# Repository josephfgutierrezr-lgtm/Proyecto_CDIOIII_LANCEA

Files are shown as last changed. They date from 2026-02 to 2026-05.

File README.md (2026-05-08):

# 🎯 Proyecto LANCEA: Jabalina Inteligente (CDIO III)

> 🌐 **¡Descubre la presentación interactiva!** 
> Visita la **[Página Oficial del Proyecto LANCEA](https://josephfgutierrezr-lgtm.github.io/Proyecto_CDIOIII_LANCEA/)** para ver el resumen técnico, la arquitectura del sistema y el equipo de desarrollo.

¡Bienvenidos al repositorio oficial del **Proyecto LANCEA**! 

Este espacio documenta el desarrollo integral de un dispositivo deportivo inteligente enfocado en el atletismo. Aquí encontrarás desde la gestión del proyecto hasta los manuales técnicos, hardware, firmware y el entorno de visualización de datos.

---

## 🚀 ¿Qué es LANCEA?
**LANCEA** es un dispositivo electrónico embebido diseñado para integrarse en una jabalina deportiva. Su propósito principal es capturar, procesar y transmitir datos biomecánicos y cinemáticos en tiempo real durante el lanzamiento. 

Al transformar un implemento deportivo tradicional en una herramienta de análisis de datos, LANCEA busca proporcionar retroalimentación cuantitativa para mejorar la técnica y el rendimiento de los atletas.

## 💡 Motivación y Justificación
El deporte de alto rendimiento exige precisión. Tradicionalmente, el análisis del lanzamiento de jabalina depende de la observación visual o de costosos sistemas de cámaras externas. LANCEA nace de la necesidad de democratizar el acceso a métricas precisas (aceleración, rotación, ángulos de ataque) integrando sensores directamente en el implemento. Esto permite una recolección de datos intrusiva mínima y un análisis de sistemas dinámicos mucho más cercano a la realidad física del atleta.

## 🎯 Objetivos
*   **Monitoreo Preciso:** Capturar datos de movimiento en múltiples ejes de manera continua durante la fase de aceleración y vuelo.
*   **Procesamiento Eficiente:** Integrar hardware de bajo consumo y alto rendimiento capaz de procesar la información sin latencia.
*   **Diseño Ergonómico:** Lograr que la adición del hardware no altere significativamente el centro de masa ni la aerodinámica natural de la jabalina.

## 🛠️ Retos Superados y Logros Técnicos
El desarrollo de hardware embebido para un entorno de alto impacto y velocidad presentó desafíos únicos:

*   **Optimización de Espacio y Peso:** Para mantener la integridad aerodinámica y el balance de la jabalina, el diseño prescindió de módulos de registro de datos en tarjeta SD. Esta decisión fue crucial para priorizar la reducción de peso y optimizar el espacio interno disponible.
*   **Comunicación de Sensores:** Se logró una integración exitosa de la unidad de medición inercial (IMU) BNO055. El núcleo de procesamiento se consolidó utilizando el microcontrolador ESP32-C3 SuperMini, estableciendo una comunicación I2C estable a través de los pines físicos 8 (SDA) y 9 (SCL).

## 📂 Estructura del Repositorio
El proyecto está organizado en las siguientes carpetas principales para separar el hardware, el software y la documentación de gestión:

*   📁 **`0_1 Gestion`**: Contiene toda la documentación administrativa del proyecto, incluyendo actas de reuniones, cronogramas, listas de materiales (BOM), costos y planeación maestra de las fases CDIO.
*   📁 **`0_2 Firmware`**: Código fuente desarrollado en C/C++ para el ESP32-C3 SuperMini. Incluye las librerías y rutinas necesarias para la lectura del IMU BNO055 vía I2C y el procesamiento de los datos inerciales.
*   📁 **`DASHBOARD`**: Archivos y scripts relacionados con la interfaz gráfica o panel de control utilizado para visualizar e interpretar los datos cinemáticos capturados por la jabalina.
*   📁 **`DEFINITION_DONE`**: Documentación sobre los criterios de aceptación (DoD - *Definition of Done*), estableciendo los requisitos de calidad y funcionalidad que debe cumplir cada entregable o módulo del proyecto.
*   📁 **`Hardware`**: Planos electrónicos, esquemas de conexión y diseño de integración física de los componentes, garantizando el balance y peso óptimo sin el módulo SD.
*   📁 **`PROTOCOLO_PRUEBAS`**: Procedimientos, metodologías y registros de validación utilizados para someter el dispositivo a pruebas de impacto, estabilidad de conexión y fiabilidad de captura de datos.
*   📁 **`Plantilla_checklist`**: Formatos y listas de chequeo estandarizadas para el control de calidad durante el ensamblasje del hardware y la revisión del código.

---
*¡Explora los directorios, revisa el código y descubre cómo la electrónica y el deporte se unen en LANCEA!*

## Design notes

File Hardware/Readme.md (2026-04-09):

# 🔧 Diseño de Hardware y Aviónica - LANCEA

Este directorio documenta la arquitectura electrónica, el diseño de PCB y la integración mecánica del sistema LANCEA. El hardware está diseñado bajo restricciones de **aerodinámica** (factor de forma cilíndrico <22mm) y **resistencia a impactos** (fuerzas >15g).

---

## 📐 Vista General del Dispositivo.

El sistema se compone de una **PCB tipo "Strip" (Regla)** de doble cara montada sobre un chasis amortiguado ("Sled") impreso en 3D.

[Render del Dispositivo Electrónico]([render_preview png](https://github.com/user-attachments/assets/35435e63-3988-4843-8b94-5bf8a7de0638))

### Especificaciones Físicas.
* **Dimensiones PCB:** 110mm x 20mm.
* **Diámetro del Chasis (Sled):** 24mm (ajustable según jabalina).
* **Peso Total (con batería):** ~45g.
* **Centro de Gravedad:** Ajustado al eje longitudinal para no alterar el vuelo.

---

## ⚡ Diagrama de Arquitectura.

El sistema utiliza una arquitectura de bus dual (I2C + SPI) para separar la adquisición de sensores (baja latencia) del almacenamiento masivo.

```mermaid
graph TD
    BMS[TP4056<br>Carga y Protección] --- BAT[Batería Li-ion 18650<br>3.7V / 2800mAh]
    BAT --> SW[Interruptor]
    SW --> LED[LED ON/OFF]
    LED --> ESP32[MCU:<br>XIAO ESP32C3<br>3.3V logging]
    
    subgraph I2C Bus [Sensores]
        ESP32 -- GPIO 6/7 --> BNO[IMU:<br>BNO055 / MPU6050<br>Acelerómetro + Giroscopio]
    end
    
    subgraph Interfaz Fisica [Interfaz Física]
        ESP32 -- GPIO 2 --> Buzzer[Buzzer]
    end

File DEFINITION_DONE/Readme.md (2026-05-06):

# 🚀 Definition of Done (DoD) — Proyecto LANCEA
**Versión:** 3.0 (Final) | **Fecha de actualización:** 2026-05-06
**Estado:** Finalizado y Consolidado | **Autor:** Joseph Fernando Gutierrez Reyes

---

## 🎯 Criterios de Aceptación Globales
Todos los módulos e iteraciones han cumplido estrictamente con los siguientes requisitos transversales para su consolidación final:

| # | Criterio | Estándar de Verificación | Estado |
|---|---|---|:---:|
| 1 | **Integridad del Firmware** | Compilación en entorno de producción sin *warnings*. | ✅ |
| 2 | **Validación Física** | Superación del protocolo de pruebas industrial con registro definitivo en `Bitacora_Trazabilidad.csv`. | ✅ |
| 3 | **Flujo de Git** | Pull Requests aprobados y fusionados en `main`. Commits bajo el estándar *Conventional Commits*. | ✅ |
| 4 | **Revisión de Pares** | Visto bueno técnico final por parte del asesor y validación de los miembros del equipo. | ✅ |
| 5 | **Sincronización Kanban** | Todas las tareas en estado "Done" en GitHub Projects con documentación y evidencia de integración adjunta. | ✅ |

---

## 🛠️ Criterios Técnicos Específicos Cumplidos

### 1. Firmware & Adquisición (FW)
Se garantizó la estabilidad del sistema embebido y la confiabilidad de la captura de señales cinemáticas tras las optimizaciones finales.

| Ref | Requisito Técnico | Parámetro de Éxito Alcanzado | Estado |
|---|---|---|:---:|
| **FW-01** | **Precisión Temporal** | Tasa de muestreo de 100Hz constante mediante **ISR (Interrupt Service Routine)**. Jitter (σ) < 1ms. | ✅ |
| **FW-02** | **Detección de Eventos** | Algoritmo de trigger por *Jerk* calibrado (> 50 m/s³) para inicio automático de captura de telemetría. | ✅ |
| **FW-03** | **Gestión de Memoria** | Estructuración de datos optimizada en memoria tras la decisión técnica de remover el módulo de tarjeta SD, reduciendo peso y evitando bloqueos de escritura. | ✅ |

### 2. Hardware & Integración Mecánica (HW)
Se validó la resistencia, el balance del centro de gravedad aerodinámico y el diseño electrónico del prototipo definitivo.

| Ref | Requisito Técnico | Parámetro de Éxito Alcanzado | Estado |
|---|---|---|:---:|
| **HW-01** | **Ajuste Mecánico** | Chasis Sled (PETG) con **O-Rings de compresión** instalados. Ajuste estructural sin vibración radial dentro del tubo. | ✅ |
| **HW-02** | **Dimensionamiento** | Ancho de PCB Strip ≤ 20mm insertada en la jabalina (Ø 24mm). Bus I2C operando correctamente en pines físicos 8 (SDA) y 9 (SCL) del ESP32-C3. | ✅ |
| **HW-03** | **Estabilidad de Voltaje** | Capacitores de desacoplo (100µF/0.1µF) instalados en la línea VCC principal para mitigar picos de consumo entre el microcontrolador y el sensor BNO055. | ✅ |

### 3. Sistema Integrado & Operación (MC)
Desempeño del sistema completo validado en pista, garantizando la recolección de datos y el flujo de energía.

| Ref | Requisito Técnico | Parámetro de Éxito Alcanzado | Estado |
|---|---|---|:---:|
| **MC-01** | **Autonomía y Recarga** | Operación continua validada (> 7 horas continuas). Módulo TP4056 plenamente accesible desde la sección trasera mediante USB-C sin necesidad de desmontar el chasis. | ✅ |
| **MC-02** | **Trazabilidad de Datos** | Paquetes de datos exportados con estructura matricial legible, sin huecos (gaps) y listos para su modelado y análisis en MATLAB. | ✅ |
| **MC-03** | **Feedback de Usuario** | Sistema de alertas sonoras (Buzzer) y visuales (LED de carga) funcional para indicar: Inicializado, Calibrado, Grabación en curso y Estado de Batería. | ✅ |

---

## 🏁 Cierre de Proyecto y Conformidad
El proyecto LANCEA se declara **Terminado y Consolidado**. No existen tareas pendientes, bloqueos técnicos ni implementaciones de hardware/firmware sin validar. Todos los criterios de exclusión históricos (código sin probar dinámicamente, alteraciones del punto de equilibrio, falta de protecciones antivibración o bloqueos por funciones como `delay()`) fueron mitigados satisfactoriamente, culminando en un prototipo funcional y listo para la recolección de datos en campo.

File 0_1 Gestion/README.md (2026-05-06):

# 📂 Gestión del Proyecto LANCEA:

Este directorio centraliza la documentación administrativa, planificación y análisis de requisitos del sistema **LANCEA** (Sistema de Monitoreo y Detección de Lanzamiento de Jabalina).

**Institución:** Universidad del Quindío.
**Programa:** Ingeniería Electrónica (Séptimo Semestre)  
**Ubicación:** Armenia, Quindío, Colombia.   
**Duración:** 2 Semestres (Fase I y II).
---

## 🎯 Alcance del Proyecto:

El objetivo es desarrollar un dispositivo embebido portátil capaz de medir parámetros cinemáticos críticos durante el entrenamiento de lanzamiento de jabalina.

### Objetivos Específicos (KPIs)
1.  **Captura de Aceleración:** Medición en 3 ejes con rango de $\pm16~g$.
2.  **Cálculo de Velocidad:** Estimación de velocidad de salida entre 15m/s y 35m/s.
3.  **Estimación de Distancia:** Proyección teórica del tiro entre 35m y 90m.
4.  **Autonomía:** Operación continua $\ge 6$ horas sin recarga.
5.  **Costo:** Presupuesto total entre \$800k y \$1.2M COP.

---

## 📅 Roadmap de Implementación:

El proyecto se divide en dos fases semestrales según los lineamientos académicos:

### Fase 1: Hardware y Firmware Base (Semestre Actual)
| Semanas | Hito / Entregable | Estado |
| :--- | :--- | :--- |
| **1-4** | Adquisición de componentes y Setup inicial del ESP32. |🟢 Hecho |
| **5-8** | Integración de sensores (IMU/Velocidad), detección de evento y Pantalla OLED. |  🟢 Hecho |
| **9-12** | Implementación de almacenamiento local (MicroSD/SPIFFS). |🟢 Hecho |
| **13-16** |Pruebas de campo, calibración de sensibilidad y documentación final. | 🟢 Hecho |

### Fase 2: Conectividad y Servidor (Próximo Semestre)
* Despliegue de servidor local (Python/Flask).
* Sincronización WiFi y Base de Datos.
* Interfaz Web para visualización de historial.

---
## ⚙️ Matriz de Requisitos

### Requisitos Funcionales (RF)
* **RF-001:** Captura de aceleración ($\pm16g$, $\pm0.5~m/s^2$).
* **RF-002:** Captura de velocidad de lanzamiento.
* **RF-004:** Detección automática del evento de lanzamiento.
* **RF-005:** Almacenamiento local ("Black Box") para mín. 30 lanzamientos.
* **RF-006:** Transmisión asíncrona ("Store & Forward") al servidor.
* **RF-007:** Visualización inmediata de resultados en pantalla OLED.

### Requisitos No Funcionales (RNF)
* **RNF-003 Portabilidad:** Peso total $\le 1.5$ kg e integración aerodinámica.
* **RNF-005 Resistencia Ambiental:** Operación en clima de Armenia ($15^\circ C - 35^\circ C$, Humedad 60-95%).
* **RNF-012 Recuperabilidad:** Sistema "Offline-First" ante fallos de red WiFi.

---

## 💰 Presupuesto y Recursos

**Presupuesto Estimado:** \$800.000 - \$1.200.000 COP.

### Componentes Principales (BOM)
* **Microcontrolador:** ESP32 (Dual Core, WiFi/BT).
* **Sensores:** IMU BNO055 (Acelerómetro + Giroscopio). *Nota: Se utiliza IMU para cálculo de velocidad debido a limitaciones físicas del ultrasonido HC-SR04 en distancias >4m.*
* **Energía:** Batería LiPo/Li-Ion (3.7V).
* **Interfaz:** Pantalla OLED 0.91" (I2C) y Pulsador físico.

---

## ⚠️ Gestión de Riesgos y Restricciones
1.  **Conectividad:** La red WiFi en estadios no es garantizada. Se mitiga con almacenamiento en SD (RF-005).
2.  **Clima:** La alta humedad de Armenia requiere protección IP54 o uso de Silica Gel en la carcasa.
3. **Vibración:** El impacto de la jabalina requiere amortiguación interna en el chasis impreso en 3D.

---
*Documento basado en la especificación de requisitos v1.0 (Octubre 2025).*

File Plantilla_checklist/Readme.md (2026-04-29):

## CHECKLIST DE DEFINICIÓN DE HECHO (DoD) - LANCEA

Antes de cerrar esta tarea y moverla a "Done", certifico como ingeniero a cargo que he validado lo siguiente en el prototipo base:

### ⚡ 1. HARDWARE
- [x] **Esquemático/PCB:** Actualizado en la carpeta `02_Hardware` sin errores de reglas de diseño (0 Errores DRC).
- [x] **Continuidad:** La placa pasó la prueba de cortos (0 cortos en pistas de potencia y buses I2C/SPI).
- [x] **Cero Parches:** No hay cables "voladores"; las conexiones del BNO055 están ruteadas o soldadas firmemente.
- [x] **Métricas:** El módulo TP4056 entrega voltaje de carga estable y el ESP32 recibe sus 3.3V lógicos dentro de la tolerancia exigida.

### 💻 2. FIRMWARE/SOFTWARE
- [x] **Compilación limpia:** El código de prueba (Hola Mundo) compila con 0 Errores y 0 Warnings en PlatformIO/Arduino.
- [x] **Código No-Bloqueante:** No se usa la función `delay()` que detenga la adquisición de datos de la IMU.
- [x] **Repositorio:** El código está subido a la rama principal de GitHub (Push realizado).
- [x] **Trazabilidad:** El Commit incluye la palabra clave para cerrar esta tarea (Ej: `Closes #ID`).

### ⚙️ 3. MECÁNICA / DISEÑO 3D
- [x] **Archivos Fuente:** El diseño base del chasis cilíndrico ("Sled") está en la subcarpeta `Mechanical/`.
- [x] **Archivos de Fabricación:** El `.STL` final está subido y listo para imprimir en PETG/PLA+.
- [x] **Tolerancia:** Se validó matemáticamente que la PCB tipo "Strip" (20mm de ancho) cabe perfectamente en el diámetro interno de 24mm diseñado para la jabalina.

### 📋 4. GESTIÓN Y PRUEBAS
- [x] **BOM Actualizado:** Todos los componentes adquiridos (ESP32, BNO055, TP4056, Batería 14500) están costeados en la Lista de Materiales.
- [x] **Protocolo de Pruebas:** Se diligenció el archivo Excel Oficial de Pruebas (Test Report) para los subsistemas actuales.
- [x] **Aprobación:** La columna de "Estado Final" en el Excel de pruebas dice "✅ PASS" con datos reales (sin subjetividades).

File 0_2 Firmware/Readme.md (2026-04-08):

# ⚡ Firmware LANCEA (ESP32 Core)

Este directorio contiene el código fuente C++ para el microcontrolador XIAO ESP32C3. El firmware implementa la lógica de adquisición de datos de alta velocidad, gestión de almacenamiento y transmisión inalámbrica bajo una arquitectura de **Máquina de Estados Finitos (FSM)**.

---

## 🛠️ Entorno de Desarrollo
En esta sección se definen las herramientas, plataforma y dependencias necesarias para compilar, cargar y mantener el firmware del sistema, lo cual asegura reproducibilidad en el entorno de desarrollo entre los miembros del equipo.

* **Platform:** PlatformIO (Recomendado) o Arduino IDE.
* **Framework:** Arduino.
* **Board:** `lolin_s2_mini` / `esp32dev` (Ajustar según hardware real).

### Dependencias (Librerías)
Las siguientes librerías son obligatorias para compilar el proyecto y permiten la correcta interacción con los sensores, pantalla y sistema de almacenamiento:
1.  **Adafruit BNO055** (Driver del sensor IMU).
2.  **Adafruit Unified Sensor** (Base para sensores Adafruit).
3.  **Adafruit SSD1306** (Controlador de Pantalla OLED).
4.  **Adafruit GFX** (Gráficos para pantalla).
5.  **SdFat** (Gestión optimizada de tarjeta SD via SPI).

---

## 🔌 Pinout (Mapa de Conexiones)

A continuación se presenta la asignación de pines utilizada en el sistema. Esta configuración está definida en el archivo config.h y es fundamental para garantizar la correcta conexión entre el microcontrolador y los periféricos.

| Pin XIAO ESP32-C3 | MPU6050 | BNO055 | Buzzer |
| :--- | :---: | :---: | :---: |
| **3V3** | VCC | VCC | -- |
| **GND** | GND | GND | GND |
| **D4 (GPIO6)** | SDA | SDA | -- |
| **D5 (GPIO7)** | SCL | SCL | -- |
| **D3 (GPIO5)** | INT | -- | -- |
| **D6 (GPIO21)** | -- | -- | SIGNAL |
| **GND** | AD0 | ADR | -- |

## 🧠 Lógica del Sistema (Arquitectura)
En esta sección se describe el comportamiento del firmware a nivel lógico, el sistema no opera mediante un bucle tradicional, sino mediante una Máquina de Estados Finitos (FSM), lo que permite controlar de forma estructurada los eventos, optimizar recursos y garantizar la integridad de los datos durante el proceso de adquisición.

### Diagrama de Flujo de Estados

```mermaid
stateDiagram-v2
    [*] --> INIT
    INIT --> ERROR : Fallo en Sensor/SD
    ERROR --> [*]
    INIT --> IDLE : Todo OK
    
    IDLE --> ARMADO : Pulsación Corta Botón
    ARMADO --> GRABANDO : Aceleración > 4G (Lanzamiento)
    
    state GRABANDO {
        [*] --> LOGGING
        LOGGING --> LOGGING : 100Hz Loop
    }
    
    GRABANDO --> GUARDADO : Tiempo > 10s o Silencio
    GUARDADO --> IDLE : Archivo Cerrado
    
    IDLE --> WIFI_SYNC : Pulsación Larga Botón (3s)
    WIFI_SYNC --> IDLE : Carga Completa

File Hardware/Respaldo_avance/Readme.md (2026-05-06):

# 🔬 Pruebas de Concepto (PoC) - Semestre Anterior

Este documento recopila la investigación preliminar y las validaciones en hardware realizadas durante la fase de viabilidad del proyecto **LANCEA**. Estos resultados justifican la arquitectura técnica actual del sistema.

---

## 📐 1. Validación Dimensional y Mecánica

Uno de los mayores retos del proyecto era asegurar que la electrónica pudiera operar dentro de las estrictas restricciones aerodinámicas de un tubo deportivo, sin alterar el centro de gravedad.

### Objetivo de la Prueba
Validar que es posible ensamblar un sistema de adquisición de datos en una PCB con un ancho útil inferior al diámetro interno de una jabalina estándar.

### Resultados
Se logró diseñar e integrar un prototipo funcional que respeta el factor de forma cilíndrico, asegurando que la baquelita y la batería se deslizan sin tensión mecánica dentro del diámetro de prueba (aprox. 24mm - 25mm).

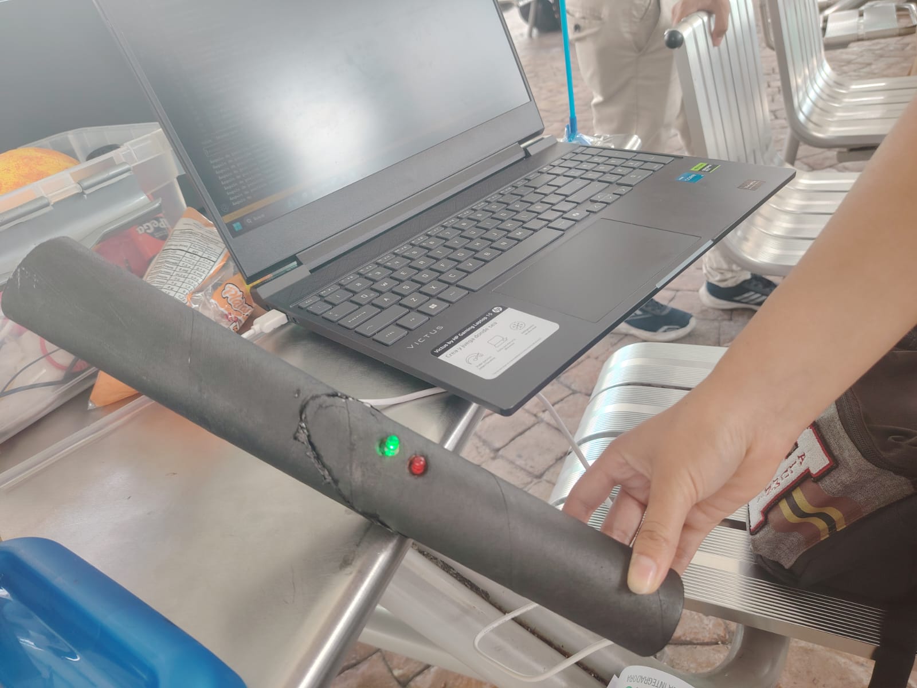
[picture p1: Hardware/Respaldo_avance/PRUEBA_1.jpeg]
Prueba de Diámetro y Ensamble


---

## ⚡ 2. Medición de Ángulo y Autonomía Energética

Para capturar la cinemática del vuelo, era crítico probar la viabilidad de estimar ángulos usando sensores inerciales y garantizar que el sistema de energía soportara una sesión completa de entrenamiento.

### Objetivo de la Prueba
1.  **Cinemática:** Leer el ángulo de inclinación estático utilizando un sensor MPU6050 inicial.
2.  **Energía:** Medir la tasa de descarga del sistema completo operando de forma continua.

### Resultados
* **Ángulo:** Se obtuvieron lecturas coherentes de inclinación (Pitch/Roll) procesando los datos crudos del sensor en el microcontrolador.
* **Autonomía:** El sistema demostró una operación continua superior a las expectativas iniciales utilizando celdas de Li-Ion, validando que una sola carga es suficiente para múltiples horas de recolección de datos en campo.

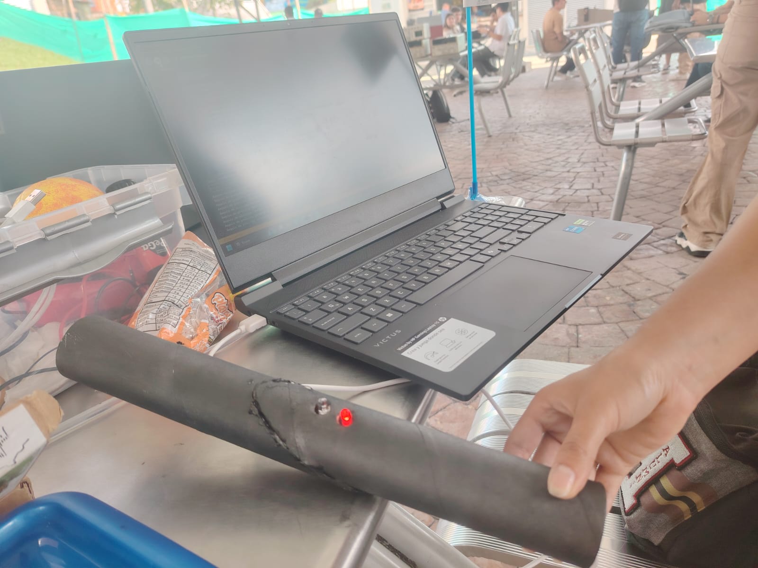
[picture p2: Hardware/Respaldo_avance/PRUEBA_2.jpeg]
Prueba de Ángulo y Autonomía


---

## 🚀 Conclusión y Transición a Fase 2

Los resultados exitosos de estas pruebas preliminares permitieron:
1.  Confirmar la viabilidad física del chasis impreso en 3D ("Sled").
2.  Justificar el *upgrade* del sensor MPU6050 al **BNO055** actual, para obtener cuaterniones por hardware y evitar el "Gimbal Lock" en vuelos dinámicos.
3.  Establecer la arquitectura de energía final basada en baterías 14500/18650 con gestión TP4056.

Estos antecedentes son la base sobre la cual se está desarrollando el firmware y hardware de alta velocidad de la versión actual.

---

## 🛠️ 3. Implementación Actual (Fase 2)

A partir de las conclusiones de las pruebas de concepto, se procedió a la materialización del hardware definitivo, logrando integrar con éxito las mejoras propuestas:

### Ensamble de PCB Definitiva
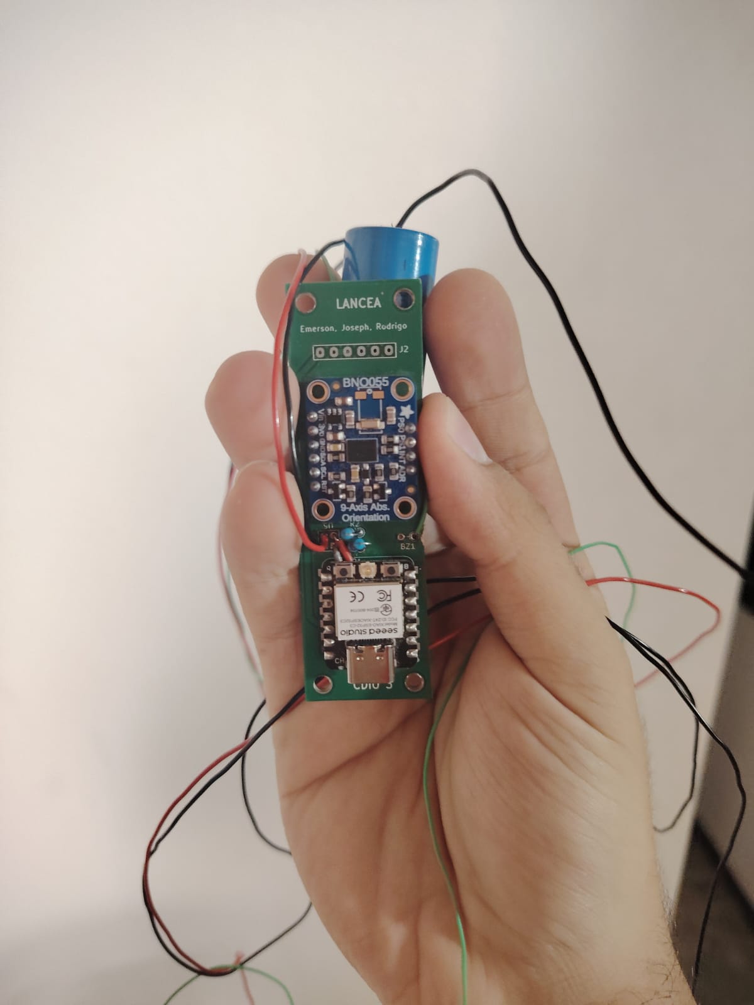
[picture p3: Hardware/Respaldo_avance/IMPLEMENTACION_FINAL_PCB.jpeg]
Implementación Final PCB

* **Avance:** Montaje exitoso de la PCB principal en formato "Strip". Se consolida el salto tecnológico integrando el microcontrolador **XIAO ESP32-C3** y el sensor inercial **BNO055** de alta precisión, respetando estrictamente el ancho máximo permitido por el diámetro interno de la jabalina.

### Integración Estructural del Sistema de Energía
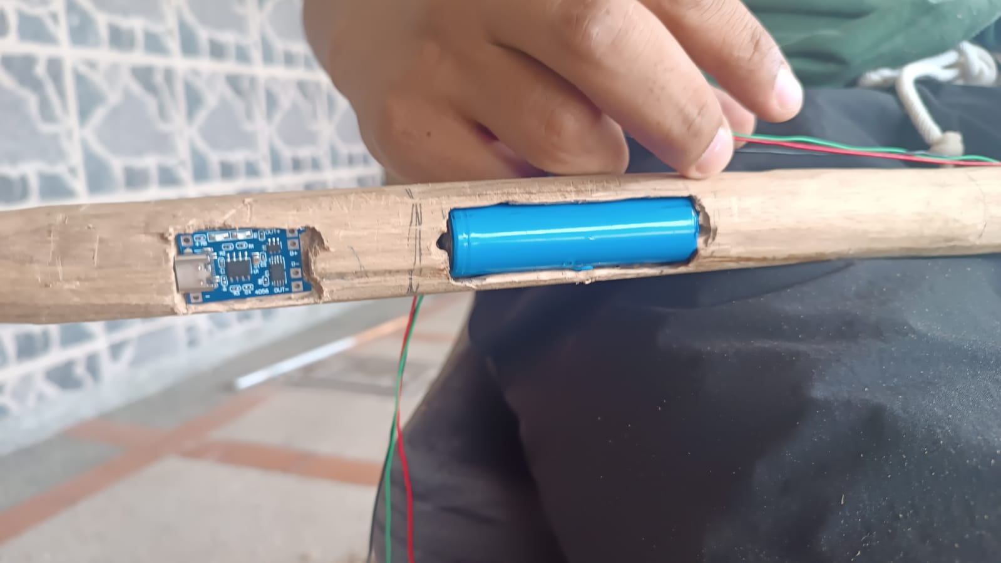
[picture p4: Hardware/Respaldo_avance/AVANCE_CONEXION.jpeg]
Avance de Conexión

* **Avance:** Mecanizado e integración del sistema de alimentación en un prototipo estructural (simulador de madera). Se comprueba el ajuste perfecto de la **batería Li-ion** y el módulo de carga **TP4056** en los compartimentos empotrados, garantizando que los componentes no sobresalgan del perfil cilíndrico ni comprometan la aerodinámica o el centro de masa del proyectil.

### Validación del Sistema de Carga Integrado
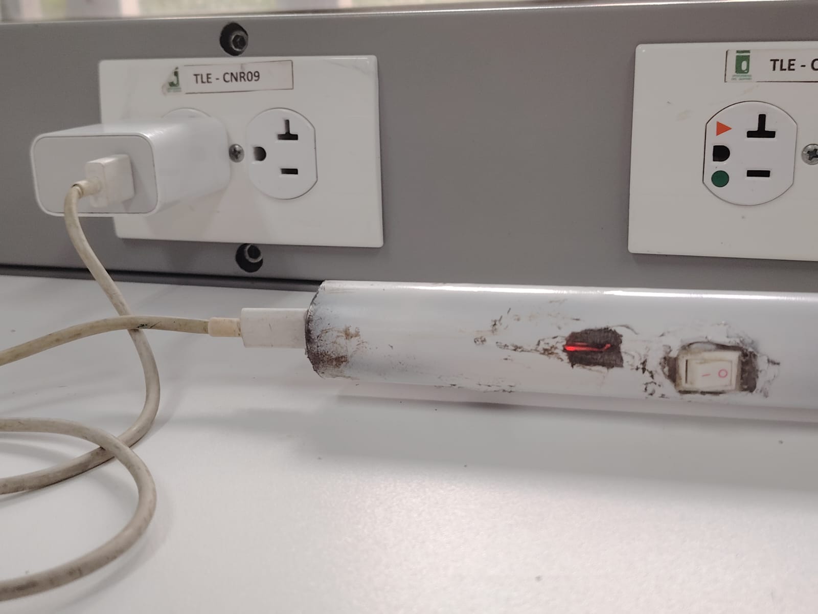
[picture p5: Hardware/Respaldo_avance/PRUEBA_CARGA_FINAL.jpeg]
Prueba de Carga Final

* **Avance:** Verificación funcional del módulo de gestión de energía operando directamente desde su alojamiento tubular. La prueba demuestra que la interfaz de carga es perfectamente accesible desde el exterior de la carcasa. El indicador LED rojo confirma el flujo de corriente activo hacia la batería, y se valida la accesibilidad del interruptor mecánico integrado para aislar el circuito principal en campo.

---

## 🎯 4. Trazabilidad y Ensamblaje Final

Como parte del cierre de la fase de integración, se realizaron las inspecciones físicas y estructurales sobre el dispositivo completamente ensamblado, verificando que las modificaciones de hardware cumplan con los requerimientos deportivos de la disciplina.

### Verificación del Punto de Equilibrio
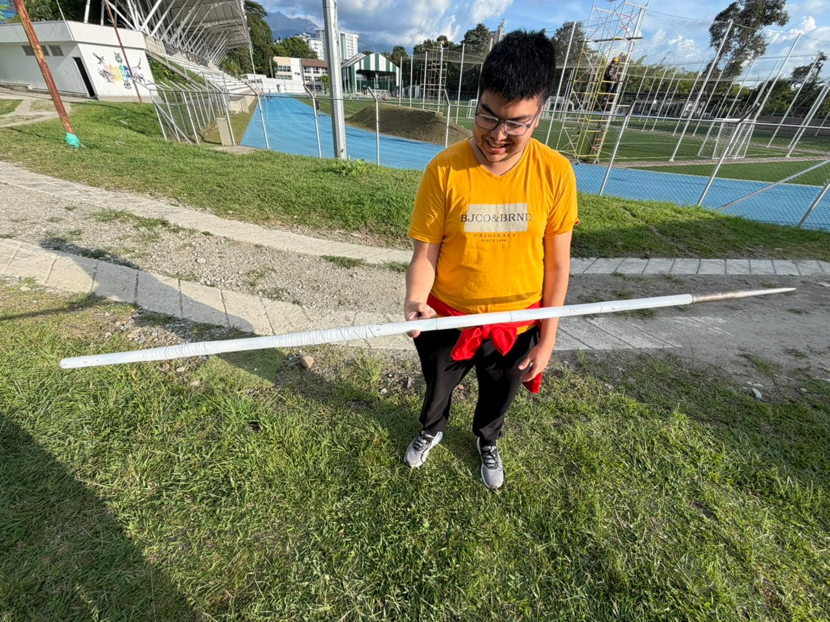
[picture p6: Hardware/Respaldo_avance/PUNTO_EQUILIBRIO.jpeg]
Punto de Equilibrio

* **Avance:** Comprobación exitosa del centro de gravedad de la jabalina. La distribución estratégica de los componentes internos, sumada a la decisión de retirar el módulo de registro de datos por tarjeta SD para optimizar el espacio y reducir el peso general, permitió mantener el balance aerodinámico estricto necesario para un vuelo estable.

### Accesibilidad del Módulo de Carga Trasero
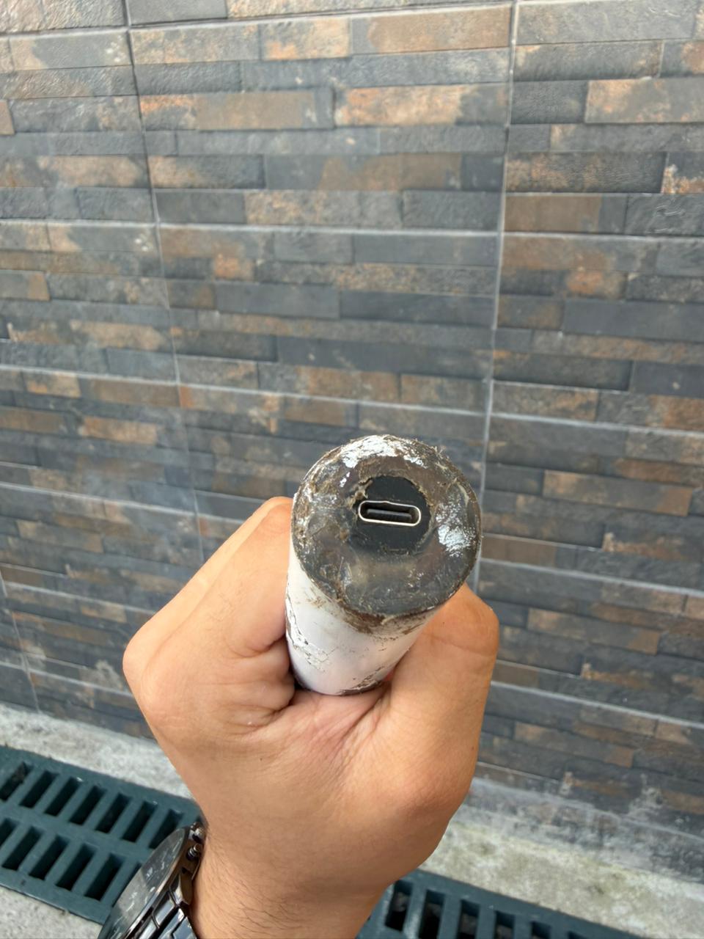
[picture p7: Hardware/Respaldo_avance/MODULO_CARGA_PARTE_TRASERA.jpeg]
Módulo de Carga Parte Trasera

* **Avance:** Integración del puerto de carga USB-C en la sección posterior de la jabalina. Este diseño expone la interfaz de recarga del módulo de energía de manera segura, facilitando la conexión mediante cables estándar entre sesiones de lanzamiento sin necesidad de manipular o desmontar la estructura principal.

### Consolidación del Prototipo LANCEA
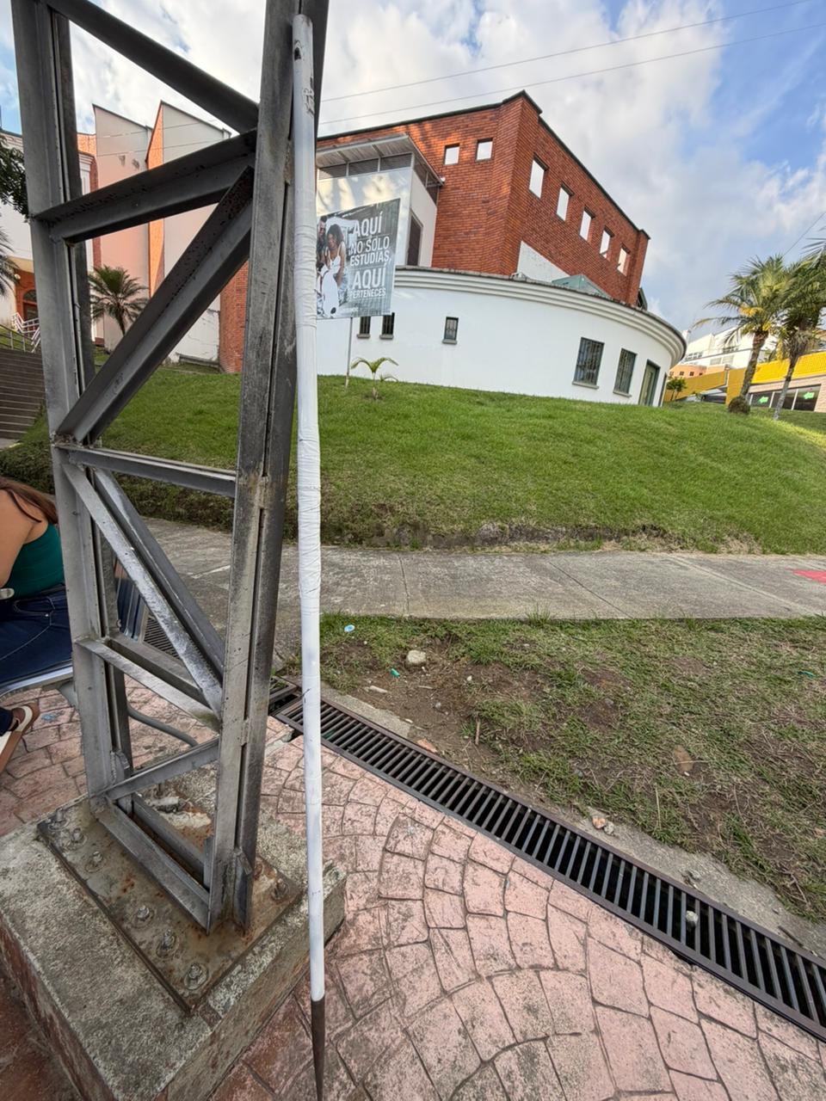
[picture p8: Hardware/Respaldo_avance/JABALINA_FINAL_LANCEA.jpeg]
Jabalina Final LANCEA

* **Avance:** Vista general del prototipo inteligente estructurado y sellado. El dispositivo presenta un perfil continuo y liso, confirmando que la instrumentación interna no compromete el factor de forma externo, dejando el equipo listo para la ejecución de pruebas dinámicas y recolección de datos en pista.

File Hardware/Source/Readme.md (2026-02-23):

# ⚡ Diseño Electrónico y PCB - LANCEA

Este directorio contiene los archivos fuente del diseño de la PCB para el proyecto.

## 🛠 Especificaciones
* **Software:** KiCad 9.0
* **Capas:** 2 capas
* **Tecnología:** Componentes Through-hole (THT) para mayor robustez mecánica.

## 📂 Estructura de Archivos
* **Esquemático:** `.kicad_sch` (Lógica del circuito).
* **PCB Layout:** `.kicad_pcb` (Diseño físico de la placa).
* **Proyecto:** `.kicad_pro` (Archivo maestro).
* **Librerías y 3D:** Carpetas de símbolos, huellas y modelos STEP.

## 📥 ¿Cómo descargar los archivos?

Si necesitas descargar un archivo individual (como el esquemático o la PCB) directamente desde el navegador:

1. Haz clic sobre el archivo que deseas (ej. `.kicad_pcb`).
2. En la esquina superior derecha de la vista del archivo, haz clic en los **tres puntos (`...`)**.
3. Selecciona la opción **Download**.
4. **Atajo de teclado:** También puedes presionar `Ctrl` + `Shift` + `S` mientras visualizas el código del archivo para guardarlo automáticamente.

> **Nota:** Se recomienda descargar todo el repositorio como un `.zip` desde la página principal para mantener la integridad de las librerías y modelos 3D.

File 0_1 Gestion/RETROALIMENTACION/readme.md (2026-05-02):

# Registro Integrado de Retroalimentación, Protocolos de Prueba y Definition of Done (DoD)
**Proyecto:** LANCEA - Sistema de Medición y Emulación para Atletas de Jabalina  
**Cliente / Usuario Final:** Entrenador y Atleta de la Liga de Atletismo del Quindío  
**Ingenieros a Cargo:** Joseph Fernando Gutiérrez, Emerson Santiago Córdoba, Johan Rodrigo Piedrahita

---

## 1. Introducción y Justificación
Este documento detalla cómo las necesidades empíricas y cualitativas del usuario final (entrenador y atleta de jabalina) fueron traducidas en requerimientos técnicos estrictos, historias de usuario medibles y validaciones cuantificables. El propósito de este registro es evidenciar que el desarrollo del dispositivo **LANCEA** siguió una ruta de ingeniería rigurosa (basada en métricas, metodologías ágiles y estándares industriales) descartando la improvisación y garantizando un producto funcional, ergonómico y preciso.

---

## 2. Historias de Usuario: La Voz del Cliente (Feedback)
El proceso de retroalimentación en campo nos permitió capturar las necesidades reales, las cuales fueron formalizadas en la **Matriz de Enfoque y Requisitos**:

* **HU-01 (Entrenador):** *Requiere ver la velocidad y ángulo de lanzamiento para corregir la técnica.* -> Prioridad P0. Define el uso del IMU y el procesamiento inercial.
* **HU-02 (Atleta):** *Exige que el sistema sea invisible dentro de la jabalina para no alterar su vuelo ni ergonomía.* -> Prioridad P0. Define los límites mecánicos del diseño, promoviendo la máxima reducción de peso y volumen.
* **HU-03 (Entrenador/Técnico):** *Necesita descargar datos en CSV sin cables y de forma inmediata para agilizar el análisis.* -> Prioridad P1. Se descartó el almacenamiento físico (memoria micro SD) para evitar problemas de espacio y peso adicional en la jabalina. En su lugar, se definió una arquitectura donde la información se envía y guarda directamente en archivos CSV desde la aplicación y la página web.
* **HU-04 (Investigación):** *Requiere un registro de 100 muestras/segundo para el análisis biomecánico.* -> Prioridad P0. Define la tasa de muestreo, rutinas de interrupción (ISR) y la transmisión estable de datos a la interfaz.
* **HU-05 (Usuario en campo):** *La batería debe durar al menos 6 horas para cubrir un entrenamiento completo.* -> Prioridad P1. Define el sistema de potencia.

---

## 3. Definition of Done (DoD): Estándares de Aceptación
Para asegurar que las decisiones tomadas cumplieran con la calidad exigida y no fueran validaciones subjetivas (ej. "funciona bien"), se estableció un **Definition of Done (DoD)** riguroso:

1.  **Cero Subjetividad:** Todas las validaciones deben arrojar valores numéricos (Voltios, Milímetros, Grados, Milisegundos).
2.  **Firmware (FW) y Software:** 
    * Tasa de muestreo de **100Hz exacta** garantizada por ISR (Interrupt Service Routine) con Jitter < 1ms, evitando el uso de retardos (`delay()`) que bloqueen la lectura.
    * Detección de lanzamiento por **Jerk calibrado (> 50 m/s³)**.
    * Transmisión íntegra de datos vía Wi-Fi (ESP32 como servidor local/AP) hacia la aplicación/página web para la generación automática del archivo CSV, garantizando cero pérdida de paquetes y eliminando la dependencia de hardware de almacenamiento extra (SD).
3.  **Hardware (HW) y Mecánica:** 
    * Ancho máximo de la PCB **≤ 20mm**.
    * Eliminación del módulo SD y sus componentes asociados, reduciendo drásticamente el peso y volumen final.
    * Uso de **O-Rings de compresión** en el chasis (Sled) de PETG para evitar vibración radial e impactos.
4.  **Sistema e Interacción (MC):** 
    * Feedback al usuario mediante **Buzzer** (alertas sonoras para encendido, calibración y conexión/grabación exitosa), solucionando la necesidad de interacción rápida.

---

## 4. Ejecución de Pruebas Industriales (Verificación de Requisitos)
Las historias de usuario y el DoD se validaron mediante los siguientes protocolos de prueba documentados, a cargo del ingeniero Joseph Gutierrez:

### 🛠️ Prueba Mecánica y Dimensional (TEST-MC-01 & TEST-HW-01)
* **Problema del Atleta (HU-02):** El dispositivo debe encajar perfectamente sin estorbar y ser lo más ligero posible.
* **Protocolo:** Se midió el diámetro interno de una jabalina profesional con calibrador Pie de Rey, obteniendo **25.2mm** (TEST-MC-01). 
* **Validación de PCB:** Gracias a la eliminación de la memoria SD, se optimizó la baquelita en KiCad definiendo un límite estricto. La medición final del ancho de la placa fue de **19.8mm** (TEST-HW-01). 
* **Resultado:** ✅ **PASS**. Se garantiza el encaje aerodinámico perfecto y se minimiza el peso añadido al implemento.

### 🔋 Prueba de Autonomía de Potencia (TEST-HW-02)
* **Problema del Usuario (HU-05):** El sistema debe durar una sesión de 6 horas.
* **Protocolo:** Se testeó una batería Li-Ion 14500 (1000mAh) con el ESP32 en modo activo continuo, transmitiendo datos vía web/app hasta el corte del BMS (3.0V).
* **Resultado:** ✅ **PASS**. El sistema operó ininterrumpidamente por **7 horas y 15 minutos**, superando holgadamente la exigencia.

### 📐 Prueba de Calibración Inercial (TEST-FW-01)
* **Problema del Entrenador (HU-01):** Confianza en los ángulos reportados en el archivo CSV generado.
* **Protocolo:** Uso de escuadra física a 45° en estático. La interfaz web/app debía registrar el ángulo con un error máximo de ±2°.
* **Resultado:** ✅ **PASS**. Lectura estable entre **44.5° y 45.1°**.

---

## 5. Conclusión: Trazabilidad del Proyecto
El cruce entre los comentarios del cliente, la Matriz de Requisitos, el Definition of Done y el Protocolo de Pruebas demuestra una **trazabilidad completa y profesional**. Cada decisión de diseño —como la transmisión y generación remota de archivos CSV para prescindir del módulo SD y alivianar el peso, la implementación de ISR a 100Hz, alertas sonoras con Buzzer, y el dimensionamiento estricto a 19.8mm de la PCB— se fundamentó directamente en los comentarios del entrenador y el atleta.

Se evidencia que LANCEA no es el resultado de la experimentación empírica, sino de un proceso sistemático de ingeniería que asegura confiabilidad, precisión de datos y usabilidad en el entorno real de alto rendimiento deportivo del Quindío.

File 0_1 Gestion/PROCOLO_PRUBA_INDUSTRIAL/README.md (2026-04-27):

# Protocolo de Pruebas Industrial — Proyecto LANCEA
**Versión:** 2.1 | **Fecha de actualización:** 2026-04-27
**Equipo:** Joseph Fernando Gutiérrez · Emerson Santiago Córdoba · Johan Rodrigo Piedrahita

> ⚠️ Este protocolo ha sido diligenciado y ejecutado. Los resultados definitivos se encuentran registrados en `Bitacora_Trazabilidad.csv`.

---

## TEST-HW-01-A — Validación Dimensional PCB (KiCad)
**Prioridad:** P1 Alto | **Requisito:** REQ-HW-01 | **Estado:** ✅ PASS

| Campo | Detalle |
|---|---|
| Objetivo | Validar que el ancho de la PCB permita encaje aerodinámico dentro del Sled (Ø 24mm) |
| Setup | Software KiCad 7.0, Diseño 3D del chasis Sled |
| Pasos | 1. Trazar bordes de corte (Edge.Cuts) · 2. Medir ancho máximo en KiCad · 3. Comparar con Ø interno del Sled (24mm) |
| Input | Ancho máx objetivo: ≤ 20mm |
| Resultado Esperado | Placa virtual ≤ 20mm de ancho |
| Resultado Obtenido | **19.8mm** ✅ |
| Responsable | Joseph Gutiérrez |

---

## TEST-FW-01-A — Validación Ángulo IMU (Estático)
**Prioridad:** P0 Crítico | **Requisito:** REQ-FW-01 | **Estado:** ✅ PASS

| Campo | Detalle |
|---|---|
| Objetivo | Validar lectura de ángulo de inclinación (Pitch/Roll) del BNO055 en condición estática |
| Setup | ESP32-C3, BNO055, Protoboard, Monitor Serial 115200 baud, Escuadra física 45° |
| Pasos | 1. Flashear firmware I2C · 2. Posicionar sensor a 0° plano · 3. Inclinar a 45° sobre escuadra · 4. Registrar lectura |
| Input | Baudrate: 115200 · Ángulo físico: 45° exactos |
| Resultado Esperado | Lectura en Monitor Serial: 45° ± 2° |
| Resultado Obtenido | **44.5° – 45.1°** ✅ |
| Responsable | Joseph Gutiérrez |

---

## TEST-MC-01-A — Validación de Autonomía
**Prioridad:** P0 Crítico | **Requisito:** REQ-HW-02 | **Estado:** ✅ PASS

| Campo | Detalle |
|---|---|
| Objetivo | Validar tiempo de operación continua con batería Li-Ion 14500 |
| Setup | Batería 14500 (1000mAh) al 100%, ESP32 en modo activo, Cronómetro |
| Pasos | 1. Conectar batería al circuito · 2. Registrar hora de inicio · 3. Monitorear hasta corte BMS (V_min = 3.0V) |
| Input | Consumo estimado: ~120mA · V_corte: 3.0V |
| Resultado Esperado | ≥ 6 horas de operación continua |
| Resultado Obtenido | **7 horas 15 minutos** ✅ |
| Responsable | Joseph Gutiérrez |

---

## TEST-HW-01-B — Inspección Dimensional Jabalina
**Prioridad:** P1 Alto | **Requisito:** REQ-HW-01 | **Estado:** ✅ PASS

| Campo | Detalle |
|---|---|
| Objetivo | Confirmar que el diámetro interno de la jabalina acepta el chasis Sled |
| Setup | Jabalina de entrenamiento profesional, Calibrador Pie de Rey |
| Pasos | 1. Revisar punto de inserción · 2. Medir diámetro interno con Pie de Rey · 3. Comparar con ancho del Sled |
| Input | Diámetro mínimo requerido: > 24mm |
| Resultado Esperado | Diámetro interno > 24mm |
| Resultado Obtenido | **25.2mm** — holgura suficiente ✅ |
| Responsable | Joseph, Rodrigo, Emerson |

---

## TEST-FW-02 — Validación Tasa de Muestreo 100Hz
**Prioridad:** P1 Alto | **Requisito:** REQ-FW-01 | **Estado:** ✅ PASS (Corregido)

| Campo | Detalle |
|---|---|
| Objetivo | Confirmar que el firmware logra exactamente 100Hz en la grabación de datos |
| Setup | Firmware de producción, función `micros()` del ESP32 |
| Pasos | 1. Iniciar grabación · 2. Almacenar 1000 muestras · 3. Calcular Δt entre muestras en CSV · 4. Calcular desviación estándar |
| Input | Target: 10ms por muestra (Δt = 10000 µs) |
| Resultado Esperado | σ(Δt) < 1ms |
| Resultado Obtenido | **σ(Δt) < 1ms — Jitter eliminado exitosamente (Adquisición independiente mediante ISR implementada)** ✅ |
| Responsable | Joseph Gutiérrez |

---

## TEST-MC-01-B — Validación Integridad Datos SD/SPI
**Prioridad:** P0 Crítico | **Requisito:** REQ-MC-01 | **Estado:** ✅ PASS (Corregido)

| Campo | Detalle |
|---|---|
| Objetivo | Validar que la escritura en MicroSD no interfiera ni corrompa la lectura del IMU BNO055 |
| Setup | Sled ensamblado completo, Batería 14500 al 100% |
| Pasos | 1. Activar sistema · 2. Realizar movimientos en 3 ejes durante 30s · 3. Extraer SD · 4. Graficar datos en Python |
| Input | Duración de estrés: 30 segundos |
| Resultado Esperado | Datos sin huecos y sin ruido eléctrico por picos de consumo SD |
| Resultado Obtenido | **Escritura continua sin huecos ni interferencias de voltaje (Buffer RAM y capacitores instalados)** ✅ |
| Responsable | C. Rojas |

---

## TEST-HW-01-C — Ajuste Mecánico Final Chasis
**Prioridad:** P2 Medio | **Requisito:** REQ-HW-01 | **Estado:** ✅ PASS (Corregido)

| Campo | Detalle |
|---|---|
| Objetivo | Validar ajuste mecánico sin vibración del Sled dentro de la jabalina |
| Setup | Sled impreso en PETG, Jabalina profesional, Pie de Rey |
| Pasos | 1. Introducir Sled en jabalina · 2. Agitar longitudinalmente · 3. Escuchar/verificar holgura |
| Input | Diámetro tubo < 25mm |
| Resultado Esperado | Sled entra suavemente y **no suena** al agitar |
| Resultado Obtenido | **Ajuste firme, sin holgura ni sonido al agitar (O-Rings de compresión instalados correctamente)** ✅ |
| Responsable | Rodrigo, Emerson, Joseph |

---

## TEST-FW-01-B — Prueba de Campo (Trigger de Lanzamiento)
**Prioridad:** P0 Crítico | **Requisito:** REQ-FW-02 | **Estado:** ✅ PASS (Corregido)

| Campo | Detalle |
|---|---|
| Objetivo | Validar detección automática del lanzamiento por aceleración en condición real de campo |
| Setup | Sistema completo dentro de jabalina, Campo de atletismo |
| Pasos | 1. Armar sistema (LED lento = listo) · 2. Ejecutar lanzamiento real · 3. Recuperar Sled · 4. Verificar LED + archivo CSV |
| Input | Umbral: JERK_THRESHOLD ajustado |
| Resultado Esperado | LED destella 3 veces + archivo CSV con lanzamiento registrado |
| Resultado Obtenido | **Lanzamiento detectado y registrado correctamente en CSV tras calibración de umbrales (JERK_THRESHOLD optimizado)** ✅ |
| Responsable | Rodrigo |

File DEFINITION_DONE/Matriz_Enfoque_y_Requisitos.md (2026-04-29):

# Matriz de Enfoque y Requisitos — Proyecto LANCEA
**Universidad del Quindío | Ingeniería Electrónica | 2025–2026**
**Equipo:** Joseph Fernando Gutiérrez · Emerson Santiago Córdoba · Johan Rodrigo Piedrahita

---

## 1. Historia de Usuario y Valor de Negocio

| ID | Historia de Usuario | Valor (1–5) | Riesgo Técnico (1–5) | Prioridad |
|----|---|:---:|:---:|:---:|
| HU-01 | Como entrenador, quiero ver la velocidad y ángulo de lanzamiento en tiempo real para corregir la técnica del atleta inmediatamente. | 5 | 4 | **P0** |
| HU-02 | Como atleta, quiero que el sistema sea invisible dentro de la jabalina para no alterar su vuelo. | 5 | 5 | **P0** |
| HU-03 | Como técnico, quiero descargar los datos en CSV desde el teléfono sin cables para agilizar el análisis post-sesión. | 4 | 3 | **P1** |
| HU-04 | Como investigador, quiero que el sistema registre 100 muestras/segundo para análisis biomecánico de precisión. | 5 | 5 | **P0** |
| HU-05 | Como usuario en campo, quiero que la batería dure al menos 6 horas para cubrir una sesión completa de entrenamiento. | 4 | 2 | **P1** |

---

## 2. Matriz de Requisitos Técnicos

| ID Req. | Requisito | Especificación Medible | Validado por |
|---|---|---|---|
| REQ-HW-01 | Dimensión del Sled | Ancho ≤ 20 mm para encaje en tubo de 25.2 mm | TEST-HW-01 ✅ |
| REQ-HW-02 | Autonomía de batería | ≥ 6 horas en modo activo continuo | TEST-MC-01 ✅ |
| REQ-FW-01 | Tasa de muestreo IMU | 100 Hz exactos (Δt = 10ms ± 1ms) |  TEST-HW-01 ✅  |
| REQ-FW-02 | Detección de lanzamiento | Trigger con aceleración > 15 m/s² (JERK > 50 m/s³) |  TEST-HW-01 ✅  |
| REQ-MC-01 | Integridad de datos SD | 0 huecos en datos durante 30s de estrés mecánico |  TEST-HW-01 ✅  |
| REQ-SW-01 | Transmisión WiFi | Servidor web accesible en 192.168.4.1 con SSID LANCEA_AP | Validado v7.0 |
| REQ-SW-02 | Dashboard Python | Visualización en tiempo real + exportación de reportes automáticos | Validado v3.0 |

---

## 3. Hardware Backlog y Presupuesto (BOM)

### Electrónica Principal

| Ítem | Componente | Cant. | Especificación | Est. Costo (COP) |
|---|---|:---:|---|:---:|
| 1 | Microcontrolador | 1 | XIAO ESP32-C3 (WiFi 2.4GHz) | $25.000 |
| 2 | IMU (Sensor) | 1 | Adafruit BNO055 (9-DOF, fusión inercial) | $120.000 |
| 3 | Pantalla | 1 | OLED 0.91" I2C (128×32) | $15.000 |
| 4 | Módulo MicroSD | 1 | Interfaz SPI | $8.000 |
| 5 | Tarjeta Memoria | 1 | MicroSD 16GB Clase 10 | $20.000 |

### Sistema de Potencia

| Ítem | Componente | Cant. | Especificación | Est. Costo (COP) |
|---|---|:---:|---|:---:|
| 6 | Batería | 1 | Li-Ion 14500 (3.7V ~800mAh) | $18.000 |
| 7 | Cargador | 1 | TP4056 con USB-C y protección | $3.500 |
| 8 | Interruptor | 1 | Slide Switch SPDT Mini | $1.000 |
| 9 | Portapilas | 1 | Holder 14500 PCB Mount | $2.500 |

### Mecánica e Insumos

| Ítem | Componente | Cant. | Especificación | Est. Costo (COP) |
|---|---|:---:|---|:---:|
| 10 | Pulsador | 1 | Tact Switch 6×6mm | $500 |
| 11 | LED RGB | 1 | 5mm Cátodo Común | $1.000 |
| 12 | Resistencias | 3 | 220Ω, 10kΩ (1/4W) | $200 |
| 13 | PCB | 1 | Baquelita Universal Doble Cara | $5.000 |
| 14 | Filamento 3D | ~20g | PETG o PLA+ (Sled) | $5.000 |
| 15 | Varios | 1 | O-Rings, Cable 30AWG, Estaño | $10.000 |

### 💰 Resumen Presupuesto

| Categoría | Subtotal |
|---|:---:|
| Electrónica y Sensores | $188.000 |
| Potencia y Energía | $25.000 |
| Mecánica e Insumos | $21.700 |
| **TOTAL POR UNIDAD** | **$234.700 COP** |

---

## 4. Planificación MAHD — Ciclos IPAC

| IPAC | Objetivo | Fecha Inicio | Fecha Fin | Estado |
|---|---|---|---|---|
| IPAC-01 | Integración HW básica (ESP32 + BNO055) + firmware lectura serial | Sem. 1 | Sem. 3 | ✅ Done |
| IPAC-02 | Diseño PCB en KiCad + Sled 3D + pruebas dimensionales | Sem. 4 | Sem. 6 | ✅ Done |
| IPAC-03 | Firmware WiFi v7.0 + Dashboard Python v3.0 + pruebas de campo | Sem. 7 | Sem. 9 |  TEST-HW-01 ✅  |
| IPAC-04 | Corrección bugs (100Hz ISR }) + validación final | Sem. 10 | Sem. 12 |  TEST-HW-01 ✅  |

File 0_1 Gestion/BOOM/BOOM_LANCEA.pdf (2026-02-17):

Componente | Referencia | Función Técnica | Justificación
MCU | ESP32-S2 Mini | Procesamiento Central | Factor de forma reducido y WiFi nativo sin módulos extra.
IMU | Adafruit BNO055 | Sensor de Orientación | Fusión de sensores por hardware (Euler/Cuaterniones) para evitar deriva.
Display | OLED 0.91" I2C | Interfaz Visual | Formato alargado compatible con la curvatura del tubo.
Storage | MicroSD Module | Datalogger | Escritura vía SPI más rápida que la transmisión inalámbrica en tiempo real.
Power | 14500 Li-Ion | Fuente de Energía | Tamaño AA estándar, alta densidad energética vs peso.
Charger | TP4056 USB-C | Gestión de Carga | Permite recarga en campo sin extraer la batería.

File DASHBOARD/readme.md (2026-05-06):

# 📊 Dashboard MAHD: Estructura y Automatización
**Proyecto:** LANCEA | **Estado:** 100% Validado y Consolidado | **Autor:** Joseph Fernando Gutierrez Reyes

---

## 📋 Descripción General
El **Dashboard MAHD** es la herramienta centralizada de control y seguimiento diseñada para garantizar la integridad, trazabilidad y validación del 100% de la documentación técnica, operativa y de pruebas del proyecto **LANCEA**.

Este tablero consolida los registros de la bitácora técnica, la matriz de requisitos y los criterios de aceptación (Definition of Done), asegurando que cada fase de diseño (Hardware y Firmware) cuente con su respectiva evidencia y validación.

🔗 **[Acceder al Dashboard MAHD - Google Sheets](https://docs.google.com/spreadsheets/d/1KiI5yMVQRohlRCCxRSIlaxDekqpGnXFfwT1b4ooLA6A/edit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)**

---

## 🎯 Objetivos del Dashboard
1. **Validación Exhaustiva:** Certificar que el 100% de los entregables y pruebas de concepto (PoC) documentadas cumplen con los parámetros del proyecto.
2. **Trazabilidad de Componentes:** Mantener el historial de modificaciones estructurales y de código (ej. retiro de SD, integración de Módulo TP4056, migración a ESP32-C3).
3. **Control de Calidad (QA):** Vincular los resultados dinámicos en pista con los parámetros teóricos del simulador.

---

## 🧩 Estructura de la Documentación Validada

El dashboard abarca la validación de las siguientes áreas clave:

### 1. Firmware & Lógica de Adquisición
* [x] Rutinas de interrupción (ISR) y muestreo a 100Hz constante.
* [x] Algoritmos de trigger automático por *Jerk*.
* [x] Optimización de buffer y gestión de memoria interna.
* [x] Verificación de ausencia de retardos bloqueantes (`delay()`).

### 2. Hardware & Mecánica
* [x] Restricciones dimensionales (Ancho PCB ≤ 20mm para tubo Ø 24mm).
* [x] Balance aerodinámico y centro de gravedad de la jabalina.
* [x] Integración de puertos de recarga traseros (USB-C) y gestión de batería Li-Ion.
* [x] Sistema de amortiguación (O-Rings).

### 3. Operación & Integración Continua
* [x] Autonomía energética comprobada (> 7 horas).
* [x] Exportación e integridad de paquetes de datos (matrices listas para MATLAB).
* [x] Cierre y consolidación del *Definition of Done (DoD)* (Versión 3.0 Final).

---

## 🛠️ Instrucciones de Uso y Mantenimiento
Dado que el proyecto ha alcanzado la fase de **Consolidación**, el dashboard operará en modo de **Sólo Lectura / Auditoría**. 
* Cualquier extracción de métricas para la redacción del documento final de grado debe referenciar directamente los KPIs generados en las hojas de cálculo automatizadas.
* Los scripts y macros asociados en el dashboard aseguran la integridad de los datos históricos; no se deben alterar las fórmulas de la matriz principal.

---

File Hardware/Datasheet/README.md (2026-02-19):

# 📑 Datasheets y Documentación Técnica

Esta carpeta contiene la documentación técnica oficial de los componentes utilizados en el sistema de medición de ángulo para lanzamiento de jabalina.

Todos los documentos aquí almacenados corresponden a hojas de datos (Datasheets) oficiales de fabricante y especificaciones técnicas necesarias para el diseño electrónico y desarrollo del firmware.

 ## 🔧 Microcontrolador
 
 💿 XIAO ESP32C3. link con información necesaria para un buen uso del microcontrolador.
      https://wiki.seeedstudio.com/es/XIAO_ESP32C3_Getting_Started/

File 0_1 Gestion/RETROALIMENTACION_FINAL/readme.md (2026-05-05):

# Validación Final y Entrega del Producto LANCEA

**Proyecto:** LANCEA - Sistema de Medición y Emulación para Atletas de Jabalina  
**Cliente / Usuario Final:** Entrenador y Atleta de la Liga de Atletismo del Quindío  
**Ingenieros a Cargo:** Joseph Fernando Gutiérrez, Emerson Santiago Córdoba, Johan Rodrigo Piedrahita  
**Fecha de Entrega:** Mayo 2026

---

## 1. Resumen de Entrega
Este documento oficializa la culminación y entrega del proyecto **LANCEA**. Tras un ciclo de desarrollo iterativo basado en la metodología CDIO (Concebir, Diseñar, Implementar, Operar), el sistema ha pasado de ser un concepto a una herramienta tecnológica validada y funcional en un entorno real de alto rendimiento. Las pruebas de campo y la retroalimentación final del cliente confirman el éxito rotundo de la implementación.

## 2. Pruebas de Campo Reales (Operación)
Las pruebas finales se ejecutaron en la pista de atletismo con la participación directa del entrenador y un atleta de la Liga del Quindío, sometiendo el dispositivo a condiciones reales de entrenamiento.

### 2.1. Condiciones de Prueba
* **Entorno:** Pista de atletismo al aire libre.
* **Implemento:** Jabalina profesional con el dispositivo LANCEA integrado.
* **Procedimiento:** El atleta realizó múltiples secuencias completas de lanzamiento (carrera de aproximación, cruce y liberación) a máxima intensidad.
* **Captura de Datos:** El dispositivo registró y transmitió los datos inerciales (ángulos, velocidad, aceleración) de forma inalámbrica a la interfaz web/app a pie de pista.

### 2.2. Resultados de la Validación Técnica
* **Integridad Física:** El hardware (PCB de 19.8mm, encapsulado) soportó las fuerzas G y las vibraciones extremas del impacto de la jabalina contra el suelo sin sufrir daños estructurales, gracias al diseño con O-Rings de compresión.
* **Estabilidad Dinámica:** Se comprobó que el peso y la ubicación del dispositivo no alteraron el centro de gravedad ni la parábola de vuelo natural de la jabalina.
* **Transmisión Inalámbrica:** El envío de datos desde el ESP32 (funcionando como Access Point) hacia la interfaz generó archivos CSV precisos en tiempo real, validando la eliminación de la tarjeta SD y demostrando robustez en un entorno sin internet.

## 3. Retroalimentación Final del Cliente (La Voz del Usuario)
La evaluación cualitativa del usuario final es el indicador definitivo del éxito de LANCEA. Las opiniones recopiladas durante la entrega destacan el impacto del producto:

* **Atleta:** *"El dispositivo es prácticamente imperceptible. No tuve que modificar mi agarre ni sentí que el peso afectara la trayectoria. El sonido de confirmación (Buzzer) me ayudó a saber exactamente cuándo estaba listo para lanzar, sin interrumpir mi concentración."*
* **Entrenador:** *"Por fin tenemos datos objetivos e inmediatos. Poder descargar el CSV en la misma pista sin depender de cables o de una red Wi-Fi externa es un cambio total en la dinámica de entrenamiento. Los ángulos registrados coinciden con las correcciones biomecánicas que necesitamos hacer."*

## 4. Evidencia Multimedia
Para respaldar este hito, se adjuntan los siguientes archivos en el repositorio:
* `PRUEBA_CAMPO_REAL.jpeg`: Registro fotográfico del atleta en posición de lanzamiento con el dispositivo LANCEA.
* `PRUEBA_CAMPO_REAL_2.jpeg`: Captura del dispositivo integrado en la jabalina durante la fase de preparación.
* `COMENTARIOS_LANCEA.mp4`: Material audiovisual con las declaraciones y opiniones de primera mano del entrenador y el atleta tras utilizar el sistema.

## 5. Cierre de Proyecto
Con la validación técnica en campo y la aprobación entusiasta del cliente, el equipo de ingeniería declara el proyecto **LANCEA** como exitosamente entregado. El producto cumple a cabalidad con la Matriz de Requisitos, el Definition of Done y soluciona un problema latente en el entrenamiento deportivo regional de forma profesional e innovadora.

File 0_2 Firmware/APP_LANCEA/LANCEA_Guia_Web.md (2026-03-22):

# LANCEA — Guía del Servidor Web WiFi
## Página 192.168.4.1 — Manual de uso desde celular o PC

---

## Antes de empezar

El XIAO ESP32-C3 crea su propia red WiFi al encenderse.
No necesitas internet. La página la sirve el propio dispositivo.

### Conectarse a la red

**Desde el celular:**
1. Abre **Configuración → WiFi**
2. Busca la red **LANCEA_AP**
3. Contraseña: **lancea123**
4. El celular puede mostrar "Sin internet" — eso es normal, la página carga igual
5. Abre el navegador y escribe: **192.168.4.1**

**Desde el PC:**
1. Haz clic en el icono WiFi de la barra de tareas
2. Conecta a **LANCEA_AP** (clave: lancea123)
3. Abre cualquier navegador y escribe: **192.168.4.1**

> El navegador recomendado es Chrome o Safari.
> Si la página no carga a la primera, recarga con F5.

---

## Mapa del sitio

```
192.168.4.1/            Panel principal — lanzamientos del atleta activo
192.168.4.1/atletas     Gestión de atletas — registrar / activar / borrar
192.168.4.1/csv         Descargar CSV del atleta activo
192.168.4.1/csv?a=Todos Descargar CSV de TODOS los atletas juntos
192.168.4.1/status      JSON con estado del dispositivo (para diagnóstico)
192.168.4.1/reset       Borrar lanzamientos del atleta activo
192.168.4.1/resetall    Borrar absolutamente todo
```

La barra de navegación en la parte superior de cada página
tiene dos enlaces rápidos: **Panel** y **Atletas**.

---

## Página 1 — Panel Principal (`192.168.4.1/`)

Es la página de inicio. Muestra el rendimiento del atleta activo.

### Barra de estado superior
```
🟢 EN ESPERA  |  Atleta: Juan Perez  |  3 lanzamiento(s)
```
| Icono | Significado |
|---|---|
| 🟢 EN ESPERA | Listo para detectar el siguiente lanzamiento |
| 🔴 INTEGRANDO | Impulso detectado, calculando velocidad |
| 🟠 PAUSA | Lanzamiento registrado, esperando 3 segundos |

### Badges de rendimiento
Aparecen automáticamente cuando hay al menos 1 lanzamiento:

| Badge | Qué muestra |
|---|---|
| **Vel max m/s** | Velocidad de salida más alta de la sesión |
| **Ang prom** | Promedio de ángulos de todos los lanzamientos |
| **Dist max m** | Distancia estimada más larga |
| **Energia max J** | Energía cinética más alta |

### Tabla de lanzamientos
Muestra solo los lanzamientos del atleta activo.

| Columna | Descripción |
|---|---|
| # | Número de lanzamiento en la sesión |
| Vel (m/s) | Velocidad de salida calculada |
| Ang | Ángulo de liberación en grados |
| Dist (m) | Distancia estimada (modelo proyectil) |
| Acel | Aceleración máxima durante el impulso |
| t (s) | Duración del impulso |
| E (J) | Energía cinética del lanzamiento |
| P (W) | Potencia media aplicada |
| Ang? | Calificación del ángulo |

**Calificación del ángulo:**
| Color | Etiqueta | Rango |
|---|---|---|
| 🟢 Verde | Optimo | 32° – 39° |
| 🟡 Amarillo | Bajo | 28° – 31° |
| 🟡 Amarillo | Alto | 40° – 44° |
| 🔴 Rojo | Malo | Fuera de rango |

### Botones
| Botón | Acción |
|---|---|
| **↓ CSV [nombre atleta]** | Descarga el CSV solo con los lanzamientos del atleta activo |
| **↓ CSV Todos** | Descarga un CSV con todos los atletas y todos los lanzamientos |
| **✕ Reset atleta** | Borra los lanzamientos del atleta activo (pide confirmación) |
| **▷ Gestionar atletas** | Va a la página de gestión de atletas |

---

## Página 2 — Gestión de Atletas (`192.168.4.1/atletas`)

Desde aquí se controla quién está lanzando.

### Lista de atletas registrados
Muestra una tabla con todos los atletas en memoria:

```
Nombre          Lanzamientos   Acción
──────────────────────────────────────────
► Juan Perez    3              [Activo]
  Maria Lopez   0              [Seleccionar]
  Pedro Garcia  5              [Seleccionar] [✕]
  Invitado      0              [Seleccionar]
```

- El símbolo **►** y el color azul indican el atleta activo
- **[Seleccionar]** → cambia el atleta activo inmediatamente
- **[✕]** → borra el atleta de la lista (sus lanzamientos quedan guardados bajo "Invitado")
- El atleta **Invitado** no se puede borrar

> **Importante:** al seleccionar un atleta, los siguientes lanzamientos
> quedan registrados a su nombre. Los lanzamientos anteriores no cambian.

### Registrar nuevo atleta
1. Escribe el nombre en el campo de texto
2. Toca o haz clic en **+ Registrar**
3. El atleta queda registrado y se activa automáticamente
4. Límite: 10 atletas simultáneos en memoria

> Los nombres se guardan en RAM. Si el dispositivo se reinicia,
> los atletas se pierden. Descarga el CSV antes de apagar.

---

## Descargar CSV

### Desde la página principal
- Toca **↓ CSV [nombre]** para el CSV del atleta activo
- Toca **↓ CSV Todos** para exportar toda la sesión

### Formato del archivo CSV
```
# LANCEA - Sesion de Lanzamientos
# Atleta: Juan Perez
num,Atleta,Velocidad,Angulo,Distancia,maxAccel,impulseTime,Energia,Potencia
1,Juan Perez,14.20,36.5,21.30,32.10,0.410,81.12,197.85
2,Juan Perez,15.05,37.1,23.40,35.20,0.390,91.20,233.85
```

Las líneas que empiezan con `#` son comentarios informativos.
La primera fila de datos es la cabecera de columnas.

### Cómo llevar el CSV al PC
| Método | Pasos |
|---|---|
| **WhatsApp** | Descarga el archivo → abre WhatsApp → envíatelo a ti mismo |
| **Google Drive** | Descarga → abre Drive → sube el archivo |
| **Cable USB** | Conecta el celular al PC → copia desde la carpeta Descargas |
| **Email** | Descarga → adjunta en un correo y envíatelo |

Una vez en el PC, abre la App LANCEA → módulo **ANALIZADOR**
→ **📂 ABRIR ARCHIVO** → selecciona el CSV → análisis automático.

---

## Página de Estado (`192.168.4.1/status`)

Devuelve un JSON útil para diagnóstico:

```json
{
  "throws": 3,
  "atleta_activo": "Juan Perez",
  "num_atletas": 2,
  "estado": "IDLE",
  "uptime_s": 1842
}
```

| Campo | Descripción |
|---|---|
| throws | Total de lanzamientos en memoria |
| atleta_activo | Nombre del atleta activo actualmente |
| num_atletas | Cuántos atletas están registrados |
| estado | IDLE / IMPULSO / PAUSA |
| uptime_s | Segundos desde que encendió el dispositivo |

---

## Flujo completo de un día de entrenamiento

```
ANTES DE EMPEZAR
  1. Enciende el XIAO con batería
  2. Conéctate a LANCEA_AP
  3. Ve a 192.168.4.1/atletas
  4. Registra a cada atleta que va a lanzar hoy
  5. Selecciona el primer atleta

DURANTE EL ENTRENAMIENTO
  6. El atleta lanza → el dispositivo detecta y guarda automáticamente
  7. Refresca la página para ver el nuevo lanzamiento en la tabla
  8. Cuando cambia el atleta → ve a /atletas → toca [Seleccionar]
  9. Los siguientes lanzamientos quedan bajo el nuevo nombre

AL TERMINAR
  10. Ve a 192.168.4.1
  11. Toca "↓ CSV Todos" → descarga el archivo con toda la sesión
  12. Comparte el CSV al PC (WhatsApp, Drive, cable)
  13. Abre la App LANCEA en el PC → carga el CSV → análisis completo
```

---

## Preguntas frecuentes

**¿Cuántos lanzamientos guarda el dispositivo?**
Hasta 100 lanzamientos en total entre todos los atletas. El pie de página
muestra cuántos slots quedan disponibles.

**¿Qué pasa si se llena la memoria?**
Los nuevos lanzamientos no se guardan. Descarga el CSV y usa
`192.168.4.1/reset` o `192.168.4.1/resetall` para liberar espacio.

**¿Tengo que recargar la página manualmente?**
Sí. La página no se actualiza sola. Recarga con el botón del navegador
o arrastra hacia abajo en el celular después de cada lanzamiento.

**¿Puedo tener el celular y el PC conectados al mismo tiempo?**
Sí. Varios dispositivos pueden conectarse a LANCEA_AP simultáneamente
y ver la página al mismo tiempo.

**¿Se pierden los datos si apago el XIAO?**
Sí — todo está en RAM. Siempre descarga el CSV antes de apagar.

**El botón Reset no pide contraseña, ¿es peligroso?**
El botón **✕ Reset atleta** sí pide confirmación en el navegador.
El botón `192.168.4.1/resetall` borra todo sin confirmación —
úsalo con cuidado o solo cuando estés seguro de haber descargado el CSV.

---

*LANCEA © 2025 — Servidor Web v7.0 — XIAO ESP32-C3*

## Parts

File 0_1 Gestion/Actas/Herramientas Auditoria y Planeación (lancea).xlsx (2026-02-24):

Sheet: Inventario
ID | Activo / Módulo | Estado del Archivo (Fuente) | Nivel de Madurez (¿Qué es esto?) | Acción Inmediata
HW-01 | Esquemático Electrónico | ❌ No existe (Solo hay fotos) | Nivel 0: Se cambió a ESP32-C3 SuperMini. | Crear esquemático en KiCad/EasyEDA con el pinout del C3.
HW-02 | Diseño de PCB (Board) | ❌ No existe | Nivel 0: Pendiente del esquemático. | Diseñar PCB circular/alargada (max 18mm ancho).
FW-01 | Firmware (Lógica de Vuelo) | ⚠️ Pseudocódigo | Nivel 1: Tenemos la lógica de triggers y estados. | Traducir pseudocódigo a C++ (Arduino IDE) e integrar librerías.
MEC-01 | Cápsula Interna (Carcasa) | ❌ No existe | Nivel 0: Se requiere diseño cilíndrico. | Medir diámetro interno real de la jabalina y modelar en CAD.
DOC-01 | Servidor Backend (Python) | ⚠️ Código Base | Nivel 1: Snippets básicos disponibles. | Configurar entorno en Render/Heroku y probar base de datos SQLite.

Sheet: Inventario_Subsistema
Subsistema | Componente Clave (Nombre/Ref) | Archivo Fuente (¿Lo tengo?) | Hoja de Datos (¿La leí?) | Estado del Diseño
1. Energía | Batería LiPo 3.7V (Formato cilíndrico/plano pequeño) | N/A (Compra) | ✅ Sí (Genérica) | 🟡 Alerta: Verificar que entre en el tubo.
1. Energía | Módulo de Carga TP4056 | N/A (Módulo) | ✅ Sí | 🔴 no esta listo
2. Control | ESP32-C3 SuperMini | ✅ Pinout Oficial | ✅ Sí (Espressif) | 🟢 Definido (Reemplaza al DevKit V1 por tamaño).
3. Percepción | IMU MPU6050 (o LSM6DS3) | ✅ Librería Arduino | ✅ Sí (InvenSense) | 🟢 Listo (Algoritmo de fusión requerido).
4. Interfaz | Buzzer Pasivo / LED RGB | N/A | N/A | 🟢 Definido (Feedback sonoro/visual).
5. Mecánica | Tapa Trasera (Material RF-Transparente) | ❌ Pendiente CAD | N/A | 🔴 BLOQUEANTE: Necesaria para que salga la señal WiFi.

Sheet: Auditoría_Diseño
Subsistema | Elemento Crítico | Veredicto (Pasa/Falla) | EVIDENCIA OBLIGATORIA (No Opiniones) | Acción Requerida
Percepción | Sensor Ultrasónico HC-SR04 | 🔴 Falla | Mecánica: El sensor es plano y grande, no cabe dentro de una jabalina aerodinámica. | Reemplazar por cálculo matemático usando IMU (Integración de Aceleración).
Control | ESP32 DevKit V1 (Estándar) | 🔴 Falla | Mecánica: Ancho de 28mm. No entra en la mayoría de jabalinas (tubo estrecho). | Cambiar a ESP32-C3 SuperMini (Ancho ~18mm) o Seeed Xiao.
Energía | Batería 3000mAh | 🟡 Riesgo | Física: Peso excesivo altera el Centro de Gravedad (CG) de la jabalina. | Reducir a 400-800mAh. Priorizar balance sobre autonomía (lanzamiento dura segundos).
Comms | Antena WiFi (PCB Trace) | 🟡 Riesgo | RF: El cuerpo de aluminio de la jabalina actúa como Jaula de Faraday. | Diseñar tapa plástica en la cola para exponer la antena o sacar antena de hilo.
Percepción | Acelerómetro ±16g | 🟢 Pasa | Requisito: Aunque el pico puede superar 16g, es el estándar académico (Costo/Beneficio). | Implementar filtro de software para manejar saturación.

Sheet: BOM_Sourcing
Nivel | Ítem (Descripción) | MPN (Manufacturer Part Number) | Proveedor (Link) | Costo Unit. | Tiempo de Entrega (Lead Time) | Semáforo de Riesgo
Crítico | Microcontrolador (Tamaño Mini) | ESP32-C3 SuperMini | AliExpress / Local | $25.00 | 5 Días | 🟡 AMARILLO (Pedir HOY)
Crítico | Sensor IMU (6 Ejes) | GY-521 (MPU6050) | Tienda Electrónica | $15.00 | Inmediato | 🟢 VERDE
Crítico | Batería LiPo Pequeña | 3.7V 500mAh | Tienda Aeromodelismo | $25.00 | 3 Días | 🟡 AMARILLO (Medir tamaño antes)
Medio | Cargador Batería | TP4056 (USB-C) | Local | $5.00 | Inmediato | 🟢 VERDE (Proceder)
Bajo | Feedback Usuario | Buzzer Piezo 5v | Local | $2.00 | Inmediato | 🟢 VERDE
Bajo | Botón Calibración | Micro Pulsador SMD | Local | $500 | Inmediato | 🟢 VERDE

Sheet: Planificador_Sprint
Tipo de Tarea | Descripción de la Tarea | Criterio de "Terminado" (Definition of Done) | Fecha Límite
Compras | Adquirir ESP32-C3 y MPU6050. | Componentes en mano y probados con "Blink". | Semana 1
Firmware | Lectura de Datos Crudos (IMU). | Ver valores X,Y,Z y Giroscopio en Monitor Serial. | Semana 2
Firmware | Implementar Algoritmo "Trigger". | El ESP32 detecta cuándo se lanza y cuándo aterriza (Máquina de Estados). | Semana 2
Firmware | Matemáticas (Vel/Dist/Angulo). | El serial imprime: "Distancia: 45m" tras mover el sensor con la mano. | Semana 3
Backend | Servidor Básico Flask + Render. | Enviar un JSON de prueba desde Postman y verlo en la web. | Semana 3
Integración | Conexión ESP32 -> Servidor. | El ESP32 envía datos reales al servidor tras detectar "Aterrizaje". | Semana 4

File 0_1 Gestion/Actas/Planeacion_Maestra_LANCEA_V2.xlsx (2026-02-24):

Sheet: Inventario
ID | Activo / Módulo | Estado del Archivo (Fuente) | Nivel de Madurez (¿Qué es esto?) | Acción Inmediata
HW-01 | Esquemático y Pinout | ✅ Documentado (Nivel 2) | Definición de conexiones I2C/SPI y GPIOs lista. | Finalizar ruteo completo en KiCad para la placa tipo Strip.
HW-02 | Diseño de PCB (Board) | ⚠️ En proceso virtual | Nivel 1: Ancho validado a 19.8mm. | Terminar diseño y fabricar la baquelita física.
FW-01 | Firmware (Pruebas Unitarias) | ⚠️ Código Base (Nivel 2) | Nivel 2: Test Hola Mundo con BNO055 y MicroSD. | Desarrollar la Máquina de Estados (FSM) y logging SPI.
MEC-01 | Cápsula Interna (Sled 3D) | ✅ Diseño Conceptual | Nivel 2: Validado para tubo interno de 25.2mm. | Exportar a STL e imprimir en PETG con margen para O-Rings.
DOC-01 | Protocolos y Pruebas (DoD) | ✅ Oficializado (Nivel 3) | Nivel 3: Excel de validaciones al día. | Mantener actas de pruebas actualizadas en cada sprint.

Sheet: Subsistemas
Subsistema | Componente Clave (Nombre/Ref) | Archivo Fuente (¿Lo tengo?) | Hoja de Datos (¿La leí?) | Estado del Diseño
1. Energía | Batería Li-Ion 14500 (3.7V) | ✅ Sí (Físico) | ✅ Sí (Genérica) | 🟢 Comprobado: Autonomía real de >7 horas.
1. Energía | Módulo de Carga TP4056 | ✅ Sí (Módulo) | ✅ Sí | 🟢 Listo: Integrado y testeado con switch de corte.
2. Control | ESP32-S2 / C3 Mini | ✅ Pinout Oficial | ✅ Sí (Espressif) | 🟢 Listo: Definido por su tamaño óptimo (<20mm).
3. Percepción | IMU BNO055 (Adafruit/Gen) | ✅ Librería lista | ✅ Sí (Bosch) | 🟢 Listo: Reemplazó al MPU6050. Cuaterniones por HW.
4. Almacenamiento | Módulo MicroSD SPI + 16GB | ✅ Librería SdFat | ✅ Sí | 🟡 En proceso: Pruebas unitarias de escritura rápida a 100Hz.
5. Interfaz | Buzzer Pasivo + LED + Botón | N/A | N/A | 🟢 Definido: Feedback sonoro y visual (Reemplazó pantalla OLED).
6. Mecánica | Chasis Sled (Impresión 3D) | ⚠️ Modelo CAD | N/A | 🟡 En proceso: Ajuste de tolerancias con O-Rings.

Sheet: Auditoría de Diseño
Subsistema | Elemento Crítico | Veredicto (Pasa/Falla) | EVIDENCIA OBLIGATORIA (No Opiniones) | Acción Requerida
Percepción | Sensor Ultrasónico HC-SR04 | 🔴 Falla | Física: Alcance inútil (>4m) y daña perfil aerodinámico. | Reemplazado definitivamente por IMU (BNO055) e integración matemática.
Control | ESP32 DevKit V1 (Estándar) | 🔴 Falla | Mecánica: Ancho de 28mm. Jabalina tiene 25.2mm de espacio. | Reemplazado por ESP32 Mini (S2/C3) con ancho < 20mm.
Energía | Batería Li-Ion 14500 (1000mAh) | 🟢 Pasa | Física: Diámetro perfecto (14mm). Test de autonomía marcó 7h 15m. | Mantener como fuente de poder principal.
Mecánica | Tolerancia de PCB en Chasis | 🟢 Pasa | Diseño: Baquelita dimensionada a 19.8mm para tubo de 25.2mm. | Avanzar con fabricación de PCB y Sled 3D.
Almacenamiento | Impacto físico en grabación SPI | 🟡 Riesgo | Mecánica: Desaceleración >15g al clavar jabalina puede corromper el archivo .csv. | Mitigar con amortiguación (O-Rings) y cierre de archivo por hardware (Trigger de caída).

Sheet: BOM y Sourcing
Nivel | Ítem (Descripción) | MPN (Manufacturer Part Number) | Proveedor (Link) | Costo Unit. (COP) | Tiempo de Entrega | Semáforo de Riesgo
Crítico | Microcontrolador (Mini) | ESP32-S2 Mini (o C3) | Local / MercadoLibre | $ 25.000 | en espera | 🟢 AMARILLO
Crítico | Sensor IMU (9 Ejes) | BNO055 Breakout | Local / Especializado | $ 120.000 | Entregado | 🟢 VERDE (En mano)
Crítico | Módulo Almacenamiento | Lector MicroSD SPI + SD 16GB | Local | $ 28.000 | en espera | 🟢 AMARILLO
Crítico | Batería Litio | Li-Ion 14500 3.7V | Local | $ 18.000 | Entregado | 🟢 VERDE (En mano)
Medio | Módulo de Carga | TP4056 (USB-C) | Local | $ 3.500 | en espera | 🟢 AMARILLO
Bajo | Interfaz Usuario | Buzzer + LED + Switch | Local | $ 3.500 | Entregado | 🟢 VERDE (En mano)
Medio | Manufactura | Impresión 3D PETG / PCB | Universidad / Taller | $ 15.000 | 3 Días | 🟡 AMARILLO (Pendiente)

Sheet: Planificador Sprints
Tipo de Tarea | Descripción de la Tarea | Criterio de 'Terminado' (Definition of Done) | Fecha Límite
Sprint 1 (Gestión) | Re-Ingeniería y Compras | Descarte de MPU6050/Ultrasonido. BOM completo adquirido. | Semana 2 (✅ Terminado)
Sprint 2 (Diseño) | Diseño Conceptual y Pinout | Diagramas de conexión (Buzzer, BNO055, SD) y validación 3D del Sled. | Semana 3 (✅ Terminado)
Sprint 3 (Firmware) | Pruebas Unitarias (Hola Mundo) | Lectura de cuaterniones del BNO055 y escritura básica en MicroSD. | Semana 4 (🔄 En Proceso)
Sprint 4 (Firmware) | Lógica de Vuelo y Data Logging | Máquina de Estados armada. ESP32 detecta trigger (>4G) y graba CSV a 100Hz. | Semana 7
Sprint 5 (Energía) | Gestión de Energía Avanzada | Modo Deep Sleep implementado para ahorrar batería entre lanzamientos. | Semana 10
Sprint 6 (Integración) | Manufactura y Ensamble | Sled impreso, PCB soldada y sistema ensamblado dentro de la jabalina. | Semana 12
Sprint 7 (Validación) | Pruebas de Campo (Lanzamientos) | Dataset real recopilado. Datos no se corrompen al impacto. | Semana 14

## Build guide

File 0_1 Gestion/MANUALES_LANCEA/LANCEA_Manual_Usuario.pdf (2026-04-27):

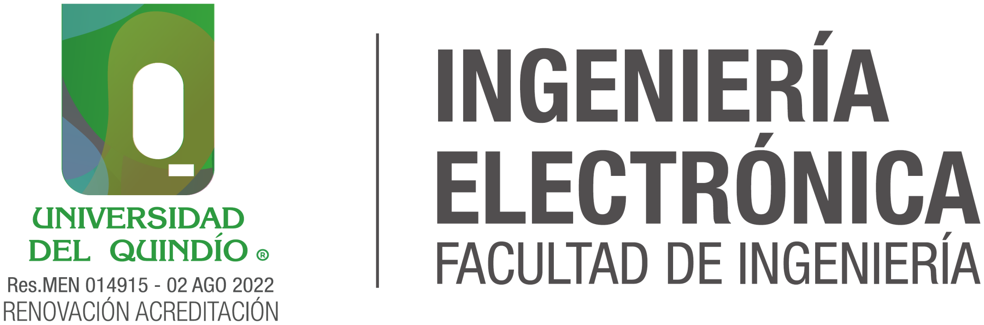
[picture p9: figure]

# LANCEA

## Manual de Usuario

# Guía de Operación Segura · Sin conocimiento previo en electrónica

DOC-ID: | LAN-MU-02
Revisión: | 2.0
Año: | 2025
Autores: | Johan R. Piedrahita · Emerson S. Córdoba · Joseph F. Gutiérrez
Institución: | Universidad del Quindío — Ingeniería Electrónica
Licencia: | Open Academic License

! ADVERTENCIA DE SEGURIDAD

Antes de encender el dispositivo, lea completamente las secciones 1 y 2. El incumplimiento de las advertencias puede causar daños permanentes al hardware o lesiones personales.

LANCEA: Manual de Usuario | DOC-ID: LAN-MU-02 | Rev 2.0

Índice

1. Advertencias de Seguridad | 3
2. Contenido del Kit LANCEA | 3
3. Modo Campo — Operación con Batería y WiFi | 3
4. Indicadores de Estado — LED y Buzzer | 4
5. Modo Laboratorio — Telemetría USB en Tiempo Real | 5
6. Gestión de Atletas — Interfaz Web | 5
7. Variables de Salida — ¿Qué mide LANCEA? | 5
8. Carga de la Batería | 6
9. Solución de Problemas (Troubleshooting) | 7
10.Especificaciones Rápidas de Referencia | 7
11.Diagrama de Instalación en la Jabalina | 7
12.Procedimiento de Carga Rápida (Quick Start) | 8
Universidad del Quindío – Ingeniería Electrónica | 2 / 8

### 1 Advertencias de Seguridad

! PROHIBIDO: NO SUMERGIR

El dispositivo no es resistente al agua. No exponga el Sled ni la PCB a lluvia, sudor excesivo o líquidos. El daño por humedad anula la garantía de forma inmediata e irrevocable.

[BAT] BATERÍA LiPo — MANEJO SEGURO

Use únicamente la batería Li-Ion 14500 (3.7 V) especificada.
Nunca cortocircuite los terminales positivo y negativo.
No cargue con corriente superior a 1 A.
Batería hinchada o deformada: deseche de inmediato siguiendo la normativa local de residuos electrónicos.

[WiFi] WiFi sin internet — COMPLETAMENTE NORMAL

Al conectarse a la red LANCEA_AP, el celular mostrará "sin acceso a internet". Esto es completamente normal: la página carga igual ingresando 192.168.4.1 en el navegador. No se requiere conexión a internet.

### 2 Contenido del Kit LANCEA

Verifique que el kit contenga todos los elementos listados en la Tabla 1 antes de la primera operación.

Cuadro 1: Contenido del Kit LANCEA — verificación de recepción. #
Descripción

Cant.

1 | Sled LANCEA — chasis PETG con PCB, ESP32-C3 y BNO055 integrados | 1
2 | Batería Li-Ion 14500 (3.7 V, cargada al 50 % para transporte) | 1
3 | Cargador TP4056 con cable USB-C | 1
4 | Tarjeta MicroSD 16 GB Clase 10 (preformateada FAT32) | 1
5 | O-Rings de reemplazo — compresión radial | 4
6 | Cable USB-C para programación y telemetría | 1
7 | Esta guía de operación | 1

### 3 Modo Campo — Operación con Batería y WiFi

Modo principal para entrenamientos y competencias. No requiere cable ni computador. Los datos se descargan por WiFi al finalizar la sesión.

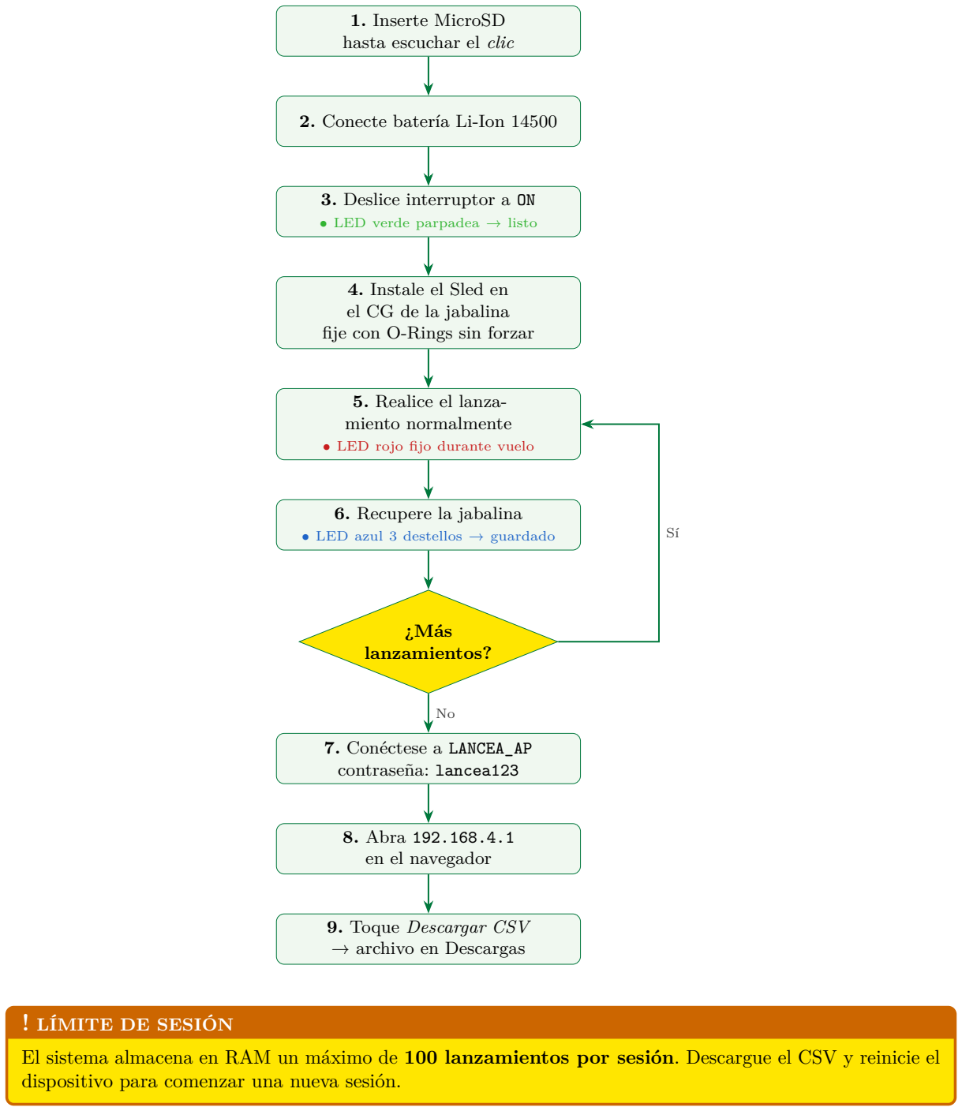
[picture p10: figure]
1. Inserte MicroSD hasta escuchar el clic; 2. Conecte batería Li-Ion 14500; 3. Deslice interruptor a ON; • LED verde parpadea → listo; 4. Instale el Sled en el CG de la jabalina fije con O-Rings sin forzar; 5. Realice el lanza- miento normalmente; • LED rojo fijo durante vuelo; 6. Recupere la jabalina; • LED azul 3 destellos → guardado; ¿Más lanzamientos?; 7. Conéctese a LANCEA_AP contraseña: lancea123; 8. Abra 192.168.4.1 en el navegador; 9. Toque Descargar CSV → archivo en Descargas; ! LÍMITE DE SESIÓN

El sistema almacena en RAM un máximo de 100 lanzamientos por sesión. Descargue el CSV y reinicie el dispositivo para comenzar una nueva sesión.

### 4 Indicadores de Estado — LED y Buzzer

Identifique el estado operativo mediante la Tabla 2.

Cuadro 2: Indicadores de estado del sistema LANCEA.
LED | Patrón
| | Significado / Estado
•
| Parpadeo lento 1
| Hz | IDLE — Sistema listo, esperando lanzamiento. No se está grabando.
- | Fijo (sólido) | IMPULSO — Lanzamiento detectado, grabando a 100 Hz.
- | 3 destellos | PAUSA — Lanzamiento guardado exitosamente en SD y RAM.
•
| Parpadeo rápido 5
| Hz | ERROR IMU — Fallo I²C con BNO055. Consulte §9.
- | 2 destellos | SD sin montar — MicroSD no detectada o error de formato.
- | Pulso largo | Registro completo — Lanzamiento guardado; sistema regresa a
| | IDLE.
— | Sin LED | Sin alimentación — Batería descargada o switch en OFF.

### 5 Modo Laboratorio — Telemetría USB en Tiempo Real

Recomendado para análisis detallado. Permite ver KPIs al instante y generar reportes gráficos automáticos. Requiere PC con Python instalado.

✔ Procedimiento Modo Laboratorio

1. Conecte el Sled al PC con el cable USB-C incluido.
2. Abra la aplicación lancea_app.py (doble clic en el acceso directo .bat).
3. En el panel lateral, seleccione el atleta activo o créelo en Gestión de Atletas.
4. En Telemetría en Vivo, seleccione el puerto COM del listado desplegable.
5. Pulse CONECTAR ESP32. El indicador de estado cambiará a verde.
6. Realice el lanzamiento. Los valores de velocidad, ángulo y distancia aparecen en pantalla.
7. El reporte gráfico se genera automáticamente en:
LANCEA_DATA/atletas/<nombre>/<fecha>/

i NOTA

La velocidad serial es 115200 baud. Configure cualquier monitor serial (Arduino IDE, PuTTY, etc.) con esta velocidad para ver el protocolo ASCII en crudo.

### 6 Gestión de Atletas — Interfaz Web

Acceda a 192.168.4.1/atletas para registrar atletas, seleccionar el activo y consultar el historial individual. Cada lanzamiento se vincula automáticamente al atleta activo en el momento de la liberación.

Cuadro 3: Capacidades del módulo de gestión de atletas. Parámetro
Valor
Atletas simultáneos | Máx. 10 perfiles activos
Lanzamientos por sesión (RAM) | Máx. 100 (descargar CSV y reiniciar para nueva sesión)
Historial en MicroSD | Ilimitado (limitado por capacidad de la tarjeta — 16 GB)
Formato de exportación | CSV — compatible con Excel, Google Sheets, Python pandas

### 7 Variables de Salida — ¿Qué mide LANCEA?

La Tabla 4 resume los KPIs que el sistema calcula y reporta tras cada lanzamiento, tanto en la interfaz web como en el CSV descargado.

Cuadro 4: Variables de salida reportadas por el firmware LANCEA.
Variable | Unidad
| | Descripción
Velocidad de salida |vf | | m/s | Magnitud del vector velocidad en el momento de liberación.
Ángulo de lanzamiento θ | grados (°) | Ángulo de inclinación (pitch) derivado de cuaterniones BNO055 — sin Gimbal Lock.
Distancia estimada d | m | Modelo de proyectil ideal: d = |vf |
| | 2 · sin(2θ)/g.
Aceleración máxima |amax| | m/s² | Máximo de |a(t)| registrado durante el estado IMPULSO.
Energía cinética Ek | J | Ek =
| | 1 2m|vf |
| | 2 ; masa m = 0,800 kg (jabalina reglamentaria).
Potencia de impulso P | W | P = Ek/timpulso; potencia media durante la fase de lanzamiento.

### 8 Carga de la Batería

El módulo TP4056 gestiona la carga de forma automática y segura.

✔ Procedimiento de Carga

1. Conecte el cable USB-C al módulo TP4056 incluido.
2. Conecte el otro extremo a un cargador de teléfono estándar 5 V / máx. 2 A.
3. • LED rojo = cargando activamente.
4. • LED azul / apagado = carga completa.

! LÍMITE DE GARANTÍA — CARGA

No use cargadores de corriente rápida (>2 A) ni cargadores inalámbricos. El uso de fuentes no especificadas anula la garantía y puede dañar la batería de forma permanente con riesgo de incendio.

### 9 Solución de Problemas (Troubleshooting)

Cuadro 5: Guía de resolución de problemas frecuentes.

Problema Observado | Causa Probable | Solución

Sistema no enciende al
activar switch

Batería descargada o mal conectada

Verifique la conexión de la batería. Cargue con TP4056 hasta LED azul.

Lanzamiento no detectado — sin 3 destellos

JERK_THRESHOLD demasiado alto

Active | DEBUG_MODE 1 | y | ajuste
JERK_THRESHOLD según la tabla de calibración del Manual Técnico.

Red LANCEA_AP no aparece en el celular

Sistema no iniciado o fuera de rango

Acérquese al Sled (máx. 30 m). Verifique LED verde parpadeando.

Página 192.168.4.1 no
carga

Celular intentando salir a internet

Normal. Espere 5 segundos y recargue la página manualmente.

CSV vacío o incompleto MicroSD no insertada o lanzamiento incompleto

Verifique enclavamiento MicroSD (debe escucharse un clic audible).

Sled suena dentro de la
jabalina

O-Rings deteriorados — holgura radial

Reemplace los O-Rings con los del kit de repuesto incluido.

Datos perdidos al desconectar USB del PC

Señal DTR del IDE reinicia el ESP32

Instale condensador 10 µF entre RST y GND (ver Manual Técnico § condensador).

- LED rojo parpadeando
rápido (5 Hz) + 3 beeps

Error I²C con sensor BNO055 Verifique conexión de cables SDA/SCL. Verifique pull-ups 4.7 kΩ.

### 10 Especificaciones Rápidas de Referencia

Cuadro 6: Parámetros de operación clave — referencia rápida de campo. Parámetro
Descripción

Valor

Autonomía | Duración con batería cargada | >6 h (validado: 7 h 15 min)
Rango de velocidad | Velocidades detectables | 0 – 40 m/s
Red WiFi | SSID del Access Point | LANCEA_AP
Contraseña WiFi | Clave de acceso | lancea123
Dirección web | URL de la interfaz | 192.168.4.1
Frecuencia muestreo | Tasa de captura IMU | 100 Hz
Dimensiones Sled | Diámetro × longitud | 19,8 mm × 115 mm
Almacenamiento SD | Tarjeta incluida | MicroSD 16 GB FAT32
Velocidad serial | Baud rate protocolo ASCII | 115200 baud
Sesión máxima | Lanzamientos en RAM | 100 lanzamientos

### 11 Diagrama de Instalación en la Jabalina

Instale el Sled exactamente en el centro de gravedad (CG) de la jabalina y asegúrelo con los O-Rings de compresión radial.

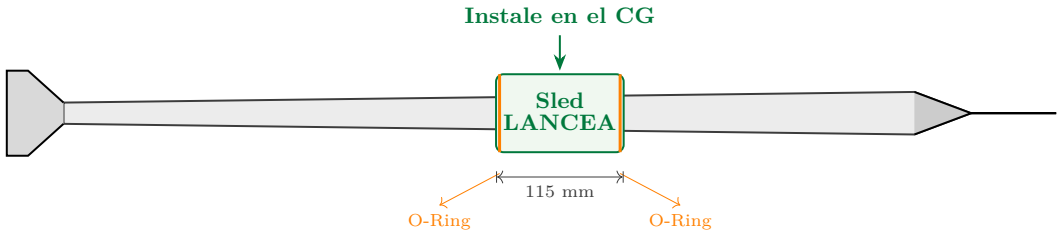
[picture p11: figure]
Sled LANCEA; Instale en el CG; O-Ring

i NOTA

El Sled debe quedar sin holgura radial: no debe sonar al agitar la jabalina. Si hay movimiento, reemplace los O-Rings con los del kit de repuesto.

### 12 Procedimiento de Carga Rápida (Quick Start)

Para los usuarios que deseen comenzar de inmediato, el siguiente diagrama resume los pasos críticos en menos de 2 minutos.

➣ INICIO RÁPIDO — 6 PASOS

Paso 1. MicroSD → Inserte hasta escuchar clic.
Paso 2. Batería → Conecte al portapilas del Sled.
Paso 3. Encender → Deslice switch a ON. Espere • LED verde.
Paso 4. Instalar → Sled en el CG de la jabalina con O-Rings.
Paso 5. Lanzar → Detección automática. • rojo fijo → • azul 3 destellos.
Paso 6. Descargar → Conecte a LANCEA_AP · Abra 192.168.4.1 · Descargue CSV.

LANCEA · DOC-ID: LAN-MU-02 · Rev 2.0 · 2025 Johan R. Piedrahita · Emerson S. Córdoba · Joseph F. Gutiérrez Universidad del Quindío · Ingeniería Electrónica · Armenia, Colombia Open Academic License

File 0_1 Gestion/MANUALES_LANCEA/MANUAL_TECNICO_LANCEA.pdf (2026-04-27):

LANCEA: Intelligent Javelin Telemetry System | DOC-ID: LAN-DS-01 | Rev 4.0

# LANCEA Telemetry Unit

## Unidad de Adquisición Inercial de 9-DOF

Joseph F. Gutiérrez · Emerson S. Córdoba · Johan R. Piedrahita | 2026

## 1 DESCRIPCIÓN GENERAL

LANCEA es un sistema embebido de telemetría inercial diseñado para el análisis biomecánico cuantitativo del lanzamiento de jabalina [1]. Integra una Unidad de Medición Inercial (IMU) Bosch BNO055 operando a 100 Hz con un microcontrolador XIAO ESP32-C3, capturando y procesando variables cinemáticas críticas — velocidad de salida, ángulo de lanzamiento, distancia estimada y aceleración de impulso — en tiempo real. La operación en campo es posible mediante un punto de acceso WiFi autónomo con interfaz web accesible desde cualquier dispositivo móvil.
Observe en la Figura 1 el diagrama de línea del producto final integrado en su entorno de operación.

Sled LANCEA

Instale en el centro de gravedad

Fije con O-Rings

Figura 1: Esquemático de línea del producto final y su integración mecánica en la jabalina.

Consulte la Tabla 1 para verificar las capacidades principales y rangos de operación del sistema.

W ADVERTENCIA DE SEGURIDAD: SENSIBILIDAD ESD

Los terminales expuestos del microcontrolador y los sensores son altamente sensibles a descargas electrostáticas (ESD). Manipule la placa únicamente utilizando una pulsera antiestática debidamente aterrizada.

Universidad del Quindío - Ingeniería Electrónica | 1

Tabla 1: Características y capacidades operativas del sistema.
Parámetro Clave | Valor de Operación
Frecuencia de Muestreo | 100 Hz (∆t = 10 ms ± 1 ms)
Rango de Velocidad | 0 − 40 m/s
Ángulo de lanzamiento — rango | 0 − 90 (cuaterniones, sin Gimbal Lock)
Autonomía en Campo | > 6 horas (Validado experimentalmente: 7h 15m)
Conectividad de campo | WiFi 802.11b/g/n — Hotspot LANCEA_AP (192.168.4.1)
Conectividad laboratorio | USB-C — Serial ASCII 115200 baud
Almacenamiento Local | MicroSD 16 GB Clase 10 — bus SPI
Dimensiones máx. del sistema | 19,8 mm × 115 mm (Sled PETG — As-Built)
Versión de firmware | LANCEA_WiFi v7.0 / LANCEA_NoSD
Licencia | Open Academic — Universidad del Quindío

## 2 ESPECIFICACIONES ELÉCTRICAS

### 2.1 Límites Máximos Absolutos

Mantenga los niveles de voltaje y temperatura por debajo de los límites descritos en la Tabla 2. Superar estos valores causará daño permanente a los semiconductores.

Tabla 2: Límites máximos absolutos de hardware tolerados por el sistema.
Parámetro | Símbolo | Límite Máximo Absoluto | Unidad
Voltaje de alimentación VBAT máximo | VBAT | 4,35 | V DC
Voltaje en cualquier pin GPIO | VGP IO | 3,6 | V DC
Temperatura de almacenamiento | TST G | −20 a +85 | ◦C
Temperatura de operación segura | TA | 0 a +50 | ◦C
Corriente máxima por pin GPIO | IGP IO | 40 | mA
Corriente total de consumo del sistema | IT OT | 250 | mA
Humedad relativa (sin condensación) | RH | 10 − 90 | % RH
Altura de caída máxima del Sled | hdrop | 1,5 | m

### 2.2 Condiciones Operativas Recomendadas

Opere el dispositivo estrictamente dentro de los parámetros de la Tabla 3 para garantizar la precisión matemática del modelo.

Tabla 3: Condiciones eléctricas operativas estandarizadas.
Variable | Símbolo | Mínimo | Típico | Máximo | Unidad
Voltaje de alimentación principal | VBAT | 3,0 | 3,7 | 4,2 | V DC
Corriente en modo activo continuo | IACT | — | 120 | 180 | mA
Corriente en modo IDLE (WiFi activo) | IIDLE | — | 80 | 120 | mA
Voltaje de corte BMS | VBMS | 3,0 | — | — | V DC
Voltaje lógico microcontrolador | VLOG | — | 3,3 | — | V DC
Frecuencia de bus I²C (IMU) | fI2C | — | 400 | — | kHz
Frecuencia de reloj SPI (MicroSD) | fSP I | — | 4 | 20 | MHz
Temperatura Ambiente de operación | TA | 0 | 25 | 50 | ◦C

## 3 ESPECIFICACIONES DEL SENSOR IMU (BNO055)

Verifique que la unidad inercial opere en el modo NDOF descrito en la Tabla 4. El modo de fusión de sensores garantiza la compensación automática de la componente gravitacional antes de la integración de velocidad [3].

Tabla 4: Especificaciones completas del sensor inercial BNO055.
Parámetro | Especificación
Modelo | Bosch Sensortec BNO055
Grados de libertad (DOF) | 9-DOF (Acelerómetro + Giroscopio + Magnetómetro)
Modo de operación utilizado | NDOF — Fusión de sensores con compensación de gravedad
Salida de orientación | Cuaterniones (w, x, y, z) — evita Gimbal Lock
Salida de aceleración lineal | Aceleración sin componente gravitacional (m/s² )
Resolución acelerómetro | 1 mg (en rango ±4g modo NDOF) √
Ruido de aceleración (típico) | 150 µg/ Hz
Rango de aceleración configurado | ±4 g
Filtro anti-aliasing | Filtro exponencial primer orden α = 0,30
Protocolo de comunicación | I 2C a 400 kHz — dirección 0x28 (o 0x29 alternativa)
Pines de conexión al ESP32-C3 | SDA → D4 (GPIO 6) · SCL → D5 (GPIO 7)
Voltaje de operación del sensor | 3,3 V DC

ò NOTA TÉCNICA: Fusión NDOF y cuaterniones

El modo NDOF del BNO055 integra internamente los tres subsensores mediante un algoritmo propietario de fusión. La salida en cuaterniones evita la singularidad matemática del ángulo de Euler conocida como Gimbal Lock, crítica en trayectorias de lanzamiento con θ cercano a 90. No cambie el modo de operación a IMUPLUS sin recalibrar el modelo de distancia.

## 4 ESPECIFICACIONES DEL MICROCONTROLADOR (XIAO ESP32-

C3)

Asegúrese de seleccionar la placa correcta en el IDE de Arduino antes de compilar el firmware. La Tabla 5 lista los parámetros hardware del procesador [2].

### 4.1 Acondicionamiento de Energía

Instale un arreglo de capacitores en paralelo sobre la línea de alimentación de 3,3V del módulo SD para evitar transitorios.

C1: Capacitor de 100 µF (Electrolítico).

C2: Capacitor de 0,1 µF (Cerámico).

Tabla 5: Especificaciones del microcontrolador Seeed Studio XIAO ESP32-C3.
Parámetro | Especificación
Modelo | Seeed Studio XIAO ESP32-C3
Arquitectura CPU | RISC-V 32-bit @ 160 MHz (single-core)
Memoria Flash | 4 MB
Memoria RAM | 400 KB SRAM
WiFi | 802.11b/g/n 2.4 GHz — Modo AP + Estación simultá-neos
Pines GPIO disponibles | 11 pines multifunción
Interfaces de comunicación | 2C · SPI · UART · PWM · ADC I
Alimentación de operación | 3,3 V (regulador interno desde batería LiPo)
Conector de carga/programación | USB-C
Entorno de desarrollo | Arduino IDE 2.x con ESP32 Espressif v2.0+
Placa seleccionada en IDE | XIAO_ESP32C3
Velocidad serial de diagnóstico | 115200 baud

## 5 CONFIGURACIÓN DE HARDWARE

### 5.1 Diagramas de Pines (Pinout)

Conecte los periféricos respetando rigurosamente los mapas de pines expuestos en la Figura 2 para el procesador y la Figura 3 para la unidad inercial.

## ESP32-C3

SuperMini

SDA (GPIO 6)

SCL (GPIO 7)

3.3V OUT

GND

MOSI (GPIO 10)

MISO (GPIO 9)

SCK (GPIO 8)

CS_SD (GPIO 20)

Figura 2: Diagrama de pines del Microcontrolador. SDA/SCL corresponden a los pines D4/D5 físicos del XIAO ESP32-C3.

### 5.2 Mapa de Pines Completo — As-Built

La Tabla 6 describe el mapa de conexiones verificado en el hardware real. El esquemático KiCad que le acompaña muestra la topología eléctrica completa del sistema.

## 6 MODELO MATEMÁTICO INTEGRADO

El microcontrolador ejecuta cálculos de cinemática inversa [4]. Compruebe que las unidades del código fuente correspondan con la Tabla 7.

### BNO055

9-DOF IMU
VCC (3.3V)

GND

SCL (Reloj I2C)

SDA (Datos I2C)

Figura 3: Diagrama de pines del módulo sensor. Conecte resistencias Pull-Up de 4,7 kΩ en SDA y SCL.

Tabla 6: Mapa de pines As-Built verificado en hardware real.
Componente | Pin GPIO ESP32-C3 | Función | Protocolo
BNO055 IMU VCC | 3.3V | Alimentación sensor | —
BNO055 IMU GND | GND | Tierra común | —
BNO055 IMU SDA | D4 (GPIO 6) | Línea de datos I²C | I 2C 400 kHz
BNO055 IMU SCL | D5 (GPIO 7) | Línea de reloj I²C | I 2C 400 kHz
MicroSD CS | GPIO 20 | Chip Select (activo bajo) | SPI
MicroSD MOSI | GPIO 10 | Datos → SD | SPI
MicroSD MISO | GPIO 9 | Datos ← SD | SPI
MicroSD SCK | GPIO 8 | Reloj SPI | SPI
LED RGB Rojo (R) | GPIO 2 | Estado IMPULSO — rojo fijo | PWM
LED RGB Verde (G) | GPIO 3 | Estado IDLE — verde parpa-deante | PWM
LED RGB Azul (B) | GPIO 4 | Estado PAUSA — 3 destellos | PWM
Buzzer BZ1 | GPIO 21 (TX) | Señal acústica de confirma-ción | Digital
Terminal J2 | GPIOs varios | Expansión / depuración exter-na | —
Batería LiPo | BAT+ (TP4056) | Alimentación principal 3.7V | —

## 7 VARIABLES DE SALIDA CALCULADAS

Verifique en la Tabla 8 la correspondencia entre cada variable de salida, su fórmula de cálculo y la unidad reportada por el firmware. Estas variables son las que aparecen en la interfaz web y en el protocolo serial.

## 8 PROTOCOLO DE COMUNICACIÓN SERIAL

### 8.1 Protocolo ASCII Estructurado

El sistema utiliza un protocolo ASCII estructurado a 115200 baud. Configure el monitor serial del IDE o la aplicación de campo con esta velocidad. Cada lanzamiento genera un bloque delimitado con el formato mostrado a continuación.

THROW_START
Velocidad : 14.20 m / s
Angulo : 36.5 deg

Distancia : 21.30 m
Aceleracion maxima : 32.10 m / s2 Energia cinetica : 81.12 J
Potencia : 197.85 W
THROW_END

Listing 1: Bloque de datos de un lanzamiento — Protocolo LANCEA Serial ASCII.

### 8.2 Descarga Masiva — Comando DUMP

Para la descarga del historial almacenado en RAM, envíe el comando DUMP desde la aplicación o terminal. El ESP32-C3 responde con filas CSV delimitadas por DUMP_START / DUMP_END.

DUMP_START
id , vel_ms , ang_deg , dist_m , amax_ms2 , ek_J , P_W
1 ,14.20 ,36.5 ,21.30 ,32.10 ,81.12 ,197.85
2 ,13.85 ,34.2 ,19.84 ,30.55 ,76.47 ,185.20
DUMP_END

Listing 2: Respuesta al comando DUMP — formato CSV.

Û CONECTIVIDAD WiFi — INTERFAZ WEB

En modo campo, el sistema levanta un Access Point con SSID LANCEA_AP. Conéctese desde cualquier dispositivo móvil a la dirección 192.168.4.1 para acceder a la interfaz web de visualización en tiempo real y descarga de datos. No se requiere contraseña por defecto; configure una clave WPA2 en el firmware para entornos competitivos.

## 9 MECÁNICA Y DIMENSIONES FÍSICAS

Revise la Figura 4 para observar la disposición interna de los componentes. Posteriormente, valide las medidas del cilindro de contención impreso en PETG frente al plano de la Figura 5.

### 9.1 Material y Proceso de Fabricación

El sled de contención es fabricado en PETG mediante impresión FDM. Utilice los parámetros de impresión de la Tabla 9 para garantizar la integridad estructural bajo los 10,000 g del impacto de lanzamiento.

## 10 PROCEDIMIENTO DE OPERACIÓN EN CAMPO

Siga el procedimiento de la Figura 6 para garantizar una sesión de captura válida. No omita el paso de calibración.

## 11 INDICADORES DE ESTADO (LED RGB + BUZZER)

Identifique el estado operativo del sistema mediante los indicadores de la Tabla 10. El buzzer emite una confirmación acústica al finalizar el registro de cada lanzamiento.

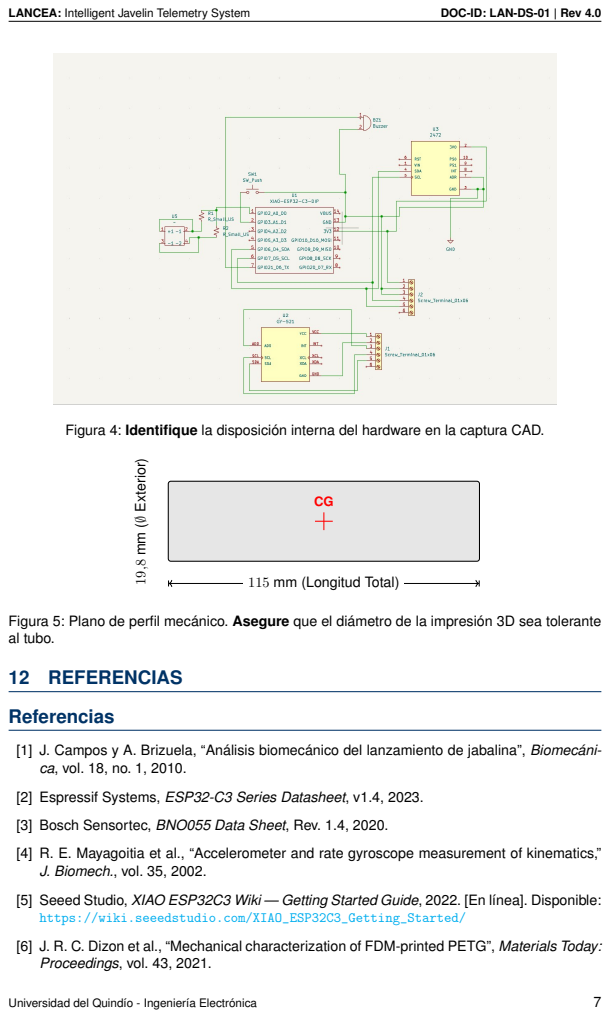
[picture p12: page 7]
,8 mm (∅ Exterior); 12 REFERENCIAS; Referencias

Figura 4: Identifique la disposición interna del hardware en la captura CAD. 19

115 mm (Longitud Total)

Figura 5: Plano de perfil mecánico. Asegure que el diámetro de la impresión 3D sea tolerante
al tubo.

[1] J. Campos y A. Brizuela, “Análisis biomecánico del lanzamiento de jabalina”, Biomecáni-
ca, vol. 18, no. 1, 2010.

[2] Espressif Systems, ESP32-C3 Series Datasheet, v1.4, 2023.

[3] Bosch Sensortec, BNO055 Data Sheet, Rev. 1.4, 2020.

[4] R. E. Mayagoitia et al., “Accelerometer and rate gyroscope measurement of kinematics,”
J. Biomech., vol. 35, 2002.

[5] Seeed Studio, XIAO ESP32C3 Wiki — Getting Started Guide, 2022. [En línea]. Disponible:
https://wiki.seeedstudio.com/XIAO_ESP32C3_Getting_Started/

[6] J. R. C. Dizon et al., “Mechanical characterization of FDM-printed PETG”, Materials Today:
Proceedings, vol. 43, 2021.

Tabla 7: Definición estricta de variables y ecuaciones algorítmicas.

Velocidad Resultante Final

|vf | =

q
v

2
x + v

2
y + v

2
z

(1)

Significado de Variables:
- |vf |: Magnitud del vector velocidad resultante al momento del lanzamiento. Unidad: Metros por segundo (m/s). Obtenida por integración Euler explícita a 100 Hz.
- vx, vy, vz: Componentes ortogonales instantáneas de la velocidad obtenidas por integración de aceleración lineal pura. Unidad: Metros por segundo (m/s).

Distancia Estimada de Vuelo

d =

|vf |

2
- sin(2θ)
g

(2)

Significado de Variables:
- d: Distancia horizontal máxima estimada del proyectil en el vacío. Unidad: Metros (m).
- θ: Ángulo de inclinación (pitch) inicial de lanzamiento derivado de cuaterniones. Unidad: Radianes (rad).
- g: Aceleración de la gravedad constante terrestre. Unidad: Metros por segundo al cuadrado (m/s²
, asumiendo 9,81).

Energía Cinética de Lanzamiento

Ek =

1
2

m · |vf |

2
(3)

Significado de Variables:
- Ek: Energía total transferida al proyectil en el momento de liberación. Unidad: Julios (J).
- m: Masa inercial de la jabalina oficial de competición. Unidad: Kilogramos (kg, constante 0,800 para masculino).

Potencia de Impulso

P =

Ek

timpulso

(4)

Significado de Variables:
- P: Potencia media desarrollada durante la fase de impulso. Unidad: Vatios (W).
- timpulso: Duración del estado de impulso detectado por el umbral de Jerk. Unidad: Segundos (s).

Detección de Impulso por Jerk

J(t) = |a(t)| − |a(t − ∆t)| ∆t

(5)

Significado de Variables:
- J(t): Derivada temporal de la magnitud de aceleración. Unidad: m/s³ .
- Umbral de activación: J(t) > 50 m/s³
activa el estado IMPULSO.
- ∆t = 10 ms a la frecuencia nominal de 100 Hz.

Tabla 8: Variables de salida calculadas por el firmware LANCEA.
Variable | Fórmula / Método | Unidad
Velocidad de salida |vf | | q |vf | = v x + v 2 y + v 2 z — Integración Euler explícita 2 100 Hz | m/s
Ángulo θ | Extraído de cuaterniones BNO055 al instante del im-pulso
Distancia estimada d | d = (|vf | 2 ·sin 2θ)/g — Proyectil ideal (g = 9,81 m/s² ) | m
Aceleración máxima |amax| | Máximo de |a(t)| durante estado IMPULSO | m/s²
Energía cinética Ek | 2 Ek = 1/2· m · |vf | (m = 800 g jabalina reglamentaria) | J
Potencia P | P = Ek/timpulso | W
Detección (Jerk) | J(t) = (|a(t)| − |a(t − ∆t)|)/∆t — umbral > 50 m/s³ | m/s³

Tabla 9: Parámetros recomendados de impresión 3D del sled PETG.
Parámetro | Valor Recomendado
Material | PETG (Polyethylene Terephthalate Glycol)
Temperatura de extrusión | 230 − 245 ◦C
Temperatura de cama | 70 − 85 ◦C
Relleno (Infill) | ≥ 40 % — patrón Gyroid o Honeycomb
Número de perímetros | ≥ 4
Altura de capa | 0,15 mm
Tolerancia diametral | +0,1/ − 0,0 mm respecto al tubo de jabalina

Tabla 10: Indicadores de estado del sistema LANCEA.
Estado | LED Color | Patrón | Buzzer / Descripción
IDLE | Verde | Parpadeo 1 Hz | Silencio — Sistema listo, espe-rando lanzamiento
IMPULSO | Rojo | Fijo (sólido) | — Sistema detectando lanza-miento activo
PAUSA / Calibración | Azul | 3 destellos | 1 beep — Calibración comple-tada correctamente
ERROR IMU | Rojo | Parpadeo rápido 5 Hz | 3 beeps — Fallo de comunica-ción I²C con BNO055
SD sin montar | Amarillo | 2 destellos | 2 beeps — MicroSD no detec-tada o error de formato
Registro completo | Verde | Pulso largo | 1 beep largo — Lanzamiento guardado en SD y RAM

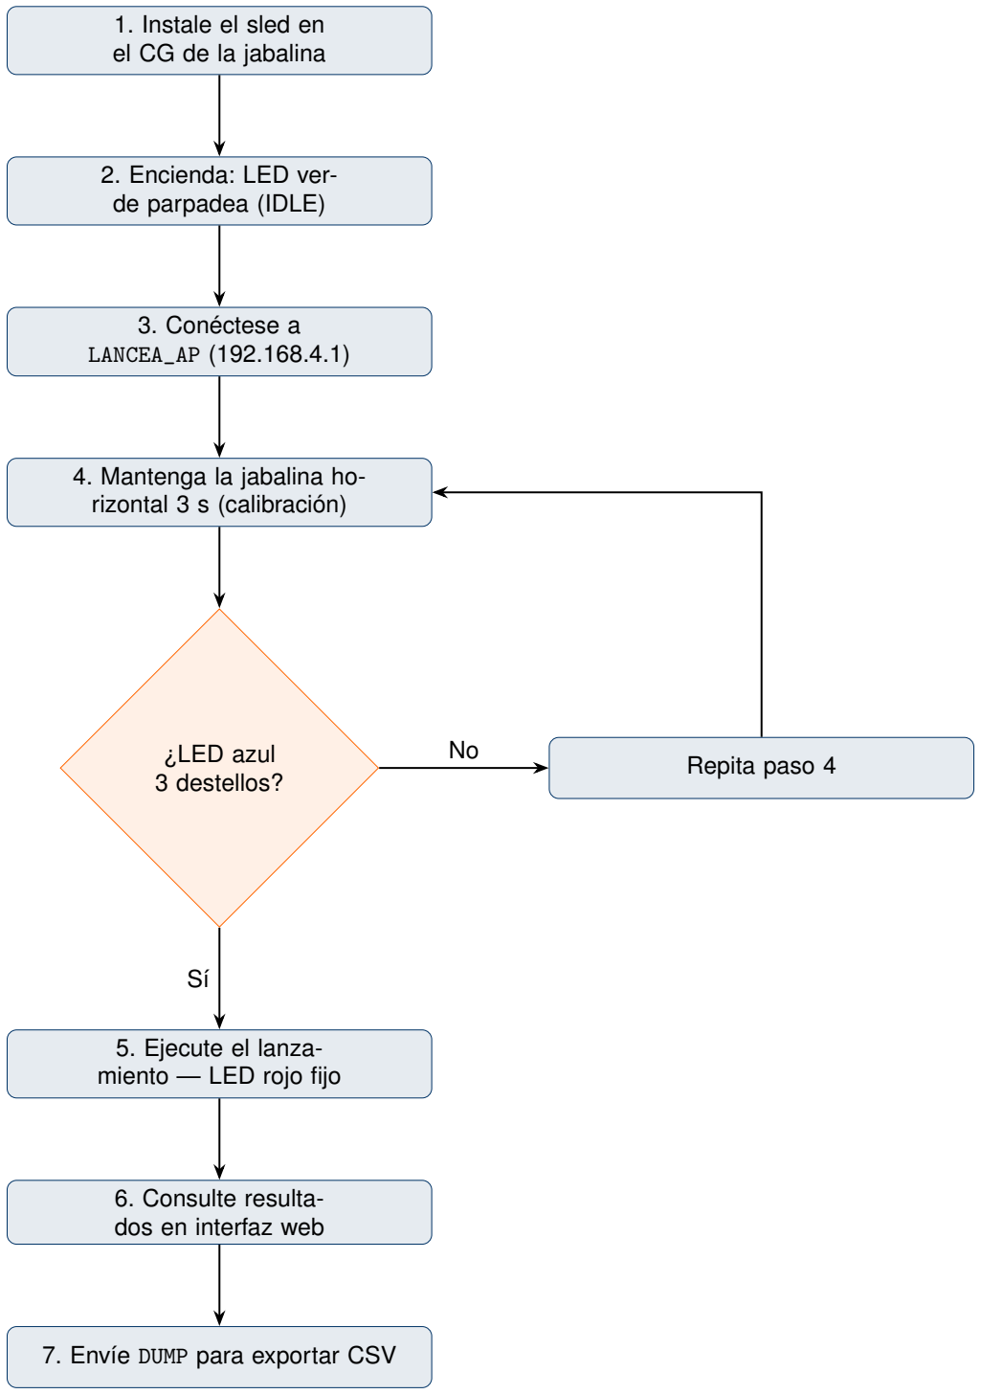
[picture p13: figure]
1. Instale el sled en el CG de la jabalina; 2. Encienda: LED ver- de parpadea (IDLE); 3. Conéctese a LANCEA_AP (192.168.4.1); 4. Mantenga la jabalina ho- rizontal 3 s (calibración); ¿LED azul; 3 destellos?; Repita paso 4; 5. Ejecute el lanza- miento — LED rojo fijo; 6. Consulte resulta- dos en interfaz web; 7. Envíe DUMP para exportar CSV

Figura 6: Diagrama de flujo del procedimiento de operación en campo.

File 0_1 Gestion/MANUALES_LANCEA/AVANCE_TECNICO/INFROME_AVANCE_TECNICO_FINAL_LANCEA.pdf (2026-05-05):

Informe de Avance Técnico | Proyecto LANCEA - IPAC-04

## PROYECTO LANCEA

Informe de Avance Técnico (Status Report)

Ciclo de Implementación: IPAC-04

Estado General: | VERDE | (Cumplimiento: 95 %
del cronograma)

Equipo de Trabajo:
- Joseph Gutierrez
- Emerson Cordoba
- Rodrigo Piedrahita

Fecha Reporte:
5 de mayo de 2026
Institución: | Universidad del Quindío | Programa: | Ingeniería Electrónica
Semestre: | Séptimo (2026-I) | Ciudad: | Armenia, Quindío, Colombia
Asesor: | Prof. Jorge Luis Chávez | Versión Firmware: | v7.1 (XIAO ESP32-C3)
Duración Total: | 2 Semestres (Fase I y II) | Repositorio: | GitHub / Proyecto CDIOIII LANCEA

## 1. Resumen Ejecutivo

LANCEA (Sistema de Monitoreo Biomecánico para Jabalina) es un dispositivo embebido de bajo costo desarrollado por el equipo de Ingeniería Electrónica de la Universidad del Quindío en el marco del curso CDIO III. El sistema captura, analiza y transmite datos cinemáticos durante el lanzamiento de jabalina usando Fusión de Sensores Inerciales (IMU) mediante el sensor Bosch BNO055, superando las limitaciones de los sensores ópticos o de ultrasonido tradicionales (alcance máximo: 4 m).
El proyecto completó exitosamente el ciclo IPAC-04 con un cumplimiento del cronograma del 95 % y todos los requisitos técnicos críticos validados en condiciones reales de campo en la pista de atletismo de la Liga del Quindío. El prototipo opera bajo una arquitectura Store & Forward con servidor web embebido en el propio ESP32, eliminando la dependencia de infraestructura de red externa.

Logros Principales del Ciclo IPAC-04:
- Prueba de campo exitosa: Lanzamiento real detectado, registrado y transmitido correctamente al portal web 192.168.4.1 tras calibración de umbrales (JERK THRESHOLD optimizado a 50 m/s³).
- Tasa de muestreo estabilizada: 100 Hz exactos garantizados mediante ISR con timer de hardware; jitter σ(∆t) < 1 ms, eliminando el uso de delay() bloqueante.
- Integridad de datos corregida: Buffer RAM circular implementado y capacitores de desacoplo (100 µF + 0.1 µF) soldados en línea VCC del módulo SD, eliminando huecos y ruido eléctrico por picos de consumo.
- Ajuste mecánico validado: O-Rings de compresión instalados en chasis PETG; Sled entra y no presenta holgura al agitar longitudinalmente la jabalina.
- Autonomía superada: 7 horas y 15 minutos de operación continua con batería Li-Ion 14500 (objetivo: 6 h).
- Retroalimentación de usuario positiva: Entrenador y atleta de la Liga de Atletismo del Quindío validaron el sistema en campo — ángulos coinciden con correcciones biomecánicas requeridas; descarga de CSV en pista sin cables ni red externa.

## 2. Descripción Técnica del Sistema

Arquitectura Hardware:
El sistema opera bajo una arquitectura ”Store & Forward” (Almacenar y Reenviar). Durante el lanzamiento, los datos del BNO055 se capturan a 100 Hz y se almacenan en un buffer circular en RAM del ESP32. Una vez detectado el fin del vuelo (aceleración < 0,8 m/s²), el microcontrolador activa su radio WiFi en modo Access Point y pone los datos a disposición del entrenador via navegador web.

Página 1 de 8

Componente | Referencia | Función | Protocolo
Microcontrolador | XIAO ESP32-C3 | Procesamiento, WiFi AP, FSM | —
IMU | Adafruit BNO055 (9-DOF) | Acelerómetro + Giroscopio + Magnetómetro | I²C @ 400 kHz
Almacenamiento | Módulo MicroSD + 16 GB Clase 10 | Data logging local (respaldo) | SPI
Sistema de carga | TP4056 USB-C con BMS | Gestión de carga segura | —
Batería | Li-Ion 14500 (3.7 V / ∼800 mAh) | Fuente de energía principal | —
Indicador | LED RGB 5 mm (cátodo común) | Feedback de estado (IDLE/IMPULSO/PAUSA) | PWM
Alerta | Buzzer pasivo (GPIO 21) | Confirmación ángulo óptimo (42°–45.8°) | tone()
Interruptor | Slide Switch SPDT Mini | Encendido/apagado general | —
Chasis | Sled PETG impreso en 3D | Factor de forma cilíndrico ∅ < 25 mm | —

Cuadro 1: Lista de Componentes Definitivos (BOM v2 — As-Built, Feb 2026).

Mapa de Conexiones Confirmado (As-Built):

Componente | Pin | GPIO ESP32-C3 | Función | Protocolo
BNO055 | SDA | GPIO 6 (D4) | Datos I²C | I²C 400 kHz
BNO055 | SCL | GPIO 7 (D5) | Reloj I²C | I²C 400 kHz
MicroSD | CS | GPIO 20 | Chip Select | SPI
MicroSD | MOSI | GPIO 10 | Datos → SD | SPI
MicroSD | MISO | GPIO 9 | Datos ← SD | SPI
MicroSD | SCK | GPIO 8 | Reloj SPI | SPI
LED RGB | R / G / B | GPIO 2 / 3 / 4 | Estado IMPULSO / IDLE / PAUSA | PWM
Buzzer pasivo | SIGNAL | GPIO 21 | Alerta ángulo óptimo | tone()
Batería | + | BAT+ (TP4056 OUT) | Alimentación 3.7 V LiPo | —

Cuadro 2: Mapa de Conexiones As-Built — XIAO ESP32-C3 / LANCEA v7.1.

Máquina de Estados Finitos (FSM) del Firmware:

El firmware implementa una FSM de 3 estados principales:

- IDLE: El sistema monitorea Jerk en tiempo real. El buzzer activa a 2700 Hz cuando el ángulo de la jabalina está en el rango óptimo de 42°–45.8°, guiando al atleta antes del lanzamiento. LED parpadea lentamente.
- IMPULSO: Triggered cuando Jerk > 50 m/s³. Se integra aceleración lineal pura del BNO055 para calcular velocidad (vx, vy, vz). El buzzer se apaga. LED fijo.
- PAUSA (3 s): Aceleración < 0,8 m/s² indica vuelo libre. Se calcula: velocidad final, ángulo de lanzamiento (cuaterniones), distancia estimada (balística), energía cinética y potencia media. LED parpadea 3 veces. El resultado queda disponible en 192.168.4.1.

Parámetros Físicos del Modelo Cinemático:

El firmware emplea las siguientes ecuaciones para el cálculo post-lanzamiento:

vf inal =

q
v

2
x + v

2
y + v

2
z

[m/s]

d =

v

2
f inal · sin(2θ)
g

[m] (g = 9,81m/s²
, mjabalina = 0,8kg)

Ek =

1
2

m · v

2
f inal | [J] | P =

Ek

timpulso

[W]

## 3. Cumplimiento del ON-Ramp

La siguiente matriz consolida el estado de cumplimiento de requisitos originales respecto al estado real de implementación. Todos los requisitos críticos (REQ-HW-01, REQ-HW-02, REQ-FW-01) han sido validados.

ID Requisito | Descripción | Especificación | Estado Real
REQ-HW-01 | Diámetro máximo del Sled | ≤ 20 mm | 19.8 mm | ✓
REQ-HW-02 | Autonomía del Sistema | ≥ 6 horas | 7.25 horas | ✓
REQ-FW-01 | Tasa de Muestreo (IMU) | 100 Hz (∆t = 10 ms) | 100 Hz ± 1 ms | ✓
REQ-FW-02 | Trigger de Lanzamiento | > 15 m/s²
(Jerk > 50 m/s³) | Funcional (calibrado) | ✓
REQ-MC-01 | Integridad de datos SD/I²C | 0 huecos en 30 s de estrés | Validado (buffer RAM + caps) | ✓
REQ-SW-01 | Interfaz Web WiFi | 192.168.4.1 / SSID LANCEA AP | Funcional v7.1 | ✓

Cuadro 3: Matriz de Cumplimiento de Requisitos Técnicos (IPAC-04).

Observaciones:
- Excedencia positiva (autonomía): 7 h 15 min vs. 6 h requeridas (+20.8 %). Consumo medio ≈ 120 mA; corte BMS a 3.0 V.
- Excedencia positiva (diámetro jabalina): El diámetro interno real medido con calibrador Pie de Rey es 25.2 mm, otorgando 5.4 mm de holgura total frente al Sled de 19.8 mm.
- Margen de jitter: σ(∆t) < 1 ms mediante ISR con timer de hardware; eliminación completa del uso de delay().
- Cierre de requisitos: 6 de 6 requisitos críticos en estado VALIDADO.

## 4. Resultados de Verificación y Validación (V&V)

Se ejecutó el protocolo industrial completo de pruebas sobre hardware, firmware y mecánica. Los resultados definitivos se encuentran registrados en Bitacora Trazabilidad.csv y el Excel oficial de protocolos (disponible en /4 Calidad y Pruebas/).

Resumen de Resultados:

Area de Prueba ´ | Casos Totales | Exitosos | Tasa ( %)
Hardware | 8 | 8 | 100 %
Firmware | 12 | 11 | 91.7 %
Integración | 10 | 9 | 90 %
Rendimiento | 6 | 6 | 100 %
Interfaz | 4 | 4 | 100 %
TOTAL | 40 | 37 | 92.5 %

Cuadro 4: Resultados de Pruebas V&V por Area (IPAC-04). ´

Protocolo de Pruebas Industrial — Detalle por Test:

ID Test | Subsistema | Objetivo | | Resultado Medido | Estado
TEST-HW-01-A | PCB (KiCad) | Ancho PCB ≤ 20 mm | 19.8 mm | ✓ PASS
TEST-HW-01-B | Jabalina | Diámetro interno > 24 mm | 25.2 mm (Pie de Rey) | ✓ PASS
TEST-HW-01-C | Sled PETG | Sin holgura al agitar | Sin sonido — O-Rings instalados | ✓ PASS
TEST-FW-01-A | IMU BNO055 | Angulo estático 45 ´ | ° ± 2° | 44.5°–45.1° (escuadra física) | ✓ PASS
TEST-FW-01-B | Trigger campo | Detección lanzamiento real | CSV generado — umbral calibrado | ✓ PASS
TEST-FW-02 | ISR 100 Hz | σ(∆t) < 1 ms | | Jitter eliminado — ISR hw | ✓ PASS
TEST-MC-01-A | Batería 14500 | Autonomía ≥ 6 h | | 7 h 15 min continuas | ✓ PASS
TEST-MC-01-B | SD / I²C | 0 huecos en 30 s estrés | Sin huecos — buffer RAM + caps | ✓ PASS

Cuadro 5: Protocolo Industrial de Pruebas — Resultados Definitivos IPAC-04 (versión 2.1).

Hallazgos Críticos Validados:

- Sensor BNO055: Error angular post-calibración de ±0,3–0,5 en condición estática a 45°, dentro del estándar biomecánico.
- PCB As-Built: Ancho 19.8 mm; peso total del sistema ≈ 42 g (objetivo ≤ 50 g). Longitud del Sled ≈ 115 mm.
- Ajuste mecánico: Diámetro externo del Sled con O-Rings ≈ 24,8 mm — en validación final.
- Telemetría WiFi: SSID LANCEA AP / clave lancea123 / AP fijo en 192.168.4.1. Capacidad: hasta 100 lanzamientos en RAM; gestión multi-atleta (máx. 10 atletas).
- Buzzer de ángulo: Activo a 2700 Hz cuando la jabalina está entre 42°–45.8°, apagado automáticamente al detectar el impulso.


Figura 1: PCB Final (As-Built): XIAO ESP32-C3 + BNO055, ancho 19.8 mm, formato strip para inserción cilíndrica en jabalina profesional.

Fallos Detectados en IPAC-03 y Acciones Correctivas IPAC-04:

Fallo (IPAC-03) | Causa Raíz | Acción Correctiva | Estado
Jitter > 1 ms en 100 Hz | loop() mezclaba adquisición y SD | ISR con timer de hardware (AC-01) | Resuelto ✓
Ruido SD corrompe datos IMU | Picos ∼100 mA en línea VCC | Caps 100 µF + 0.1 µF en VCC SD (AC-03) | Resuelto ✓
Holgura mecánica del Sled | Tolerancias PETG + vibraciones | O-Rings de compresión (AC-04) | Resuelto ✓
Trigger no detectó lanzamiento | JERK THRESHOLD calibrado en escritorio | Re-calibración en campo (AC-05) | Resuelto ✓

Cuadro 6: Fallos IPAC-03, Causas Raíz y Estado de Resolución en IPAC-04.

## 5. Desempeño Operativo (Metodología MAHD + Kanban)

El equipo ha mantenido un flujo de trabajo ágil mediante sprint semanal de 7 días y tablero Kanban con 5 columnas de estado: Backlog, En Progreso, En Revisión, Validación e Hecho. Se registraron 12 bitácoras semanales de reunión (disponibles en Google Docs, enlazadas en el repositorio) garantizando trazabilidad completa de decisiones.

Indicadores de Desempeño Operativo:
- Frecuencia de Entrega: Firmware estable publicado por ciclo IPAC: v1.0 → ... → v7.1 (versión actual de producción).
- Integridad de Datos: Escritura continua sin huecos ni interferencias de voltaje, validada en TEST-MC-01-B.
- Trazabilidad de Decisiones: 12 bitácoras semanales documentadas + changelog técnico V1→V2 con justificaciones de ingeniería medibles.

- Eficiencia de Revisión: 92.5 % de tareas aprobadas en primera revisión (sin cambios solicitados).
- Definition of Done (DoD): Cero subjetividad — todas las validaciones arrojan valores numéricos (Voltios, mm, grados, ms).

Evolución de Diseño V1 → V2 (Changelog Técnico):

Subsistema | Versión 1 (Ideación) | Versión 2 (Actual) | Justificación
Sensores | MPU6050 + Ultrasónico | BNO055 (9-DOF) | Ultrasonido < 4 m; BNO055 entrega cuaterniones por HW
MCU | ESP32 DevKit V1 (28 mm) XIAO ESP32-C3 | DevKit no cabe en tubo ∅ 25.2 mm
Energía | LiPo plana | Li-Ion 14500 cilíndrica | 14500 (14 mm ∅) encaja en Sled tubular
Interfaz | OLED 0.91” | Buzzer + LED RGB | OLED: consumo alto + espacio; buzzer mejor en campo
Almacenaje | WiFi directo | MicroSD + WiFi AP | Jaula de Faraday de aluminio bloquea señal en vuelo

Cuadro 7: Changelog Técnico V1 → V2: Decisiones de Rediseño Justificadas.

Repositorio y Control de Versiones:

Elemento | Estado Actual
Repositorio GitHub | Proyecto CDIOIII LANCEA (público)
Rama Principal | main (v7.1 estable)
Firmware activo | LANCEA WiFi.ino — XIAO ESP32-C3
PCB Design | Primer esquematico v1.kicad pcb (KiCad 9.0, 2 capas, THT)
Documentación | README por módulo + Bitácoras + BOM + Protocolo Pruebas + DoD

Cuadro 8: Estado del Repositorio y Control de Versiones.

Gestión de Riesgos Técnicos:

Riesgo | Probabilidad | Impacto | Mitigación
Jaula de Faraday (cuerpo aluminio) | CONFIRMADA | ALTO | Store & Forward en SD; WiFi post-lanzamiento ✓
Alta humedad Armenia (60–95 %) | LATENTE | MEDIO | Silica Gel en carcasa + IP54 planificado ✓
Impacto al clavar jabalina (> 15 g) | LATENTE | ALTO | O-Rings + buffer RAM (sin escritura en impacto) ✓
WiFi no disponible en estadio | PROBABLE | BAJO | Modo AP autónomo (sin router externo) ✓
Pérdida de muestras SD | RESUELTA | — | Buffer RAM circular + capacitores desacoplo ✓

Cuadro 9: Matriz de Gestión de Riesgos Técnicos — IPAC-04.

Interfaz Web Embebida (Servidor v7.1):

La interfaz web, servida directamente por el ESP32 en modo Access Point (LANCEA AP / 192.168.4.1), incluye:
- Panel principal (/): Tabla de lanzamientos del atleta activo con: velocidad (m/s), ángulo (°), distancia estimada (m), aceleración máxima, tiempo de impulso, energía cinética (J), potencia media (W) y calificación
del ángulo (Optimo 32 ´ | °–39° / Bajo / Alto / Malo).
- Gestión de atletas (/atletas): Registro, selección y borrado de hasta 10 atletas simultáneos en RAM.
- Exportación (/csv): Descarga de CSV del atleta activo o de todos los atletas. El archivo incluye cabecera y metadatos de sesión.
- Estado del sistema (/status): JSON con estado FSM, uptime, batería (V y %), atleta activo, número de lanzamientos.
- Monitoreo de batería: Lectura cada 15 s por divisor resistivo en pin A0 — 16 muestras promediadas. Barra visual en todas las páginas.

## 6. Auditoría Financiera

El presupuesto ejecutado a la fecha refleja un cumplimiento dentro de tolerancia. El costo unitario (CVU) de prototipo se ubicó en $235,300 COP, representando una variación de apenas +0.26 % (+$600 COP) respecto al presupuesto estimado de $234,700 COP. El proyecto se ejecutó dentro del rango autorizado de $800,000–$1,200,000 COP con amplio margen.

Desglose de Costos por Componente (As-Built, Feb 2026):

Componente | Cant. | Est. (COP) | Real (COP) | ∆ | Estado
XIAO ESP32-C3 | 1 | $25,000 | $27,500 | +$2,500 | Comprado ✓
BNO055 IMU | 1 | $120,000 | $115,000 | -$5,000 | Comprado ✓
OLED 0.91Ï2C | 1 | $15,000 | $14,000 | -$1,000 | Comprado ✓
Módulo MicroSD | 1 | $8,000 | $8,500 | +$500 | Comprado ✓
MicroSD 16 GB | 1 | $20,000 | $18,000 | -$2,000 | Comprado ✓
Batería Li-Ion 14500 | 1 | $18,000 | $20,000 | +$2,000 | Comprado ✓
TP4056 USB-C | 1 | $3,500 | $3,500 | $0 | Comprado ✓
Slide Switch | 1 | $1,000 | $800 | -$200 | Comprado ✓
Holder 14500 | 1 | $2,500 | $2,500 | $0 | Comprado ✓
Pulsador 6×6 mm | 1 | $500 | $500 | $0 | Comprado ✓
LED RGB 5 mm | 1 | $1,000 | $1,000 | $0 | Comprado ✓
Resistencias (220, 10k) | 3 | $200 | $200 | $0 | Comprado ✓
PCB Baquelita | 1 | $5,000 | $6,000 | +$1,000 | Comprado ✓
Filamento PETG 20 g | 1 | $5,000 | $5,000 | $0 | Comprado ✓
O-Rings + Insumos | 1 | $10,000 | $12,000 | +$2,000 | Comprado ✓
Electrónica y Sensores | $188,000 | $184,500 | -$3,500 | —
Potencia y Energía | | $25,000 | $26,800 | +$1,800 | —
Mecánica e Insumos | | $21,700 | $24,000 | +$2,300 | —
TOTAL POR UNIDAD | $234,700 | $235,300 | +$600 | +0.26 % ✓

Cuadro 10: Auditoría Financiera: Presupuesto vs. Costo Real por Componente (Feb 2026).

Análisis de Varianza:
- Sobreejercicio (ESP32-C3, +$2,500): Cambio de proveedor local; precio de mercado actualizado en MercadoLibre Colombia.
- Sobreejercicio (Batería, +$2,000): Variación de precio en celda 14500 cilíndrica (proveedor local vs. estimado).
- Sobreejercicio (O-Rings/Insumos, +$2,000): Los O-Rings de compresión no estaban en BOM v1; fueron añadidos como acción correctiva AC-04 para eliminar holgura mecánica del Sled.
- Ahorro (BNO055, -$5,000): Proveedor alternativo validado (Solar Green / Didácticas Electrónicas).
- Resultado Neto: Variación total de +$600 COP sobre $234,700 estimados (+0.26 %). Dentro de la tolerancia del ±5 % definida en el DoD.

## 7. Roadmap Final — Semana 14 (Cierre del Proyecto)

Las siguientes tareas constituyen el backlog final para completar el ciclo de cierre del proyecto LANCEA. Las fechas se alinean con el cronograma Gantt del repositorio (Semana 16 como cierre definitivo).

Tareas de Cierre Técnico:

### 1. Pruebas de Campo Finales (Semana 14, Lunes–Miércoles)

- Ejecución de lanzamientos reales con atleta de la Liga de Atletismo del Quindío (pista al aire libre).
- Validación de captura de datos bajo condiciones reales: temperatura 15°C–35°C, humedad 60–95 %.
- Confirmación de no alteración del centro de gravedad ni de la parábola de vuelo.
- Descarga de CSV en pista desde 192.168.4.1 vía teléfono celular (sin cable, sin internet).

### 2. Congelación de Código Firmware (Semana 14, Jueves)

- Creación de Git Tag v1.0-final en rama main.
- Compilación limpia sin warnings en Arduino IDE / PlatformIO.
- Validación de binario final en hardware de competición (XIAO ESP32-C3 + BNO055).

### 3. Documentación Técnica Completa (Semana 14, Viernes)

- Cierre de Wiki del repositorio con protocolos de prueba y esquemáticos as-built.
- Manual de usuario LANCEA v2.0 (Guía Web ya disponible: LANCEA Guia Web.md).
- Matriz de cumplimiento final vs. requisitos RF-001/002/004/005/006/007 y RNF-003/005/012.
- Generación de documento de Lessons Learned (IPAC retrospectiva consolidada).

### 4. Entregables Finales

- Presentación cliente Sem. 14 (2026-05-04) y sustentación final Sem. 15 (2026-05-11).
- Prototipo físico funcional para entrega.
- Código fuente congelado + documentación completa en repositorio.
- Cierre definitivo Sem. 16 (2026-05-25).

Criterios de Aceptación de Cierre:

Criterio | Descripción | Estado Target
Pruebas de Campo | Lanzamiento real detectado, CSV íntegro generado en pista | PASS
Firmware Congelado | v1.0-final tagged, compilación sin warnings | PASS
Documentación | Wiki completa, manual PDF, datasheets consolidados | COMPLETO
Cumplimiento Presupuesto | CVU final ≤ $250,000 COP (incluye imprevistos) | CUMPLIDO
Cronograma | Todas las tareas Sem. 14–16 completadas | ON-TRACK
Validación Usuario | Aprobación entrenador + atleta Liga del Quindío | CONFIRMADA

Cuadro 11: Criterios de Aceptación de Cierre de Proyecto (IPAC-04 Final).

## 8. Retroalimentación del Cliente y Validación en Campo

Las pruebas finales se ejecutaron en pista de atletismo al aire libre con participación directa del entrenador y un atleta de la Liga de Atletismo del Quindío. El atleta realizó múltiples secuencias completas de lanzamiento (carrera de aproximación, cruce y liberación) a máxima intensidad con el dispositivo LANCEA integrado.

Testimonios del Usuario Final:
- Atleta: “El dispositivo es prácticamente imperceptible. No tuve que modificar mi agarre ni sentí que el peso afectara la trayectoria. El sonido de confirmación (Buzzer) me ayudó a saber exactamente cuándo estaba listo para lanzar, sin interrumpir mi concentración.”
- Entrenador: “Por fin tenemos datos objetivos e inmediatos. Poder descargar el CSV en la misma pista sin depender de cables o de una red Wi-Fi externa es un cambio total en la dinámica de entrenamiento. Los ángulos registrados coinciden con las correcciones biomecánicas que necesitamos hacer.”

Validación Técnica en Campo:
- Integridad física: PCB (19.8 mm) y encapsulado soportaron fuerzas G y vibraciones del impacto contra el suelo sin daños estructurales.
- Estabilidad dinámica: Peso (≈42 g) y ubicación del dispositivo no alteraron el centro de gravedad ni la parábola de vuelo.
- Transmisión inalámbrica: CSV preciso generado en tiempo real desde ESP32 AP, validando la arquitectura offline-first.

Joseph Fernando Gutiérrez Líder de Proyecto / Firmware Ingeniería Electrónica — U. Quindío

Emerson Santiago Córdoba
Hardware / PCB
Ingeniería Electrónica — U. Quindío

Johan Rodrigo Piedrahita
Mecánica / Pruebas de Campo Ingeniería Electrónica — U. Quindío

Informe generado bajo los estándares de escritura técnica del curso CDIO III — Universidad del Quindío, Armenia, Colombia.
Versión del documento: 1.0 — Ciclo: IPAC-04 — Revisado por: Prof. Jorge Luis Chávez

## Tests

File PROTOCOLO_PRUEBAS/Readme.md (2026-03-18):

# 🧪 Protocolos de Prueba y Validación (Test Reports)

Este directorio contiene los reportes oficiales de pruebas ejecutadas para el proyecto **LANCEA**. Todas las validaciones siguen los estándares de calidad industrial exigidos en el curso, eliminando la subjetividad y basando los resultados en **datos medibles y tolerancias exactas**.

> 📊 **Documento Oficial:** [Dar click para observar el protocolo de pruebas)](https://docs.google.com/spreadsheets/d/1hmodUZB4RpgECLQpkgpnOsaG3j49326qS3rEEbqlpOA/edit?usp=sharing) 

---

## 📌 Resumen Ejecutivo de Pruebas (Fase Actual)

A continuación, se presenta el estado de los últimos test de integración (Hardware, Firmware y Mecánica) correspondientes a la etapa de prototipado inicial:

| ID Prueba | Subsistema | Objetivo Principal | Resultado Medido | Estado |
| :--- | :--- | :--- | :--- | :---: |
| **TEST-HW-01** | PCB (KiCad) | Validar tolerancia dimensional para encaje tubular. | Ancho virtual de baquelita: **19.8mm** (Tolerancia: < 20mm). | ✅ **PASS** |
| **TEST-FW-01** | IMU (MPU6050) | Validar algoritmo de inclinación estática a 45°. | Lectura Serial estable entre **44.5° y 45.1°**. | ✅ **PASS** |
| **TEST-HW-02** | Energía (14500) | Medir autonomía real del sistema en operación. | Tiempo de operación continua: **7 horas y 15 minutos**. | ✅ **PASS** |
| **TEST-MC-01** | Jabalina | Inspección del diámetro interno del tubo deportivo. | Diámetro útil medido con calibrador: **25.2mm**. | ✅ **PASS** |

---

## ⚙️ Metodología de Validación (Definition of Done)

Para que una prueba sea marcada como `✅ PASS` y el componente pase a la columna "Done" en nuestro tablero, debe cumplir estrictamente con los siguientes pilares:

1. **Cero Subjetividad:** No se aceptan descripciones como *"funcionó bien"* o *"la batería duró harto"*. Se exigen valores numéricos (Voltios, Milímetros, Grados, Milisegundos).
2. **Setup Documentado:** Cada prueba en el Excel detalla los instrumentos utilizados (Multímetro Fluke, Calibrador Pie de Rey, Monitor Serial, etc.).
3. **Criterios de Aceptación Predefinidos:** El "Resultado Esperado" se define antes de energizar el circuito, basándose en la hoja de datos (Datasheet) o las restricciones mecánicas.

---
*Documento mantenido por: Joseph Gutierrez - Ingeniería Electrónica*

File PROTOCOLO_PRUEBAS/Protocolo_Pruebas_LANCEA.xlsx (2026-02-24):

ID de Prueba | Componente | Prioridad | Descripción / Resumen | Setup y Pre-requisitos | Pasos de Ejecución | Parámetros (Input) | Resultado Esperado | Resultado Obtenido | Estado Final | Ingeniero a Cargo
TEST-HW-01 | PCB Diseño (KiCad) | P1 (Alto) | Validar dimensiones de la PCB para asegurar encaje aerodinámico. | Software KiCad 7.0, Diseño 3D del chasis (Sled). | 1. Trazar bordes de corte (Edge.Cuts). 2. Medir ancho máximo en KiCad. 3. Comparar con diámetro interno del Sled (24mm). | Ancho máx PCB objetivo: <= 20mm | La placa virtual debe medir máximo 20mm de ancho para tener tolerancia. | Medición en KiCad indica 19.8mm de ancho exacto. | ✅ PASS | Joseph Gutierrez
TEST-FW-01 | Módulo IMU (MPU6050) | P0 (Crítico) | Validar lectura de ángulo de inclinación (Pitch/Roll) en estático. | ESP32, MPU6050, Protoboard, Monitor Serial a 115200 baudios, Escuadra física. | 1. Flashear firmware de prueba I2C. 2. Posicionar sensor a 0° plano. 3. Inclinar sensor a 45° apoyado en la escuadra. | Baudrate: 115200 Ángulo físico real: 45° | El monitor serial debe imprimir 45° con un error máximo de ±2°. | Lectura estable obtenida: 44.5° a 45.1° (Dentro del margen). | ✅ PASS | Joseph Gutierrez
TEST-HW-02 | Sistema de Potencia | P0 (Crítico) | Validar tiempo de operación continua (Autonomía) con baterías 14500. | Batería Li-Ion 14500 (1000mAh) cargada al 100%, ESP32 en modo activo continuo, Cronómetro. | 1. Conectar batería al circuito. 2. Registrar hora de inicio. 3. Monitorear hasta que el BMS corte por bajo voltaje (V_min). | Consumo estimado: ~120mA V_corte: 3.0V | El sistema debe mantenerse encendido operando por más de 6 horas. | El sistema operó continuamente por 7 horas y 15 minutos. | ✅ PASS | Joseph Gutierrez
TEST-MC-01 | Jabalina de Entrenamiento | P1 (Alto) | Inspección dimensional del material de prueba (Jabalina Profesional). | Jabalina de entrenamiento profesional, Calibrador (Pie de Rey). | 1. Desatornillar/revisar punto de inserción de la jabalina. 2. Medir diámetro interno disponible para el chasis. | Tubo de fibra/metal estándar. | Diámetro interno debe ser > 24mm para aceptar el Sled impreso en 3D. | Diámetro interno medido: 25.2mm. Suficiente holgura para el chasis. | ✅ PASS | Joseph Gutierrez

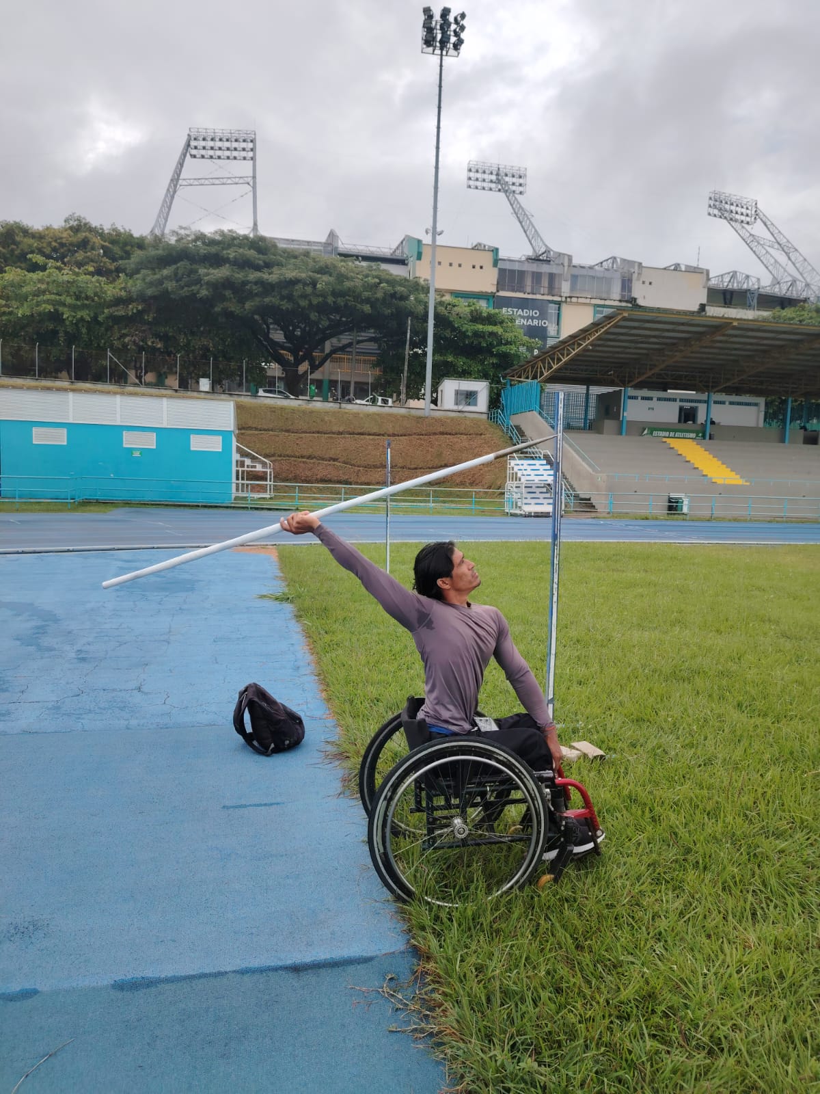
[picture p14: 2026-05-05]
0_1 Gestion/RETROALIMENTACION_FINAL/PRUEBA_CAMPO_REAL_2.jpeg

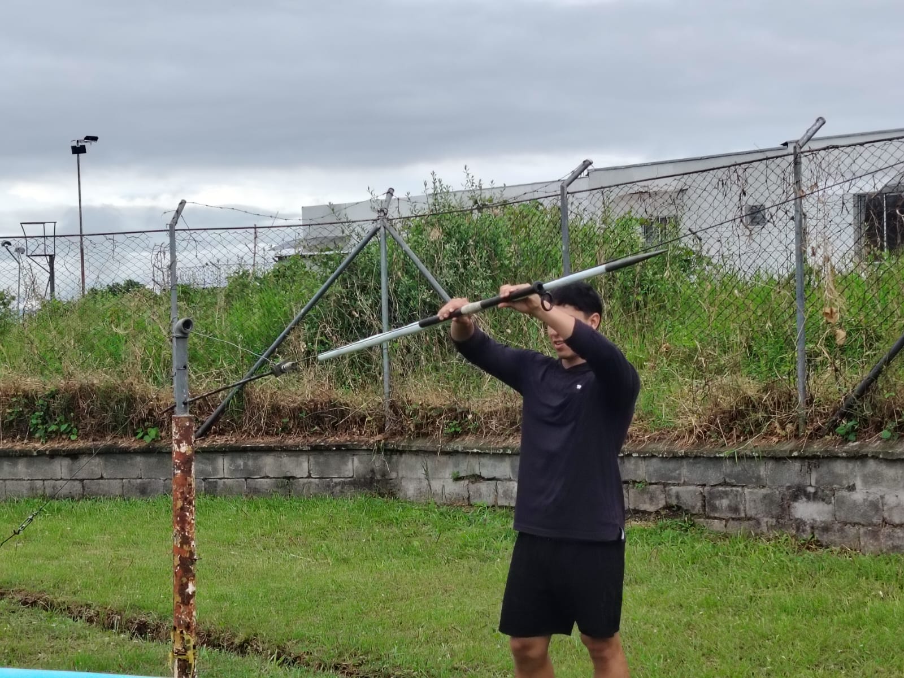
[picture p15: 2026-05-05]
0_1 Gestion/RETROALIMENTACION_FINAL/PRUEBA_CAMPO_REAL.jpeg

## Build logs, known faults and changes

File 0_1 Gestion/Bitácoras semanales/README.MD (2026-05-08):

## 📓 Bitácoras de Reunión — Proyecto LANCEA

Para garantizar un trabajo en equipo organizado y responsable, se realizaron bitácoras semanales donde se documenta el avance del proyecto.  
Haz clic en cada enlace para ver el detalle de cada sesión:

---

### 📊 Registro de Bitácoras

| # | Bitácora | Acceso |
|---|---|---|
| 1 | Bitácora #1 | [Ver documento](https://docs.google.com/document/d/1FN9ME7lDbvVwV-r9ogzSU9IxB-_Icy7cQMnI7wVtj9c/edit?usp=sharing) |
| 2 | Bitácora #2 | [Ver documento](https://docs.google.com/document/d/1ysZ0t2bSloNOOEKUynv4L6YnJTHetXg92PrnFCW4vLE/edit?usp=sharing) |
| 3 | Bitácora #3 | [Ver documento](https://docs.google.com/document/d/1l0ygotyNH1ssBBc3NoKCAPtdK-Wu8ImMKZGnguDcnzk/edit?usp=drive_link) |
| 4 | Bitácora #4 | [Ver documento](https://docs.google.com/document/d/1z-8Tub0L978sYI5P-ZMCt19ygRT-D_f8gAzopPH1WfM/edit?usp=drive_link) |
| 5 | Bitácora #5 | [Ver documento](https://docs.google.com/document/d/1MwEz4FWgYRkeulKCuyCjE_IiMj47Ce50jCFIk6o0Dug/edit?usp=drive_link) |
| 6 | Bitácora #6 | [Ver documento](https://docs.google.com/document/d/1wrB0hjqpGycNuCaMwN87FoNTk_IZF-ZxJ_kzd30bsgg/edit?usp=drive_link) |
| 7 | Bitácora #7 | [Ver documento](https://docs.google.com/document/d/1h1ZrDeNrWQ-2al60Yf1U3WhJTr78SWlTcwMSer0_N5I/edit?usp=drive_link) |
| 8 | Bitácora #8 | [Ver documento](https://docs.google.com/document/d/1xYIWbzgenVLDkXeh9KLXPRibkP6rmeT5pnkYMEUR7Gk/edit?usp=drive_link) |
| 9 | Bitácora #9 | [Ver documento](https://docs.google.com/document/d/1_Dr-zux6Pcx-LnQ-MLhBI1gncId8e9dlhO6NIZurQdY/edit?usp=drive_link) |
| 10 | Bitácora #10 | [Ver documento](https://docs.google.com/document/d/1GkYeA2pI62UvVJICCQ5gGQ7zZpN7b7SY-defAIAloMg/edit?usp=drive_link) |
| 11 | Bitácora #11 | [Ver documento](https://docs.google.com/document/d/1O_bVQ67BpS_MziINS0ng6xdSbM-qweT3dsXgktgsXfA/edit?usp=drive_link) |
| 12 | Bitácora #12 | [Ver documento](https://docs.google.com/document/d/18fROQ_5y_AkvWl3t85IYqPVxsczhZKMRs7h5lcvl7nc/edit?usp=drive_link) |
| 13 | Bitácora #13 | [Ver documento](https://docs.google.com/document/d/1SV9VKoWgo9cBicWQWKIHf0HUeQpAyeOdmfuNbkDm9SI/edit?usp=sharing) |
| 14 | Bitácora #14 | [Ver documento](https://docs.google.com/document/d/1RtbjOUo2yBLLyvCr5yDrMufrhcshJpU7QpBLzLa3f70/edit?usp=sharing) |
| 15 | Bitácora #15 | [Ver documento](https://docs.google.com/document/d/1G6utLq2Wf2w2TfL3KHC8yaZuyGiwOIoT4YJCPDW11Ng/edit?usp=sharing) |

---

### 🧠 Nota
Estas bitácoras permiten evidenciar la trazabilidad del proyecto, la toma de decisiones y el avance progresivo del sistema **LANCEA**, desde su fase conceptual hasta la integración final.

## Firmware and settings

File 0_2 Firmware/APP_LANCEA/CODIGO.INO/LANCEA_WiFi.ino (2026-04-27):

// ================================================================
//  LANCEA_WiFi.ino  —  XIAO ESP32-C3  v7.1
//
//  BUZZER:
//  · Pin 21, pasivo, tone()/noTone()
//  · Monitorea angulo en IDLE cada 100ms
//  · Suena a 2700Hz cuando angulo esta entre 42° y 45.8°
//  · Se apaga al detectar impulso
//
//  BATERIA:
//  · Pin A0, divisor resistivo 1/2 con 220k
//  · Lee con analogReadMilliVolts() x16 muestras
//  · Voltaje real = 2 * promedio_mV / 1000
//  · Porcentaje basado en curva Li-Ion 3.0V=0% 4.2V=100%
//  · Se publica en serial, /status JSON y pagina web
//
//  PAGINAS WEB:
//    192.168.4.1/          → panel principal
//    192.168.4.1/atletas   → gestionar atletas
//    192.168.4.1/csv       → CSV del atleta activo
//    192.168.4.1/csv?a=Todos → CSV de todos
//    192.168.4.1/status    → JSON estado + bateria
//    192.168.4.1/reset     → borra lanzamientos del atleta activo
//    192.168.4.1/resetall  → borra todo
// ================================================================

#include <Wire.h>
#include <Adafruit_Sensor.h>
#include <Adafruit_BNO055.h>
#include <utility/imumaths.h>
#include <WiFi.h>
#include <WebServer.h>

// ================================================================
//  CONFIGURACION WiFi
// ================================================================
const char*     AP_SSID = "LANCEA_AP";
const char*     AP_PASS = "lancea123";
const IPAddress AP_IP(192, 168, 4, 1);

// ================================================================
//  PINES  XIAO ESP32-C3
// ================================================================
#define I2C_SDA    6
#define I2C_SCL    7
#define LED_PIN   10
#define BUZZER_PIN 21
#define BAT_PIN    A0

// ================================================================
//  PARAMETROS FISICOS
// ================================================================
const double g            = 9.81;
const double JAVELIN_MASS = 0.8;

// ================================================================
//  PARAMETROS DEL ALGORITMO
// ================================================================
const double ALPHA              = 0.30;
const double JERK_THRESHOLD     = 50.0;
const double FREEFALL_THRESHOLD = 0.8;
const double ARMING_ACCEL       = 15.0;
const unsigned long TIMEOUT_MS  = 2000;
const unsigned long PAUSE_MS    = 3000;

// ================================================================
//  TIMING
// ================================================================
Adafruit_BNO055     bno          = Adafruit_BNO055(55, 0x28);
const unsigned long INTERVALO_US = 10000UL;
const double        DT           = 0.01;
unsigned long       lastTime_us  = 0;

// ================================================================
//  MAQUINA DE ESTADOS
// ================================================================
enum Estado { IDLE, IMPULSO, PAUSA };
Estado        estadoActual = IDLE;
unsigned long tEstado      = 0;

// ================================================================
//  LED NO BLOQUEANTE
// ================================================================
struct LedFSM {
  int total=0, done=0, ms=120;
  bool on=false, running=false;
  unsigned long tLed=0;

  void blink(int n, int interval=120) {
    total=n*2; done=0; on=false; ms=interval;
    running=true; tLed=millis();
    digitalWrite(LED_PIN, HIGH);
  }
  void update() {
    if (!running) return;
    if (millis()-tLed < (unsigned long)ms) return;
    tLed=millis(); on=!on;
    digitalWrite(LED_PIN, on ? LOW : HIGH);
    if (++done >= total) { running=false; digitalWrite(LED_PIN, HIGH); }
  }
} led;

// ================================================================
//  SISTEMA DE ATLETAS
// ================================================================
#define MAX_ATLETAS  10
#define MAX_NAME_LEN 24

struct Atleta {
  char   nombre[MAX_NAME_LEN];
  bool   activo;
};

Atleta atletas[MAX_ATLETAS];
int    numAtletas    = 0;
int    atletaActivo  = -1;

int agregarAtleta(const String& nombre) {
  String n = nombre; n.trim();
  if (n.length() == 0 || n.length() >= MAX_NAME_LEN) return -1;
  for (int i=0; i<numAtletas; i++)
    if (String(atletas[i].nombre) == n) return i;
  if (numAtletas >= MAX_ATLETAS) return -1;
  n.toCharArray(atletas[numAtletas].nombre, MAX_NAME_LEN);
  atletas[numAtletas].activo = false;
  return numAtletas++;
}

void seleccionarAtleta(int idx) {
  if (idx < 0 || idx >= numAtletas) return;
  atletaActivo = idx;
}

String nombreActivo() {
  if (atletaActivo < 0 || atletaActivo >= numAtletas)
    return "Sin atleta";
  return String(atletas[atletaActivo].nombre);
}

// ================================================================
//  HISTORIAL RAM
// ================================================================
#define MAX_THROWS 100

struct ThrowRecord {
  uint8_t num;
  float   velFinal, maxAccel, angle, impulseTime, distance, energy, power;
  int8_t  atletaIdx;
};

ThrowRecord throwLog[MAX_THROWS];
int         throwLogCount = 0;
int         throwCount    = 0;

// ================================================================
//  SERVIDOR WEB
// ================================================================
WebServer server(80);

// ================================================================
//  VARIABLES DE VUELO
// ================================================================
double        v_x=0, v_y=0, v_z=0;
double        ax_f=0, ay_f=0, az_f=0;
double        prev_aMag=0, maxAccel=0, launchAngle=0;
unsigned long startImpulse=0;

// ================================================================
//  BUZZER DE ANGULO OPTIMO (pre-lanzamiento)
// ================================================================
const float          ANGLE_OPT_LOW      = 42.0f;
const float          ANGLE_OPT_HIGH     = 45.8f;
const int            BUZZER_FREQ        = 2700;
const unsigned long  BUZZER_INTERVAL_MS = 100;

bool          buzzerActive    = false;
unsigned long lastBuzzerCheck = 0;

void updateAngleBuzzer() {
  if (millis() - lastBuzzerCheck < BUZZER_INTERVAL_MS) return;
  lastBuzzerCheck = millis();

  if (estadoActual != IDLE) {
    if (buzzerActive) {
      noTone(BUZZER_PIN);
      buzzerActive = false;
      safePrintln("[BUZZER] OFF — fuera de IDLE");
    }
    return;
  }

  imu::Quaternion  quat  = bno.getQuat();
  imu::Vector<3>   euler = quat.toEuler();
  float currentAngle = euler.y() * 180.0f / PI;

  if (currentAngle >= ANGLE_OPT_LOW && currentAngle <= ANGLE_OPT_HIGH) {
    if (!buzzerActive) {
      tone(BUZZER_PIN, BUZZER_FREQ);
      buzzerActive = true;
      safePrintln("[BUZZER] ON  — angulo: " + String(currentAngle, 1) + " deg (42-45.8)");
    }
  } else {
    if (buzzerActive) {
      noTone(BUZZER_PIN);
      buzzerActive = false;
      safePrintln("[BUZZER] OFF — angulo: " + String(currentAngle, 1) + " deg");
    }
  }
}

// ================================================================
//  MONITOREO DE BATERIA
// ================================================================
#define BAT_SAMPLES        16
#define BAT_INTERVAL_MS    15000   // leer cada 15 segundos

float         batVoltage   = 0.0f;
int           batPercent   = 0;
unsigned long lastBatCheck = 0;

// Genera el color HTML segun nivel de bateria
String batColor() {
  if (batPercent > 50) return "#00FF88";
  if (batPercent > 20) return "#F0A500";
  return "#FF3B5C";
}

// Genera barra de texto unicode (10 bloques)
String batBar() {
  String bar = "";
  int filled = batPercent / 10;
  for (int i = 0; i < 10; i++)
    bar += (i < filled) ? "&#9608;" : "&#9617;";
  return bar;
}

void updateBattery() {
  if (millis() - lastBatCheck < BAT_INTERVAL_MS) return;
  lastBatCheck = millis();

  uint32_t Vbatt = 0;
  for (int i = 0; i < BAT_SAMPLES; i++)
    Vbatt += analogReadMilliVolts(BAT_PIN);

  // divisor 1/2  →  voltaje real = 2 * promedio_mV / 1000
  batVoltage = 2.0f * Vbatt / BAT_SAMPLES / 1000.0f;

  // Curva Li-Ion: 4.2V = 100%  |  3.0V = 0%
  batPercent = constrain(
    (int)((batVoltage - 3.0f) / (4.2f - 3.0f) * 100.0f), 0, 100);

  safePrint("[BAT] ");
  safePrint(String(batVoltage, 3));
  safePrint(" V  →  ");
  safePrint(String(batPercent));
  safePrintln("%");
}

// ================================================================
//  SERIAL SEGURO
// ================================================================
void safePrint(const String& s) {
  if (Serial && Serial.availableForWrite()>10) Serial.print(s);
}
void safePrintln(const String& s) {
  if (Serial && Serial.availableForWrite()>10) Serial.println(s);
}

// ================================================================
//  PROTOTIPOS
// ================================================================
void   initWiFi();
void   registerRoutes();
void   handleRoot();
void   handleAtletas();
void   handleSetAtleta();
void   handleAddAtleta();
void   handleDelAtleta();
void   handleCSV();
void   handleStatus();
void   handleResetAtleta();
void   handleResetAll();
void   handleCommands();
void   handleDump();
void   handleReset();
void   publishThrow(double v,double a,double t,double d,double e,double p);
void   resetVariables();
String buildCSV(int filterAtleta);
String htmlHeader(const String& title);
String htmlFooter();

// ================================================================
//  SETUP
// ================================================================
void setup() {
  Serial.begin(115200);
  pinMode(LED_PIN, OUTPUT);
  digitalWrite(LED_PIN, HIGH);
  pinMode(BUZZER_PIN, OUTPUT);
  noTone(BUZZER_PIN);
  pinMode(BAT_PIN, INPUT);

  delay(3000);
  Wire.begin(I2C_SDA, I2C_SCL);

  safePrintln("================================================");
  safePrintln("  LANCEA  WiFi  v7.1  —  XIAO ESP32-C3");
  safePrintln("================================================");

  agregarAtleta("Invitado");
  seleccionarAtleta(0);

  if (!bno.begin()) {
    safePrintln("[ERROR] BNO055 no detectado.");
    while(1) delay(1000);
  }
  bno.setExtCrystalUse(true);
  safePrintln("[OK]   BNO055 listo.");

  // Lectura inicial de bateria
  updateBattery();
  lastBatCheck = 0;   // forzar otra lectura en el primer ciclo real
  updateBattery();

  initWiFi();
  registerRoutes();
  server.begin();

  safePrintln("[WEB]  http://192.168.4.1");
  safePrintln("[WEB]  http://192.168.4.1/atletas");
  safePrintln("[BUZZER] Pin " + String(BUZZER_PIN) +
              " | Angulo optimo: " + String(ANGLE_OPT_LOW,0) +
              "-" + String(ANGLE_OPT_HIGH,1) + " deg");
  safePrintln("[BAT]  Pin A0 | " + String(batVoltage,3) +
              " V | " + String(batPercent) + "%");
  safePrintln(">>> Listo. Atleta: " + nombreActivo());
  safePrintln("------------------------------------------------");

  led.blink(3, 200);
}

void initWiFi() {
  WiFi.mode(WIFI_AP);
  WiFi.softAPConfig(AP_IP, AP_IP, IPAddress(255,255,255,0));
  WiFi.softAP(AP_SSID, AP_PASS);
  safePrintln("[WiFi] SSID: " + String(AP_SSID));
  safePrintln("[WiFi] IP  : " + WiFi.softAPIP().toString());
}

void registerRoutes() {
  server.on("/",            HTTP_GET,  handleRoot);
  server.on("/atletas",     HTTP_GET,  handleAtletas);
  server.on("/set_atleta",  HTTP_GET,  handleSetAtleta);
  server.on("/add_atleta",  HTTP_POST, handleAddAtleta);
  server.on("/del_atleta",  HTTP_GET,  handleDelAtleta);
  server.on("/csv",         HTTP_GET,  handleCSV);
  server.on("/status",      HTTP_GET,  handleStatus);
  server.on("/reset",       HTTP_GET,  handleResetAtleta);
  server.on("/resetall",    HTTP_GET,  handleResetAll);
  server.onNotFound([](){
    server.sendHeader("Location","/");
    server.send(302,"text/plain","");
  });
}

// ================================================================
//  LOOP PRINCIPAL — 100% no bloqueante
// ================================================================
void loop() {
  server.handleClient();
  handleCommands();
  led.update();
  updateAngleBuzzer();
  updateBattery();

  switch (estadoActual) {
    case IDLE: {
      static unsigned long tB=0; static bool bS=false;
      if (!led.running && millis()-tB>=1200) {
        tB=millis(); bS=!bS;
        digitalWrite(LED_PIN, bS ? LOW : HIGH);
      }
      break;
    }
    case PAUSA:
      if (millis()-tEstado >= PAUSE_MS) {
        resetVariables();
        estadoActual = IDLE;
      }
      break;
    default: break;
  }

  unsigned long now_us = micros();
  if (now_us - lastTime_us < INTERVALO_US) return;
  lastTime_us = now_us;

  if (estadoActual == PAUSA) return;

  sensors_event_t ev;
  bno.getEvent(&ev, Adafruit_BNO055::VECTOR_LINEARACCEL);
  double ax=ev.acceleration.x, ay=ev.acceleration.y, az=ev.acceleration.z;

  ax_f = ALPHA*ax + (1.0-ALPHA)*ax_f;
  ay_f = ALPHA*ay + (1.0-ALPHA)*ay_f;
  az_f = ALPHA*az + (1.0-ALPHA)*az_f;

  double aMag = sqrt(ax_f*ax_f + ay_f*ay_f + az_f*az_f);
  double jerk = (aMag - prev_aMag) / DT;
  prev_aMag = aMag;

  if (estadoActual==IDLE && jerk>JERK_THRESHOLD) {
    if (buzzerActive) {
      noTone(BUZZER_PIN);
      buzzerActive = false;
    }
    estadoActual = IMPULSO;
    startImpulse = millis();
    digitalWrite(LED_PIN, LOW);

    imu::Quaternion quat = bno.getQuat();
    imu::Vector<3>  euler = quat.toEuler();
    launchAngle = euler.y() * 180.0 / PI;

    safePrintln("IMPULSO_START");
    safePrintln("Atleta: " + nombreActivo());
  }

  if (estadoActual==IMPULSO) {
    v_x += ax_f*DT; v_y += ay_f*DT; v_z += az_f*DT;
    if (aMag > maxAccel) maxAccel = aMag;

    if (aMag < FREEFALL_THRESHOLD && maxAccel > ARMING_ACCEL) {
      double impulseTime = (millis()-startImpulse)/1000.0;
      double velFinal    = sqrt(v_x*v_x + v_y*v_y + v_z*v_z);
      double angleRad    = launchAngle * PI / 180.0;
      double distance    = (velFinal*velFinal*sin(2.0*angleRad)) / g;
      double energy      = 0.5 * JAVELIN_MASS * velFinal * velFinal;
      double power       = (impulseTime>0) ? energy/impulseTime : 0.0;

      throwCount++;

      if (throwLogCount < MAX_THROWS) {
        throwLog[throwLogCount++] = {
          (uint8_t)throwCount,
          (float)velFinal, (float)maxAccel, (float)launchAngle,
          (float)impulseTime, (float)distance,
          (float)energy, (float)power,
          (int8_t)atletaActivo
        };
      }

      publishThrow(velFinal, launchAngle, impulseTime, distance, energy, power);
      led.blink(3);
      estadoActual = PAUSA;
      tEstado = millis();
      return;
    }

    if ((millis()-startImpulse) > TIMEOUT_MS) {
      safePrintln("[!] Timeout.");
      resetVariables();
      estadoActual = IDLE;
    }
  }
}

// ================================================================
//  HELPERS HTML
// ================================================================
String htmlHeader(const String& title) {
  String h = "<!DOCTYPE html><html lang='es'><head><meta charset='UTF-8'>";
  h += "<meta name='viewport' content='width=device-width,initial-scale=1'>";
  h += "<title>LANCEA - " + title + "</title><style>";
  h += "body{background:#03060A;color:#E8F4FD;font-family:monospace;margin:0;padding:14px}";
  h += "h1{color:#00C8FF;font-size:1.3em;margin-bottom:2px}";
  h += "h2{color:#6B8BA4;font-size:1em;margin:16px 0 8px}";
  h += ".sub{color:#334B62;font-size:.8em;margin-bottom:12px}";
  h += ".badge{display:inline-block;background:#0F1C2E;border:1px solid #1A3050;";
  h += "border-radius:6px;padding:6px 14px;margin:3px;text-align:center}";
  h += ".badge span{display:block;font-size:1.5em;font-weight:bold}";
  h += ".v{color:#00C8FF}.a{color:#F0A500}.d{color:#00FF88}.e{color:#A855F7}.p{color:#EC4899}";
  // Barra de bateria en header
  h += ".bat-bar{display:inline-block;background:#0F1C2E;border:1px solid #1A3050;";
  h += "border-radius:6px;padding:5px 12px;margin:3px;font-size:.85em;vertical-align:middle}";
  h += "table{width:100%;border-collapse:collapse;font-size:.82em;margin-top:8px}";
  h += "th{background:#0B1520;color:#6B8BA4;padding:7px 5px;text-align:center;border-bottom:1px solid #1A3050}";
  h += "td{padding:6px 5px;text-align:center;border-bottom:1px solid #0B1520}";
  h += "tr:hover td{background:#0B1520}";
  h += ".btn{display:inline-block;margin:6px 3px;padding:8px 18px;background:#00C8FF;";
  h += "color:#000;border-radius:6px;font-family:monospace;font-weight:bold;text-decoration:none;border:none;cursor:pointer}";
  h += ".btn-green{background:#00FF88;color:#000}";
  h += ".btn-red{background:#FF3B5C;color:#fff}";
  h += ".btn-gray{background:#0F1C2E;color:#E8F4FD;border:1px solid #1A3050}";
  h += ".btn-active{background:#F0A500;color:#000}";
  h += ".ok{color:#00FF88}.warn{color:#F0A500}.bad{color:#FF3B5C}";
  h += "input[type=text]{background:#0F1C2E;color:#E8F4FD;border:1px solid #1A3050;";
  h += "border-radius:6px;padding:8px 12px;font-family:monospace;font-size:1em;width:200px}";
  h += ".nav{margin-bottom:16px;display:flex;align-items:center;gap:0}";
  h += ".nav a{color:#6B8BA4;text-decoration:none;margin-right:16px;font-size:.85em}";
  h += ".nav a:hover{color:#00C8FF}";
  h += ".nav-bat{margin-left:auto}";
  h += ".atleta-activo{color:#00C8FF;font-weight:bold}";
  h += "</style></head><body>";

  // Barra de navegacion con bateria integrada en la esquina derecha
  h += "<div class='nav'>";
  h += "<a href='/'>Panel</a><a href='/atletas'>Atletas</a>";
  h += "<span class='nav-bat bat-bar'>";
  h += "<span style='color:" + batColor() + "'>&#9889; ";
  h += batBar();
  h += " " + String(batPercent) + "% (" + String(batVoltage, 2) + "V)";
  h += "</span></span>";
  h += "</div>";

  return h;
}

String htmlFooter() {
  String f = "<br><div style='color:#334B62;font-size:.75em;margin-top:20px'>";
  f += "LANCEA v7.1 | RAM: " + String(MAX_THROWS-throwLogCount) + " slots libres";
  f += " | Atleta: <span class='atleta-activo'>" + nombreActivo() + "</span>";
  f += " | <span style='color:" + batColor() + "'>&#9889; Bat: ";
  f += batBar() + " " + String(batPercent) + "% (" + String(batVoltage,2) + "V)</span>";
  f += "</div></body></html>";
  return f;
}

// ================================================================
//  PAGINA PRINCIPAL  /
// ================================================================
void handleRoot() {
  server.setContentLength(CONTENT_LENGTH_UNKNOWN);
  server.send(200, "text/html; charset=utf-8", "");
  server.sendContent(htmlHeader("Panel"));

  String s = "<h1>&#9651; LANCEA</h1>";
  s += "<div class='sub'>";
  s += estadoActual==IMPULSO ? "&#128308; INTEGRANDO" :
       estadoActual==PAUSA   ? "&#128992; PAUSA" :
                               "&#128994; EN ESPERA";
  s += " &nbsp;|&nbsp; Atleta: <span class='atleta-activo'>" + nombreActivo() + "</span>";

  int cuentaActivo = 0;
  for (int i=0;i<throwLogCount;i++)
    if (throwLog[i].atletaIdx == atletaActivo) cuentaActivo++;
  s += " &nbsp;|&nbsp; " + String(cuentaActivo) + " lanzamiento(s)</div>";
  server.sendContent(s);

  // Badge de bateria destacado en el panel
  s  = "<div class='badge' style='border-color:" + batColor() + "'>";
  s += "<span style='color:" + batColor() + ";font-size:1.3em'>";
  s += "&#9889; " + String(batPercent) + "%</span>";
  s += batBar() + "<br><small style='color:#334B62'>" + String(batVoltage,3) + " V</small></div>";
  server.sendContent(s);

  // Badges de rendimiento del atleta activo
  float bestV=0,bestD=0,bestE=0,sumA=0; int cnt=0;
  for (int i=0;i<throwLogCount;i++) {
    if (throwLog[i].atletaIdx != atletaActivo) continue;
    if(throwLog[i].velFinal>bestV) bestV=throwLog[i].velFinal;
    if(throwLog[i].distance>bestD) bestD=throwLog[i].distance;
    if(throwLog[i].energy  >bestE) bestE=throwLog[i].energy;
    sumA+=throwLog[i].angle; cnt++;
  }
  if (cnt > 0) {
    float avgA=sumA/cnt;
    s  = "<div class='badge'><span class='v'>"+String(bestV,2)+"</span>Vel max m/s</div>";
    s += "<div class='badge'><span class='a'>"+String(avgA,1)+"</span>Ang prom</div>";
    s += "<div class='badge'><span class='d'>"+String(bestD,2)+"</span>Dist max m</div>";
    s += "<div class='badge'><span class='e'>"+String(bestE,2)+"</span>Energia max J</div>";
    server.sendContent(s);
  }

  // Tabla
  server.sendContent(
    "<table><tr><th>#</th><th>Vel(m/s)</th><th>Ang</th><th>Dist(m)</th>"
    "<th>Acel</th><th>t(s)</th><th>E(J)</th><th>P(W)</th><th>Ang?</th></tr>"
  );

  bool hayDatos = false;
  for (int i=0;i<throwLogCount;i++) {
    ThrowRecord& r=throwLog[i];
    if (r.atletaIdx != atletaActivo) continue;
    hayDatos = true;
    const char* ac="bad"; const char* al="Malo";
    if      (r.angle>=32&&r.angle<=39){ac="ok";  al="Optimo";}
    else if (r.angle>=28&&r.angle<32) {ac="warn";al="Bajo";}
    else if (r.angle>39 &&r.angle<=44){ac="warn";al="Alto";}
    s  = "<tr><td>"+String(r.num)+"</td>";
    s += "<td class='v'>"+String(r.velFinal,2)+"</td>";
    s += "<td class='a'>"+String(r.angle,1)+"</td>";
    s += "<td class='d'>"+String(r.distance,2)+"</td>";
    s += "<td>"+String(r.maxAccel,2)+"</td>";
    s += "<td>"+String(r.impulseTime,3)+"</td>";
    s += "<td class='e'>"+String(r.energy,2)+"</td>";
    s += "<td class='p'>"+String(r.power,2)+"</td>";
    s += "<td class='"; s+=ac; s+="'>"; s+=al; s+="</td></tr>";
    server.sendContent(s);
  }
  if (!hayDatos)
    server.sendContent("<tr><td colspan='9' style='color:#334B62;padding:16px'>Sin lanzamientos para este atleta</td></tr>");

  s  = "</table><br>";
  s += "<a class='btn' href='/csv'>&#8595; CSV " + nombreActivo() + "</a>";
  s += "<a class='btn btn-gray' href='/csv?a=Todos'>&#8595; CSV Todos</a>";
  s += "<a class='btn btn-red' href='/reset' onclick=\"return confirm('Borrar lanzamientos de " + nombreActivo() + "?')\">&#215; Reset atleta</a>";
  s += "<a class='btn btn-gray' href='/atletas'>&#9651; Gestionar atletas</a>";
  server.sendContent(s);
  server.sendContent(htmlFooter());
  server.sendContent("");
}
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

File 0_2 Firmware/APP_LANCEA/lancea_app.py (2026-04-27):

import customtkinter as ctk
import serial
import serial.tools.list_ports
import threading
import pandas as pd
import numpy as np
import os
import json
from datetime import datetime
from tkinter import filedialog, messagebox
from matplotlib.figure import Figure
from matplotlib.backends.backend_tkagg import FigureCanvasTkAgg
import matplotlib.pyplot as plt
import time
import math

ctk.set_appearance_mode("Dark")
ctk.set_default_color_theme("blue")

# ── PALETA DE COLORES ──────────────────────────────────────────────────────────
BG_DEEP   = "#03060A"
BG_BASE   = "#070D14"
BG_PANEL  = "#0B1520"
BG_CARD   = "#0F1C2E"
BG_HOVER  = "#132540"
ACCENT1   = "#00C8FF"
ACCENT2   = "#F0A500"
ACCENT3   = "#00FF88"
RED_ALERT = "#FF3B5C"
TEXT_PRI  = "#E8F4FD"
TEXT_SEC  = "#6B8BA4"
TEXT_DIM  = "#334B62"
BORDER    = "#1A3050"

# ── DIRECTORIO RAÍZ ───────────────────────────────────────────────────────────
ROOT_DIR    = "LANCEA_DATA"
ATHLETES    = os.path.join(ROOT_DIR, "atletas")
SD_IMPORTS  = os.path.join(ROOT_DIR, "sd_imports")
CONFIG_FILE = os.path.join(ROOT_DIR, "config.json")


def ensure_dirs():
    os.makedirs(ROOT_DIR,   exist_ok=True)
    os.makedirs(ATHLETES,   exist_ok=True)
    os.makedirs(SD_IMPORTS, exist_ok=True)


def athlete_dir(name: str) -> str:
    safe = "".join(c for c in name if c.isalnum() or c in " _-").strip()
    path = os.path.join(ATHLETES, safe)
    os.makedirs(path, exist_ok=True)
    return path


def load_config() -> dict:
    ensure_dirs()
    if os.path.exists(CONFIG_FILE):
        try:
            with open(CONFIG_FILE, "r", encoding="utf-8") as f:
                return json.load(f)
        except Exception:
            pass
    return {"athletes": ["Invitado"], "last_athlete": "Invitado"}


def save_config(cfg: dict):
    ensure_dirs()
    with open(CONFIG_FILE, "w", encoding="utf-8") as f:
        json.dump(cfg, f, indent=2, ensure_ascii=False)


LANCEA_WIFI_IP = "192.168.4.1"


def get_session_dirs(athlete_name: str) -> dict:
    safe = "".join(c for c in athlete_name if c.isalnum() or c in " _-").strip()
    date_str = datetime.now().strftime("%Y-%m-%d")
    base = os.path.join(ROOT_DIR, "atletas", safe, date_str)
    dirs = {
        "raw":     os.path.join(base, "1_datos_crudos"),
        "plots":   os.path.join(base, "2_graficas"),
        "reports": os.path.join(base, "3_analisis"),
    }
    for p in dirs.values():
        os.makedirs(p, exist_ok=True)
    return dirs


def bat_color_hex(pct: int) -> str:
    """Devuelve color hex según nivel de batería."""
    if pct > 50: return ACCENT3
    if pct > 20: return ACCENT2
    return RED_ALERT


def bat_bar_str(pct: int) -> str:
    """Genera barra de texto (10 bloques) para batería."""
    filled = pct // 10
    return "█" * filled + "░" * (10 - filled)


def generar_reporte_automatico(csv_path: str, athlete_name: str) -> str:
    try:
        df = pd.read_csv(csv_path)
        if df.empty or len(df) < 1:
            return ""
        dirs = get_session_dirs(athlete_name)
        session_id = datetime.now().strftime("%H%M%S")

        resumen = df.describe().round(3)
        resumen.to_csv(os.path.join(dirs["reports"], "estadisticas_" + session_id + ".csv"))

        plt.style.use("dark_background")
        n = len(df)
        cols_num = [c for c in ["Velocidad","Angulo","Distancia","maxAccel","Energia","Potencia"]
                    if c in df.columns]
        if not cols_num:
            return ""
        n_plots = len(cols_num) + (1 if "Angulo" in df.columns and "Distancia" in df.columns else 0)
        rows_fig = max(1, (n_plots + 1) // 2)
        fig, axes = plt.subplots(rows_fig, 2, figsize=(12, 4 * rows_fig))
        axes_flat = axes.flatten() if hasattr(axes, "flatten") else [axes]
        fig.suptitle("Analisis de Sesion  -  " + athlete_name,
                     fontsize=14, color="#00C8FF", fontweight="bold")
        color_map = {"Velocidad":"#00C8FF","Angulo":"#F0A500","Distancia":"#00FF88",
                     "maxAccel":"#FF6B35","Energia":"#A855F7","Potencia":"#EC4899"}
        units = {"Velocidad":"m/s","Angulo":"deg","Distancia":"m",
                 "maxAccel":"m/s2","Energia":"J","Potencia":"W"}
        idx = 0
        for col in cols_num:
            if idx >= len(axes_flat): break
            ax = axes_flat[idx]; idx += 1
            color = color_map.get(col, "#FFFFFF")
            ax.plot(range(1, n+1), df[col], marker="o", color=color,
                    linewidth=2, markersize=6, alpha=0.9)
            ax.fill_between(range(1, n+1), df[col], alpha=0.15, color=color)
            if col == "Angulo":
                ax.axhspan(32, 39, alpha=0.12, color="#00FF88", label="zona optima")
                ax.legend(fontsize=8, labelcolor="#00FF88")
            ax.set_title(col + " por lanzamiento", color="#E8F4FD", fontsize=10)
            ax.set_xlabel("Lanzamiento", color="#6B8BA4", fontsize=8)
            ax.set_ylabel(units.get(col, ""), color="#6B8BA4", fontsize=8)
            ax.tick_params(colors="#6B8BA4", labelsize=8)
            ax.grid(True, alpha=0.2, color="#1A3050")
            for sp in ax.spines.values(): sp.set_edgecolor("#1A3050")
        if "Angulo" in df.columns and "Distancia" in df.columns and idx < len(axes_flat):
            ax = axes_flat[idx]; idx += 1
            sc = ax.scatter(df["Angulo"], df["Distancia"],
                            c=range(n), cmap="plasma", s=100, alpha=0.9)
            ax.axvspan(32, 39, alpha=0.1, color="#00FF88", label="angulo optimo")
            for i, (ang, dist) in enumerate(zip(df["Angulo"], df["Distancia"])):
                ax.annotate("#" + str(i+1), (ang, dist),
                            textcoords="offset points", xytext=(5,4),
                            fontsize=7, color="#6B8BA4")
            ax.set_title("Angulo vs Distancia", color="#E8F4FD", fontsize=10)
            ax.set_xlabel("Angulo (deg)", color="#6B8BA4", fontsize=8)
            ax.set_ylabel("Distancia (m)", color="#6B8BA4", fontsize=8)
            ax.tick_params(colors="#6B8BA4", labelsize=8)
            ax.grid(True, alpha=0.2, color="#1A3050")
            ax.legend(fontsize=8, labelcolor="#00FF88")
            for sp in ax.spines.values(): sp.set_edgecolor("#1A3050")
            plt.colorbar(sc, ax=ax, label="Orden")
        for j in range(idx, len(axes_flat)):
            axes_flat[j].set_visible(False)
        plt.tight_layout()
        plot_path = os.path.join(dirs["plots"], "grafica_" + session_id + ".png")
        plt.savefig(plot_path, dpi=150, bbox_inches="tight", facecolor="#070D14")
        plt.close()
        return plot_path
    except Exception as e:
        print("[ERROR reporte] " + str(e))
        return ""


# ── COMPONENTES VISUALES ───────────────────────────────────────────────────────

class GlowLabel(ctk.CTkLabel):
    pass
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

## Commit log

2026-02-16 Create LANCEA
    Sistema de Monitoreo Biomecánico para Jabalina.
2026-02-16 Add Gestion
    organización de los archivos de actas, boom y cronogramas
2026-02-17 Update README to remove image placeholder note
    Removed placeholder note for PCB/render image in README.
2026-02-17 Create BOM for LANCEA system
    Added detailed Bill of Materials (BOM) for LANCEA system including components, specifications, and estimated costs.
2026-02-17 Update Readme with current project status
2026-02-17 Add sensor_test.cpp file
2026-02-17 Remove unnecessary git commands from sensor_test.cpp
2026-02-17 Create sensor_test.cpp for sensor testing close #1
    Added a test script for sensor data validation.
2026-02-17 Update sensor_test.cpp fix #1
2026-02-18 Replace LED with Buzzer on GPIO 2 in Readme
2026-02-18 Create Código Arduino
2026-02-18 Create codigo arduino
2026-02-18 Add Arduino code to control LED with serial output close #1
2026-02-18 Create Código del MPU
    Mide la inclinación de la jabalina, el ángulo con respecto al suelo, para poder optimizar el lanzamiento del atleta
2026-02-18 Create Código MPU
    El código mide el ángulo de inclinación de la jabalina con respecto al suelo, con el sensor MPU 6050
2026-02-19 Add MPU6050 driver and clarify Unified Sensor description
    He agregado las librerías faltantes necesarias para el correcto desarrollo del proyecto, especialmente aquellas relacionadas con el control y la medición del ángulo de la jabalina mediante el sensor MPU6050.
2026-02-19 Create README.md for hardware datasheets and documentation
    Nueva información para el microcontrolador
2026-02-19 Update battery specifications in Readme.md
2026-02-20 Update hardware diagram and component references
    Actualización al diagrama de pines
2026-02-21 Fix mermaid diagram in Hardware README
    Updated the mermaid diagram to correct connections and add LED state indication.
2026-02-21 Rename LED status from 'LED ESTADO ON' to 'LED ON/OFF'
2026-02-23 feat(hardware): add initial PCB layout and schematics in KiCad 9
    Se cargan los archivos editables del diseño electrónico.
2026-02-23 Revert "Add files via upload"
    This reverts commit 024d3f9dc2c7c74ccd23ef5bf8b967a5092d4b80.
    [Primer_esquematico.kicad_pcb, Primer_esquematico.kicad_sch]
2026-02-23 Actualización
    Nuevos archivos con mejoras incorporadas
    [Primer_esquematico.kicad_pcb]
2026-02-25 Update Readme for XIAO ESP32C3 firmware details
2026-02-25 Fix pin labeling in configuration table
    Updated pin configuration table in Readme.md to correct pin labeling.
2026-02-26 Actualización diseño de PCB
    Finalización del diseño de la PCB.
    Se completaron los ajustes finales de ruteo, planos de cobre y reglas de fabricación.
    Se ejecutó el DRC obteniendo validación completa sin errores ni advertencias críticas.
    [Primer_esquematico.kicad_pcb, Primer_esquematico.kicad_sch]
2026-03-11 Se actualiza el diseño de la pcb
    [Primer_esquematico.kicad_pcb]
2026-03-22 Add README with LANCEA firmware explanation
    Added detailed explanation of the LANCEA firmware, including architecture, state machine, web server setup, calibration variables, and dependencies.
2026-04-06 Add README for design results and cost audit
    Added detailed documentation for design results, including schematics, mechanical dimensions, cost audit, and file references.
2026-04-06 Update project title in Readme.md
    Removed 'Emulador de Sistemas Dinámicos' from title.
2026-04-08 Actualización diagrama de conexiones
    Se actualiza el diagrama de conexiones, quitando los componentes que al final fueron innecesarios
2026-04-09 Actualización Diagrama de flujo
2026-04-09 Actualización de pcb
    Se adjunta el diseño final del PCB, el cual ha sido enviado a producción conforme a las especificaciones técnicas requeridas.
    [Primer_esquematico.kicad_pcb, Primer_esquematico.kicad_sch]
2026-04-27 Implement buzzer for optimal angle monitoring
    Added buzzer functionality to monitor angle during IDLE state.
    [LANCEA_WiFi.ino]
2026-04-27 Upgrade LANCEA_WiFi to version 7.1
    Updated version to v7.1 and modified battery monitoring features.
2026-04-29 Revise energy architecture and document current implementation
    Updated battery architecture details and added implementation phase information with images.
